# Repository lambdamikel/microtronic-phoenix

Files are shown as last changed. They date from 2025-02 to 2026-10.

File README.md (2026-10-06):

# microtronic-phoenix

## The Microtronic Phoenix Computer System - A  Microtronic Emulator Running the Original Firmware from 1981

### [Jason T. Jacques](https://jsonj.co.uk/): TMS1xxx emulator, prototype hardware design and breadboarding, refined Microtronic firmware dumping, authentic Microtronic firmware emulator running the original Microtronic firmware ROM with a TMS1600 emulator

### [Decle](https://forums.atariage.com/profile/46336-decle/): TMS1xxx firmware ROM dumping technology, TMS1xxx disassembler, expert technical advisor 

### [Michael A. Wessel](https://www.michael-wessel.info/): Arduino-based re-implementation of the Microtronic, first round of Microtronic firmware dumping, PCB design, software integration 

## About

*The *Microtronic Phoenix* represents a quantum leap in Microtronic
emulation.*

The Microtronic was an educational 4bit single-board computer system,
which was released in 1981 by the company [Busch
Modellbau](https://www.busch-modell.de) in West Germany: 

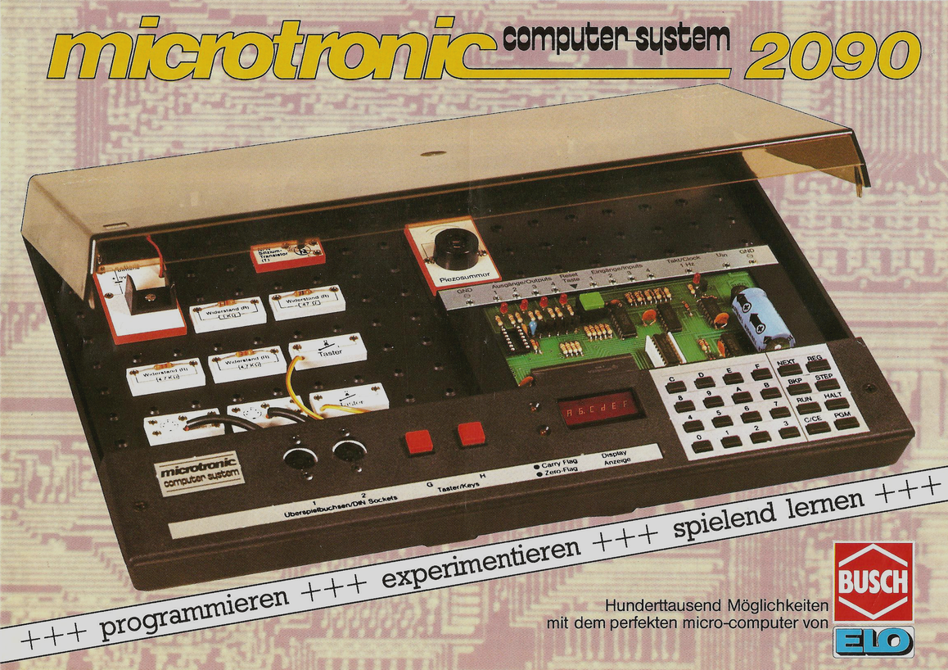
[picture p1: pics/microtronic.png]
Microtronic


Unlike [previous hardware
emulators](https://github.com/lambdamikel/Busch-2090) of the [1981
Busch 2090 Microtronic Computer
System](https://www.busch-modell.de/information/Microtronic-Computer.aspx
), the Phoenix emulator is the first emulator that is not only a
re-implementation of the Microtronic, but actually runs the original
TMS1600 firmware from 1981.

This breakthrough was made possible by a collaboration of
[Decle](https://forums.atariage.com/profile/46336-decle/), [Jason
T. Jacques](https://jsonj.co.uk/) and [Michael
Wessel](https://www.michael-wessel.info/), referred to as "the team"
in the following.

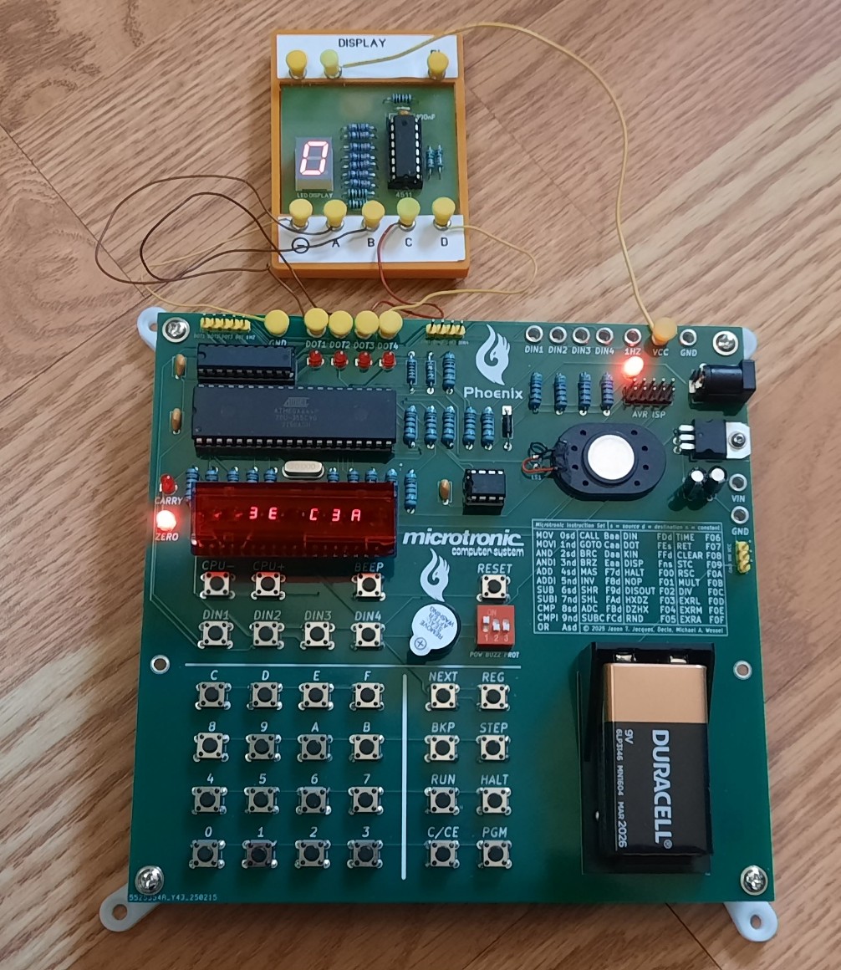
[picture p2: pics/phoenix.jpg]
Phoenix


This project is shared with the community to enable others to relive
and experience the original 1981 Busch Microtronic Computer System
in an as-authentic-as-possible way.  

## Latest News

- 10-05-2026: A Microtronic emulator that runs in your web browser is now online. It runs the original
  1981 firmware ROM on an emulated TMS1600, with the program RAM, display, keypad, inputs,
  outputs and 1 Hz clock modelled at pin level behind a console drawn from photos of the real
  machine, and it comes with a library of programs from the manuals. Everybody can now
  experience the Microtronic - there is nothing to build, and nothing to load or install on
  your computer: just open the page. Made with Claude Code (Opus 5.5).
  It uses the same firmware ROM as the Phoenix, with Jason's TMS1xxx emulator as the reference for the CPU.

    **[https://lambdamikel.github.io/microtronic-emulator/](https://lambdamikel.github.io/microtronic-emulator/)**

    Source code: [https://github.com/lambdamikel/microtronic-emulator](https://github.com/lambdamikel/microtronic-emulator)

  Microtronic Emulator

- 09-06-2026: The Busch 2094 "Computerspiele" booklet is now available in English as well -
  25 games and experiments to program yourself on the Microtronic 2090, from Black Jack and
  Roulette to a chess clock, a code lock and a prime-number benchmark:

    [https://github.com/lambdamikel/microtronic-2090-manuals-english](https://github.com/lambdamikel/microtronic-2090-manuals-english)

- 07-29-2026: A translated and updated all-in-one version of the article series about
  the German Educational Computer Systems from the 1980s (including the Microtronic and Phoenix) 
  I had written for the LOAD retro-computer magazine is available now: 
  [https://github.com/lambdamikel/german-educational-computers-of-the-80s](https://github.com/lambdamikel/german-educational-computers-of-the-80s)

- 07-09-2026: Part 2 of the Microtronic manuals in English is available now: 

    [https://github.com/lambdamikel/microtronic-2090-manuals-english](https://github.com/lambdamikel/microtronic-2090-manuals-english)

- 06-08-2026: Using Claude Code (Opus 4.8), we have translated the
first part of the Microtronic manuals to English! You can find
the PDF and HTML versions here:

    [https://github.com/lambdamikel/microtronic-2090-manuals-english](https://github.com/lambdamikel/microtronic-2090-manuals-english)

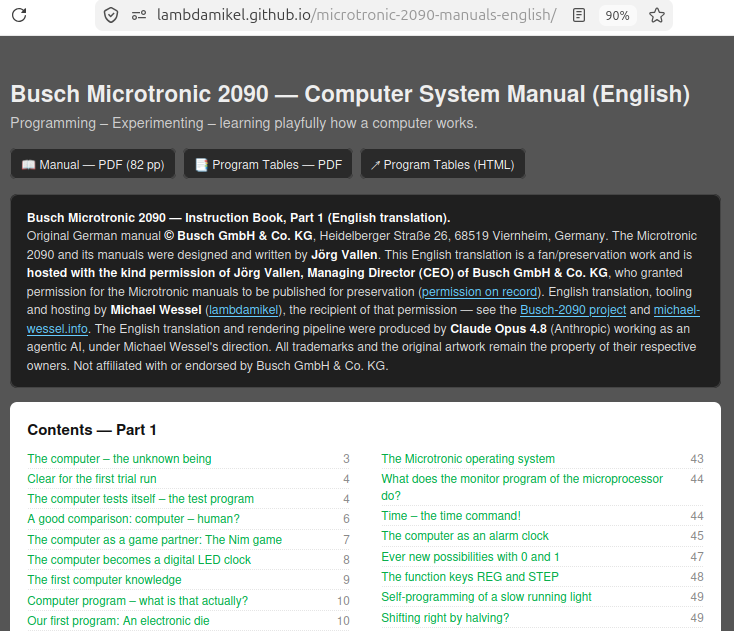
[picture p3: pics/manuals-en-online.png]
Translated Manual English
  

  Part 2 will follow soon, as well as the "Computerspiele" booklet. 

- 10-03-2025: I have written an article about the Busch Microtronic and its
emulators for the the "LOAD" magazine of the German organization for
the preservation of classic computers ("Verein zum Erhalt klassischer
Computer (VzEkC)") - you can download the [PDF of the "LOAD#11" free
of
charge](https://www.classic-computing.de/wp-content/uploads/2025/10/load11web.pdf).
There are also still print editions available for purchase.

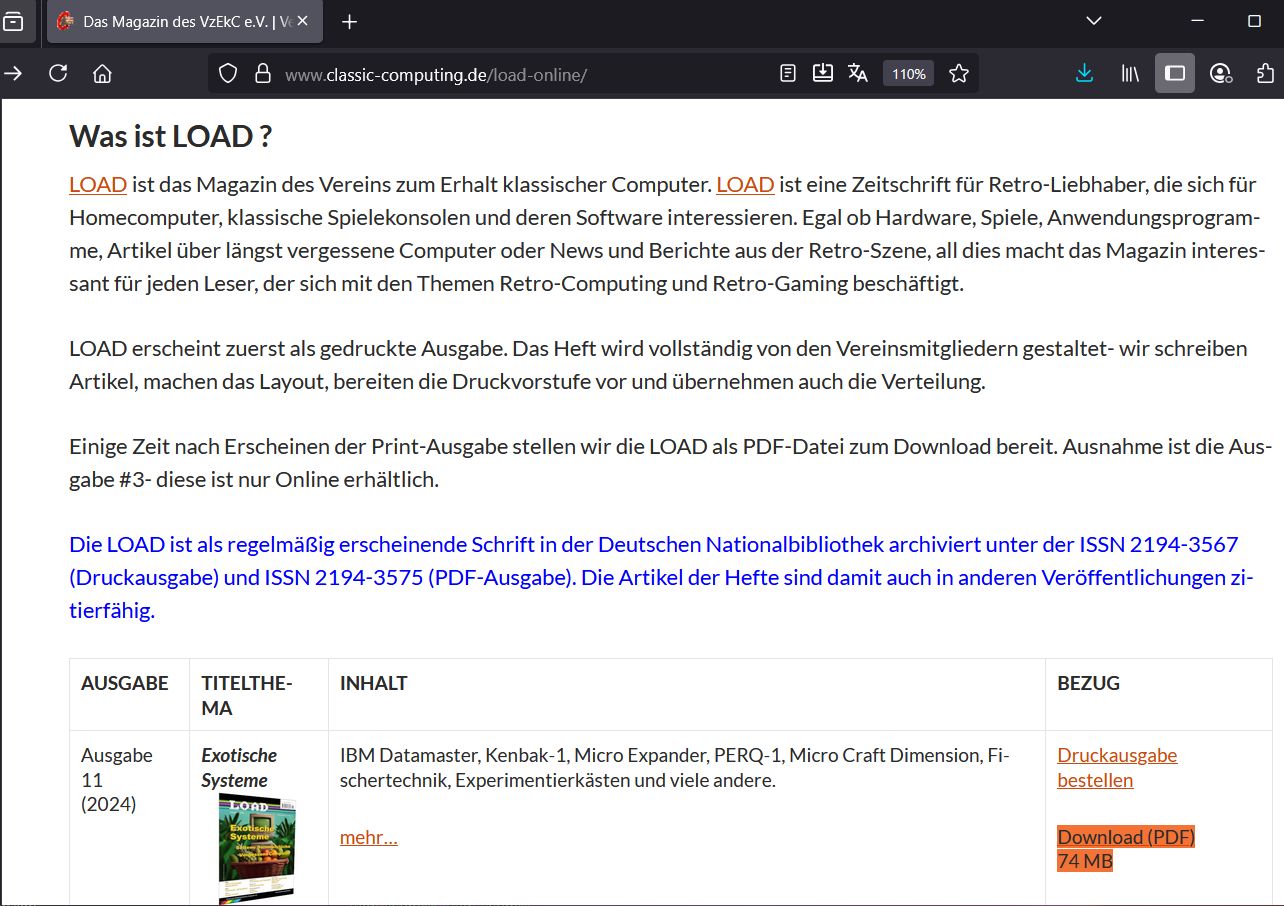
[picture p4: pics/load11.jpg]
Load 11 - A

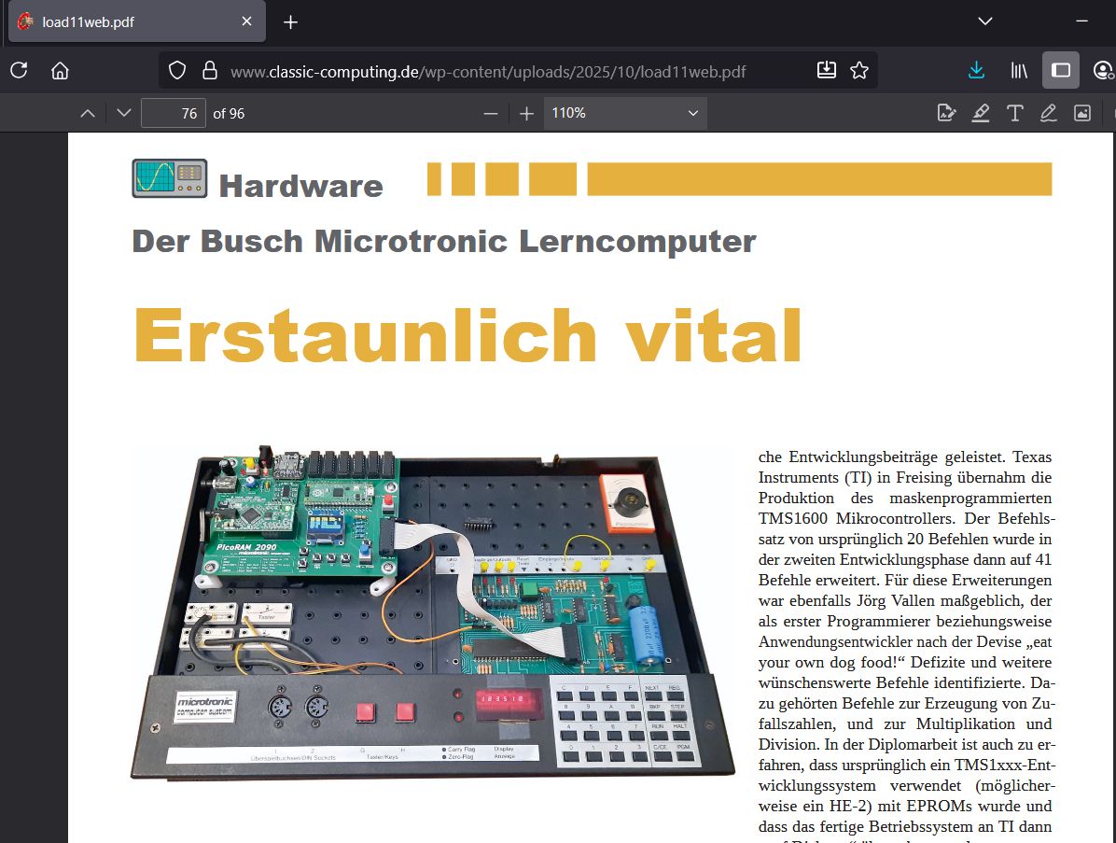
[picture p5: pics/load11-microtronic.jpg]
Load 11 - B


This article is the last in a series of three about the three major
educational computer systems available in the first half of the the
1980s in Germany: the Busch Microtronic, the Kosmos CP1, and the
Philips MasterLab MC6400. Busch played a pivotal role here, since they
released the first such system and literally created the market for
such systems in Germany. The overview and article covering the Philips
Masterlab can be found in ["LOAD#10" (free PDF
download)](https://www.classic-computing.de/wp-content/uploads/2024/10/load10web.pdf).
The Kosmos CP1 is also in "LOAD#11", together with the Microtronic
article.

- 08-23-2025: Phoenix enthusiast 
[`venice1200`](https://github.com/venice1200) determined how to
maximize the contrast of the 3661AS LED displays. He is using two
filters layered on top of each other - a black and a red one. The
contrast is stunning; see the following pictures for black+red, black
only, red only, and no filter:

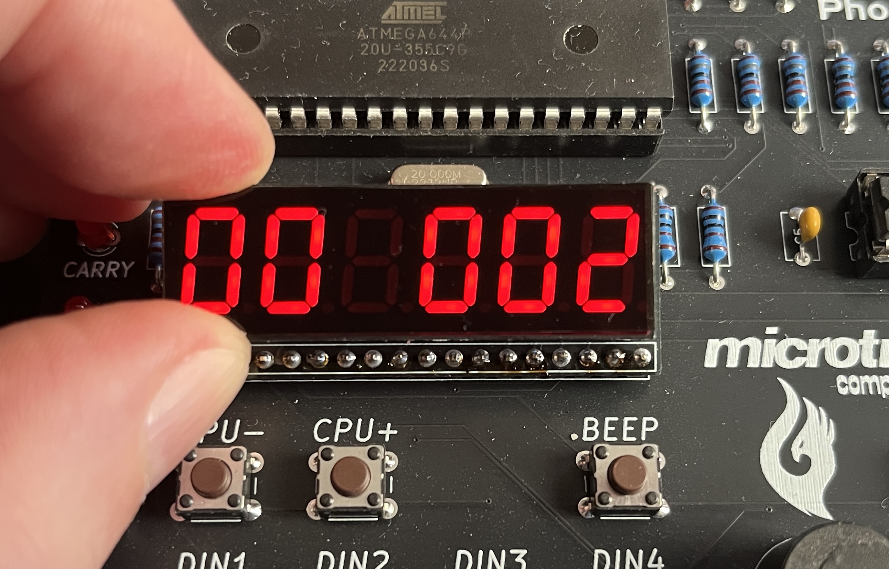
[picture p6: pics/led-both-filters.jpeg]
LED filter black and red


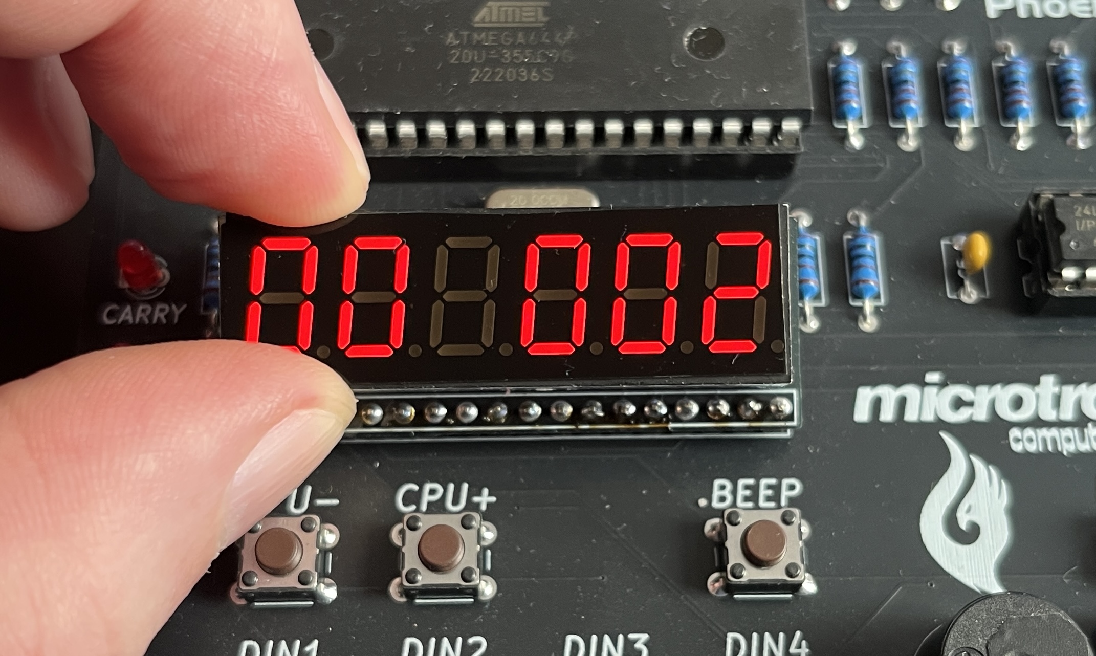
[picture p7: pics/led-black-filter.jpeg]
LED filter black


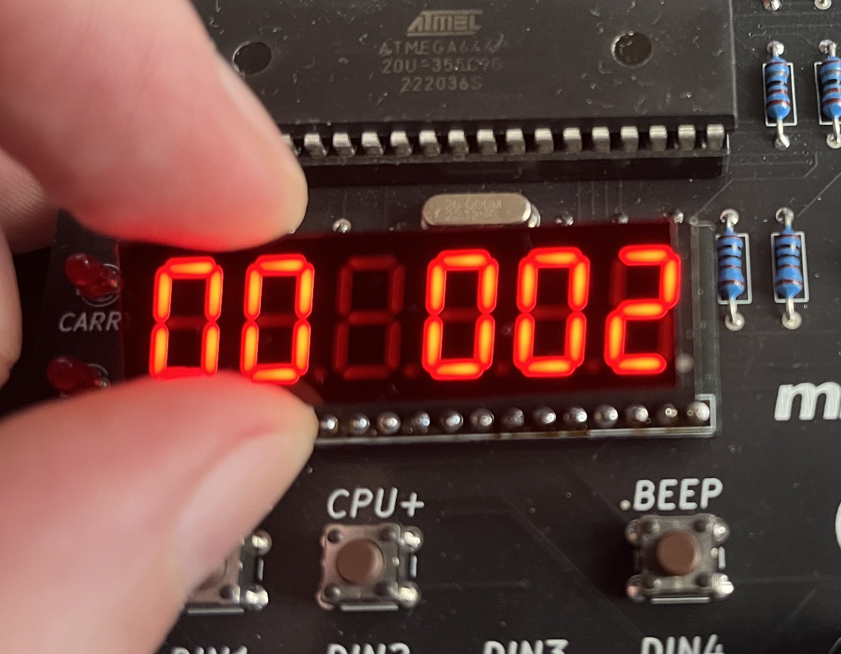
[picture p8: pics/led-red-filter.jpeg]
LED filter red


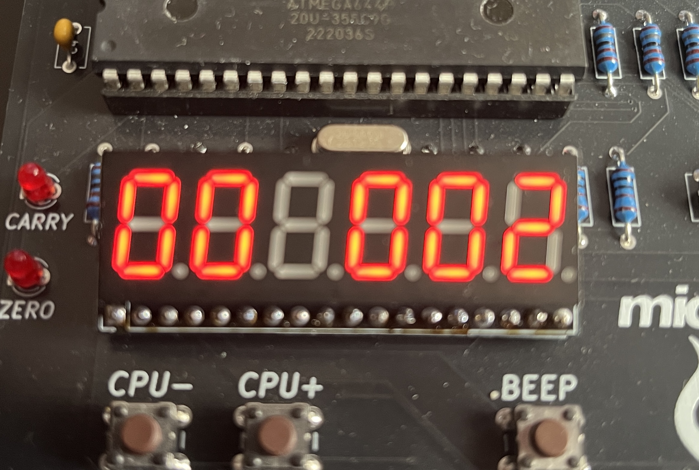
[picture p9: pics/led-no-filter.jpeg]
LED filter red


- 08-17-2025: [Github user
`venice1200`](https://github.com/venice1200) has created a [2095
cassette interface emulator
descendant](https://github.com/lambdamikel/microtronic-2095-arduino-emulator)
that allows for direct upload of programs to the Microtronic (or
Phoenix) via an Arduino-based USB connection from the PC (no SD card
required). On the PC side, a Python script is used to transfer MIC
files directly into a Microtronic / Phoenix running the `PGM 1`
program loader. An Arduino Nano is used for the USB connection. Check
out [the project
Github](https://github.com/venice1200/Retro/tree/main/Microtronic_Phoenix)
for more details about this great project. Thanks for sharing it with the
public, `Venice1200`!

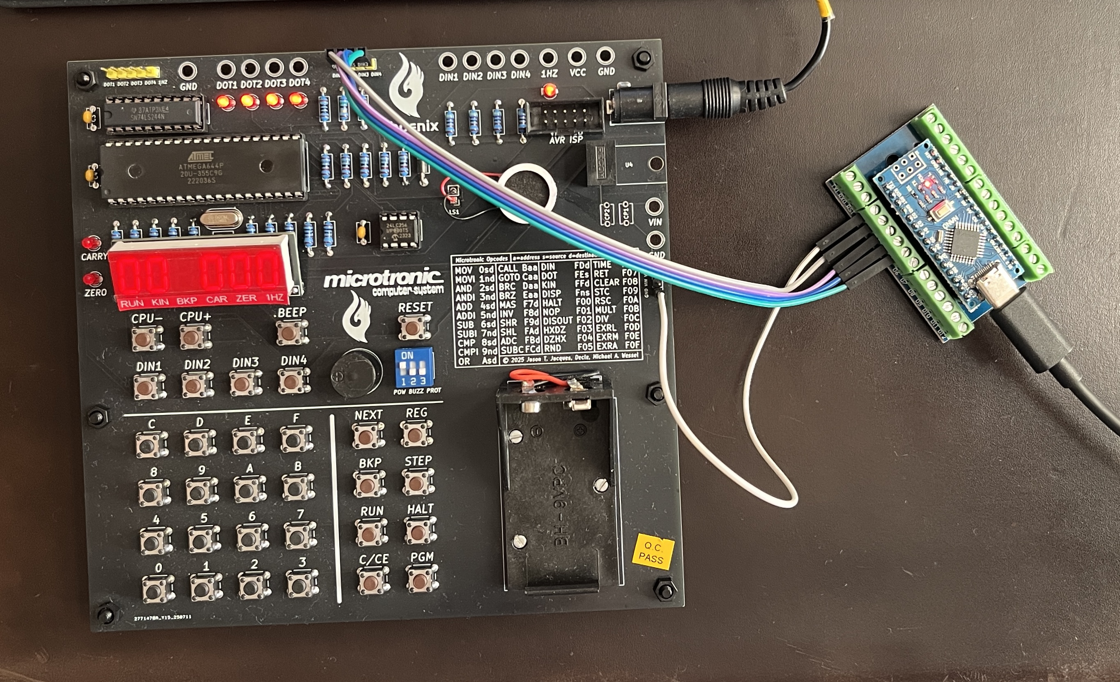
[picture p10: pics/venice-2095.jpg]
Venice1200 2095 Uploader


- 08-12-2025: In the meantime, a number of Makers have successfully
built their own Phoenix. I am sharing the builds of Venice and Morky
from the [Classic
Computing](https://forum.classic-computing.de/forum/index.php?thread/34844-microtronic-phoenix-edition/&pageNo=1)
Forum here:

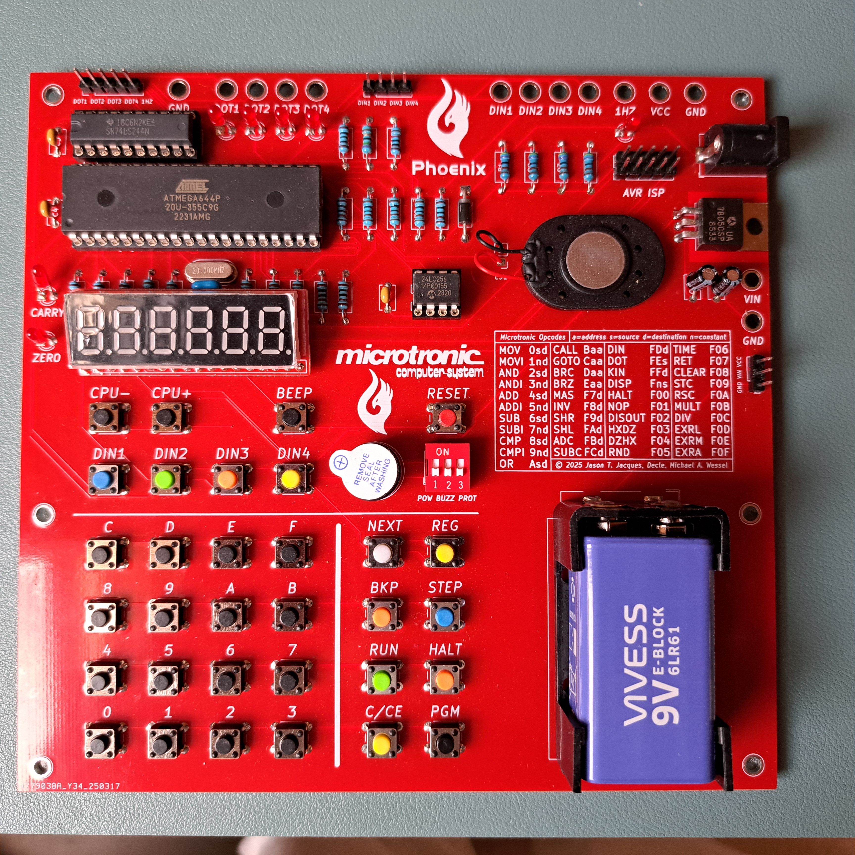
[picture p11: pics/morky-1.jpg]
Morcky


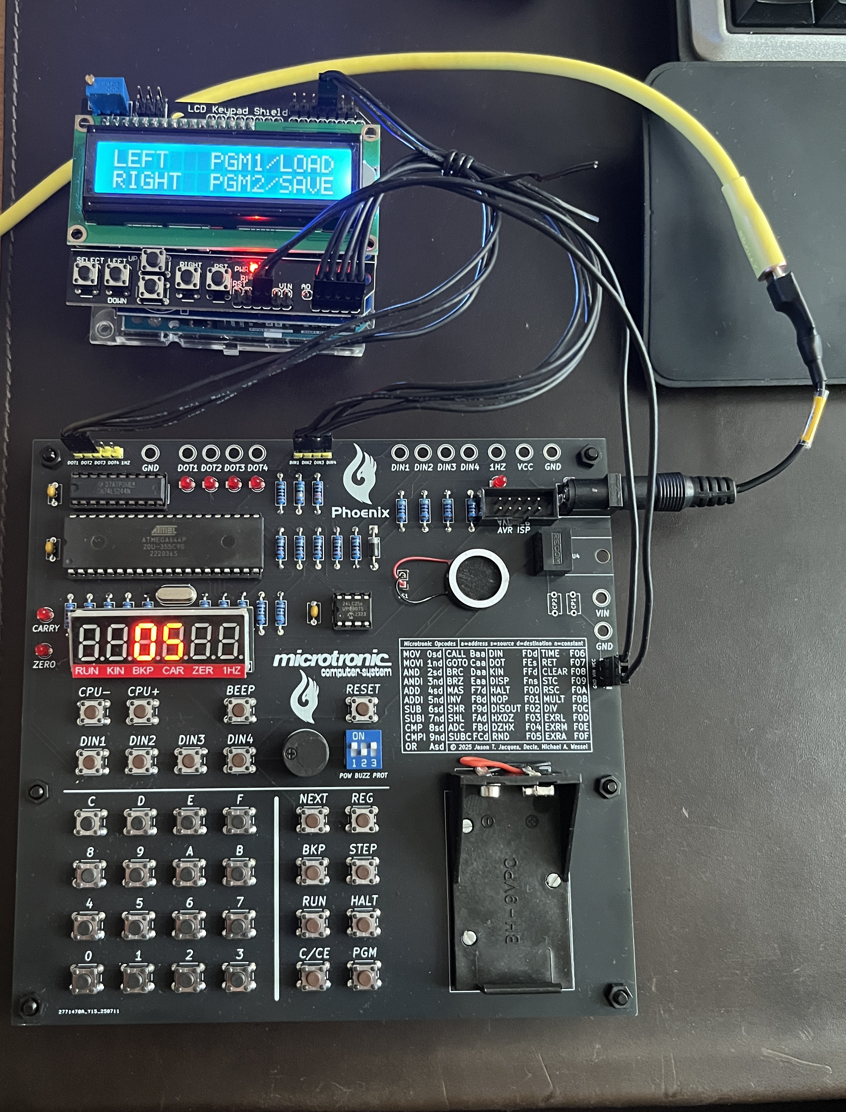
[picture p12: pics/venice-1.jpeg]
Venice 1


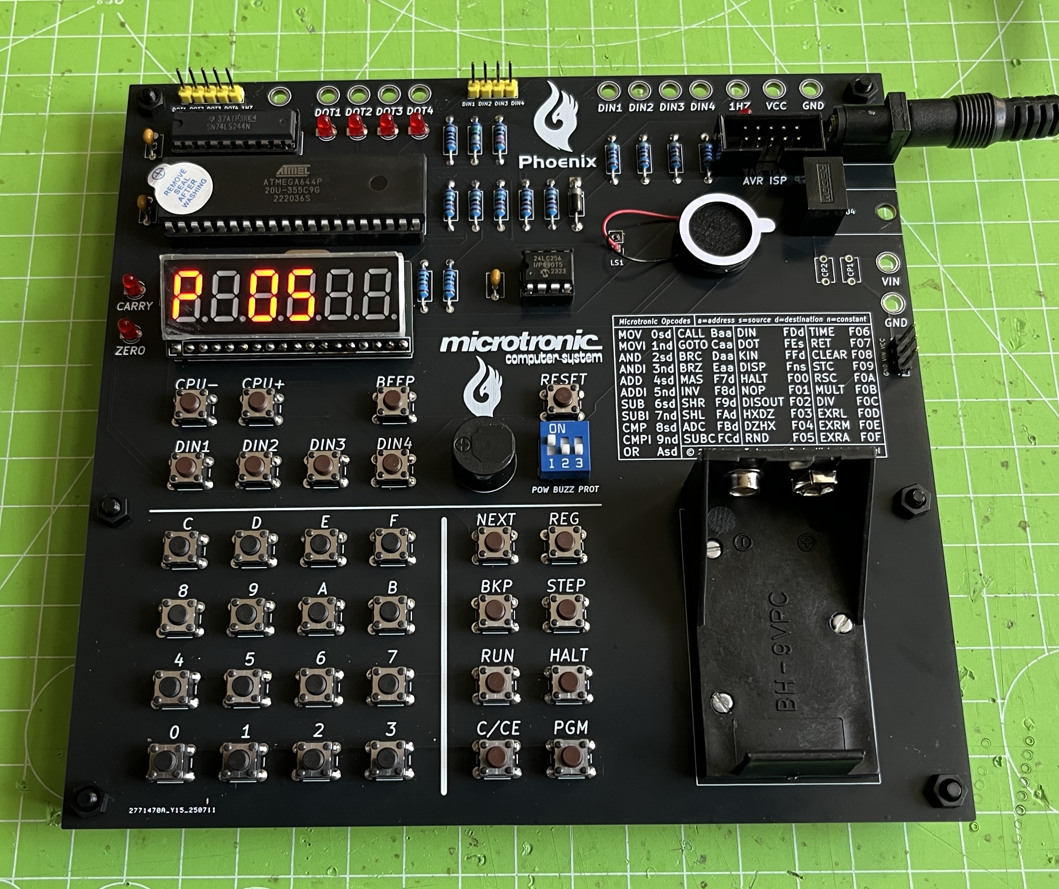
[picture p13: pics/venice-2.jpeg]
Venice 2


- 04-17-2025: [Hackster.io](https://www.hackster.io/news/the-four-bit-busch-microtronic-lives-again-as-the-microtronic-phoenix-complete-with-original-rom-2a5c7ccecba7) has also featured the Microtronic Phoenix project - thanks to Gareth Halfacree!

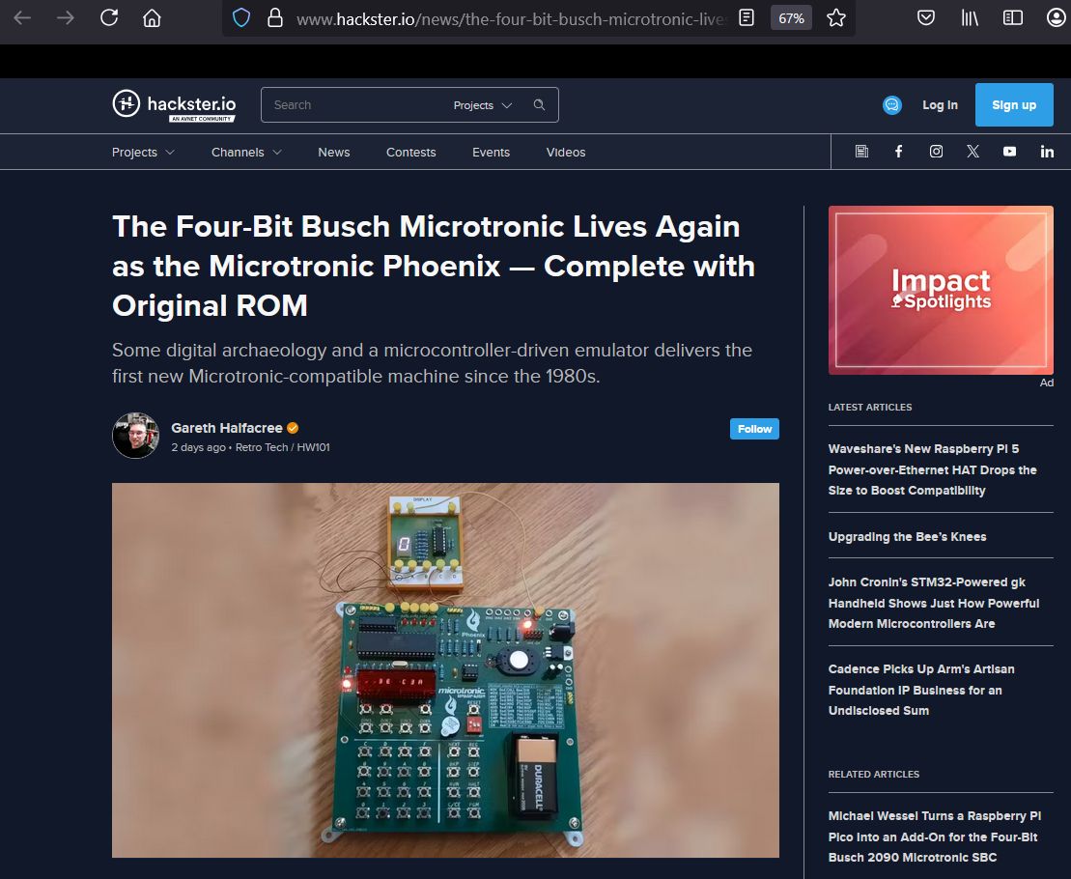
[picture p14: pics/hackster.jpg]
Hackster
  

- 04-14-2025: Phoenix in the News: [Microchip
  Makes](https://x.com/MicrochipMakes/status/1911773123323515386)
  posted about our project, and the Phoenix is also on the [Hackaday
  front page](https://www.hackaday.com) as a "Featured Project"

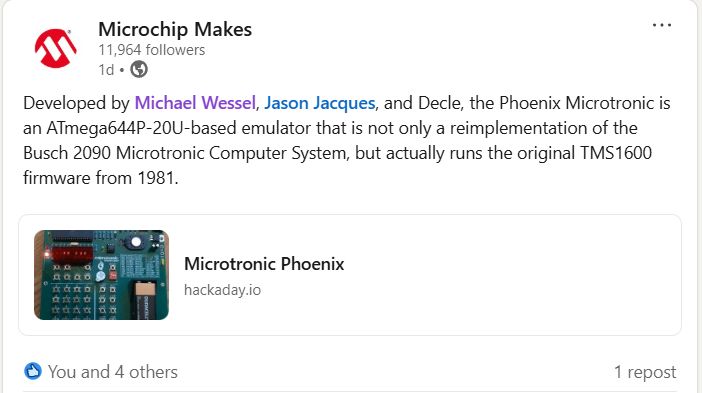
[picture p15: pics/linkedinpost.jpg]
Linkedin
  

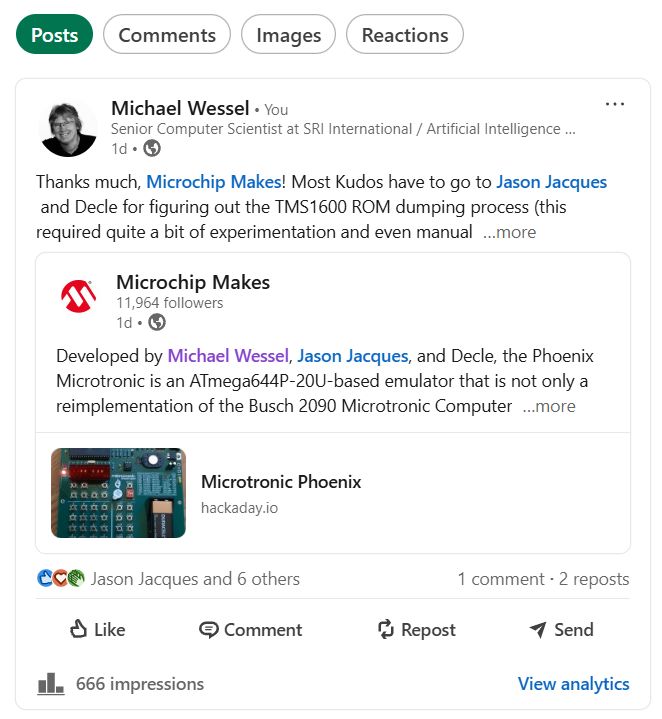
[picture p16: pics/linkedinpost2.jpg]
Linkedin 2
  

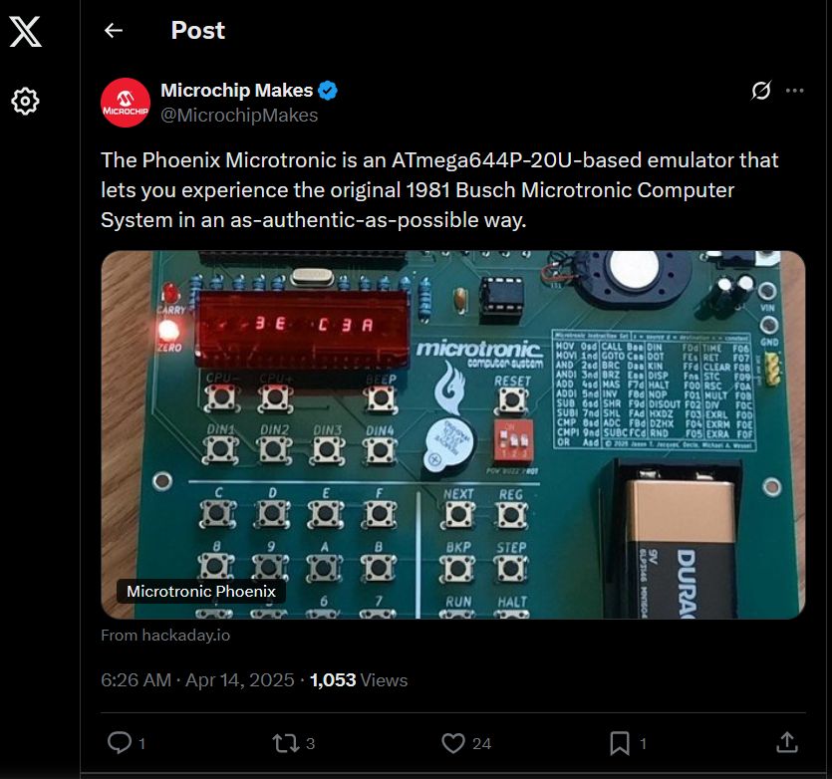
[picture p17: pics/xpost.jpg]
XPost
  

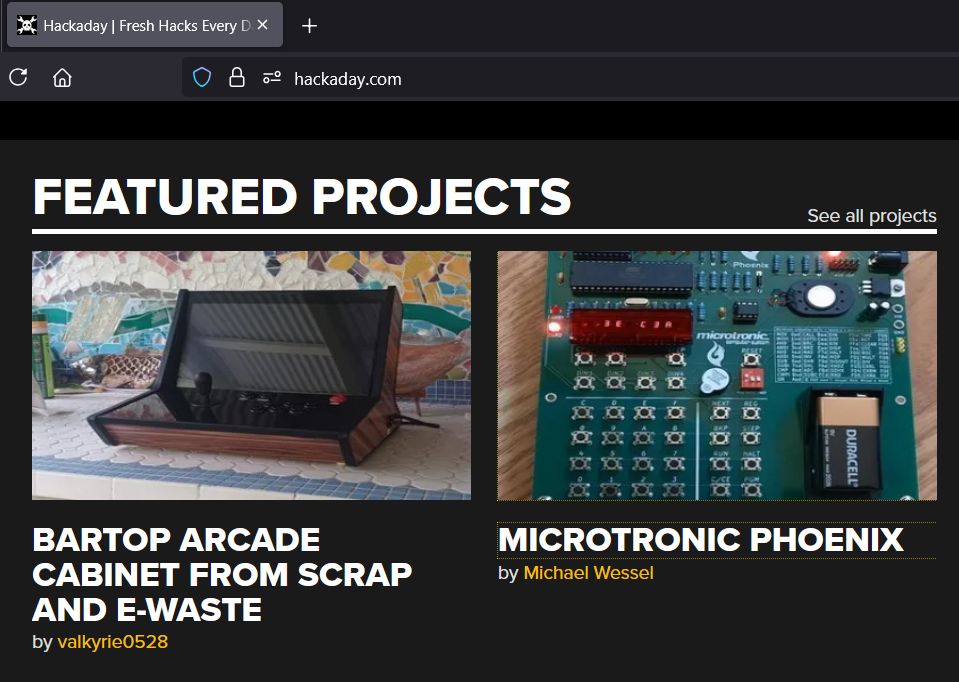
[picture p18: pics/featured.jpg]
Hackaday Featured
  

- 04-12-2025: All Firmware variants uploaded ("Phoenix", "Neo Only", "Phoenix Only"). 

- 02-22-2025: "Neo Only" firmware uploaded. 

## Background & Genesis

The Microtronic is powered by a mask-programmed Texas Instruments 4bit microcontroller,
the TMS1600.

Until now, an authentic Microtronic emulator was impossible as the
official firmware had been lost to history, and there was no
documented procedure for reading out ("dumping") a TMS1600 firmware
ROM. Firmware ROMs of related TMS1xxx devices (e.g., the SIMON game,
TI calculators, and the Science Fair Microcomputer Trainer) had been
retrieved in the past, but the process usually involved [destructive
die-decapping](https://seanriddle.com/decap.html).

More recently, an alternative to destructive chip decapping was
discovered for dumping the ROM of the [1985 Radio Shack Science Fair
Microcomputer
Trainer](https://hackaday.io/project/194876-exploring-the-science-fair-microcomputer-trainer).
This process utilizes an Arduino for [putting the TMS1xxx into the
so-called *test
mode*](https://hackaday.io/project/194876-exploring-the-science-fair-microcomputer-trainer/log/227981-dumping-the-tms1100),
which then allows download of the firmware ROM over a serial interface. 

After a lot of trial-and-error, the team finally succeeded in April
2024 in retrieving the Microtronic firmware ROM, hence opening up the
avenue of re-creating the original Microtronic on modern hardware. The
process is described
[here](https://hackaday.io/project/197415-microtronic-firmware-rom-archaeology)
and, much more detailed and technically accurate,
[here.](https://jsonj.co.uk/project/microtronic/)

After Decle and Michael had succeeded in enabling the TMS1600 test
mode (this process was nowhere documented on the Internet back then),
and succeeded in downloading a first version of the Microtronic ROM,
Jason then took the lead and analyzed and double checked it, corrected
some errors by hand (despite all our efforts, the retrieved firmware
still contained some ambiguity!), and, for the first time in history,
created an [ATmega-based breadboard Microtronic running the original
firmware](https://jsonj.co.uk/project/microtronic/#the-breadboard-microtronic)
on his TMS1xxx emulator!

Jason's work of curating the firmware and his TMS1xxx Microtronic
breadboard hardware emulator opened the avenue of recreating a
retro-authentic new version of the Microtronic on modern hardware,
running the original 1981 firmware ROM on a TMS1600 emulator on an
Arduino / ATmega.  **We are hence calling this new Microtronic
hardware emulator the Phoenix.**

## Phoenix Overview 

The Phoenix board uses an ATmega 644P-20U clocked at 20 MHz, a 24LC256
EEPROM, and an 74LS244 in an abundance of pre-caution for connecting
the ATmega's GPIOs to the external world of Microtronic INPUT / OUTPUT
ports.

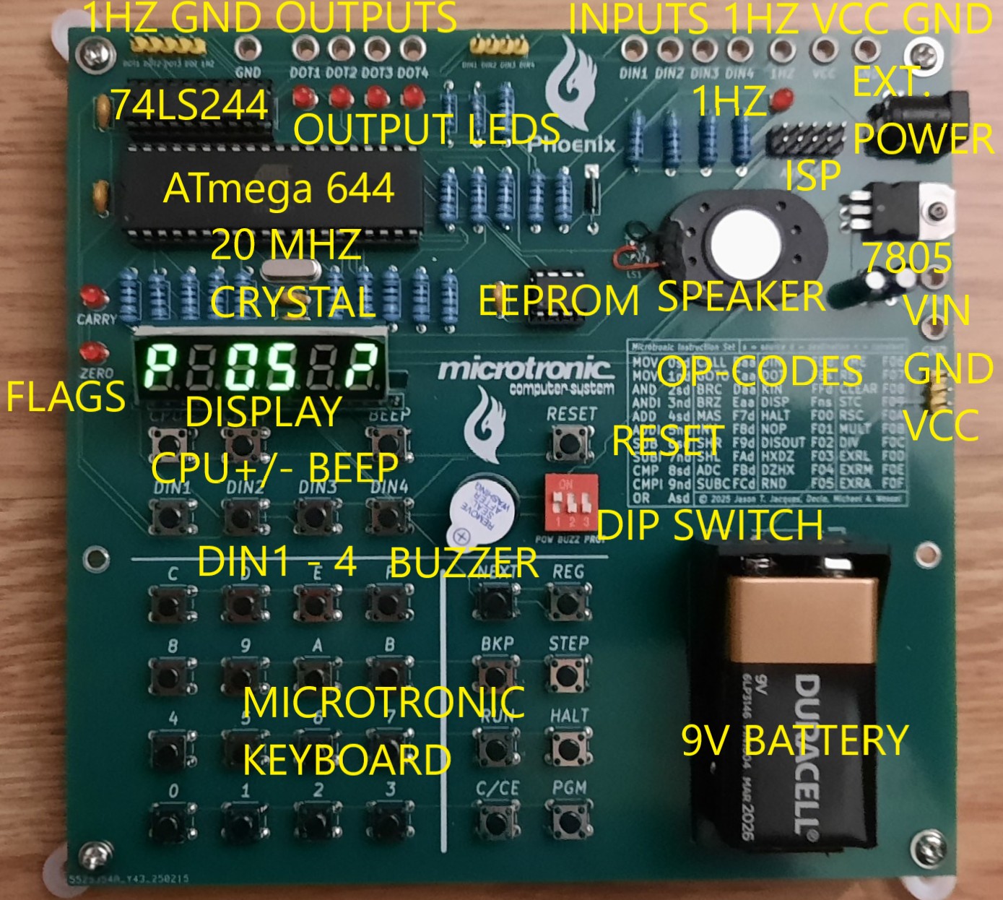
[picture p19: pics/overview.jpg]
Phoenix Overview


The three different Phoenix firmwares are provided as Arduino folders
/ "sketches". See below for descriptions of these three different
variants. The [Arduino Legacy IDE IDE
1.8.19](https://www.arduino.cc/en/software) in combination with
[MightyCore](https://github.com/MCUdude/MightyCore) are used for
firmware compilation and uploading onto the Phoenix board over the ISP
header (see below).

One can either use an original 6digit 7segment (or really 8segment if
we include the individual decimal dots for each digit) TIL 393-6
retro-authentic bubble LED display from Texas Instruments, or the NSA
1166 from National Semiconductors as shown in the above picture. As
these are hard to come by, it is also possible to use a CL3061AG or
SH3661AS modern LED display and an adapter (provided here as well): 

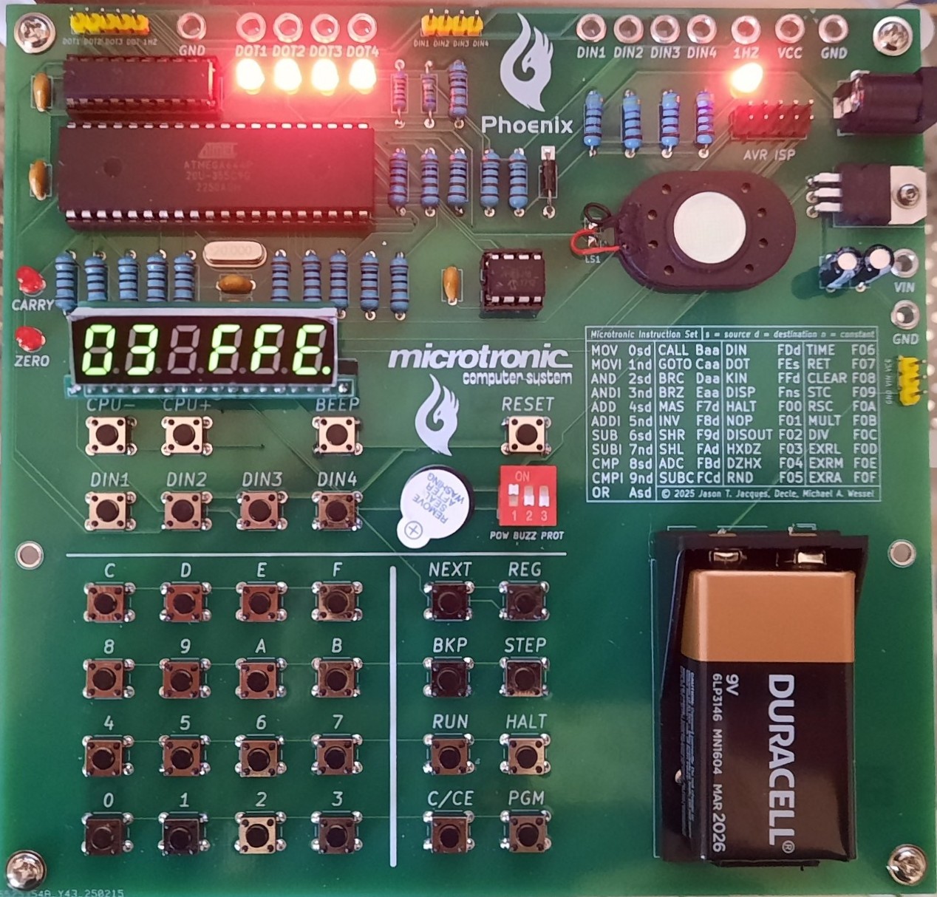
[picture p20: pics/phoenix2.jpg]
Prototype with Display Adapter


## Original Microtronic Firmware

The original Microtronic firmware can be found [here](microtronic-firmware/).

The files are provided for reference and interest only, and are not
required for programming the Phoenix firmware. The Phoenix firmware
sketches are self-contained, and the [Microtronic firmware ROM
image](microtronic-firmware/microtronic.bin) is embedded on the
code-level (instead of on the file level) in them.

## Emulation Modes - NEO vs. PHOENIX 

The Phoenix offers two Microtronic emulation modes:

- the **Neo Mode** is based on [Michael's Arduino-based re-implementations of the Microtronic
in C](https://github.com/lambdamikel/Busch-2090), 
and similar in spirit to the [Retro-Authentic Bubble LED Display Microtronic.](https://hackaday.io/project/180252-a-retro-authentic-microtronic-rc-202110-winner) 
- the **Phoenix Mode** is based on [Jason's breadboard Microtronic running the original Microtronic ROM on his TMS1xxx emulator.](https://jsonj.co.uk/project/microtronic/#the-breadboard-microtronic)

The Phoenix is offered with *three different firmwares:*

- [Neo Only:](microtronic-phoenix-neo-only/) only offer the Neo Mode
  (describe below).

- [Phoenix Only:](microtronic-phoenix-only/) only offer the Phoenix
  Mode (described below).

- [Combined:](microtronic-phoenix/) **should be the default**; this
offers both modes; upon boot or reset (via the `RESET` button), the
user can select the firmware of choice for the "**P**hoenix **OS**" -
"**P OS ?**"; here, push **1** for NEO, and **2** for PHOENIX:

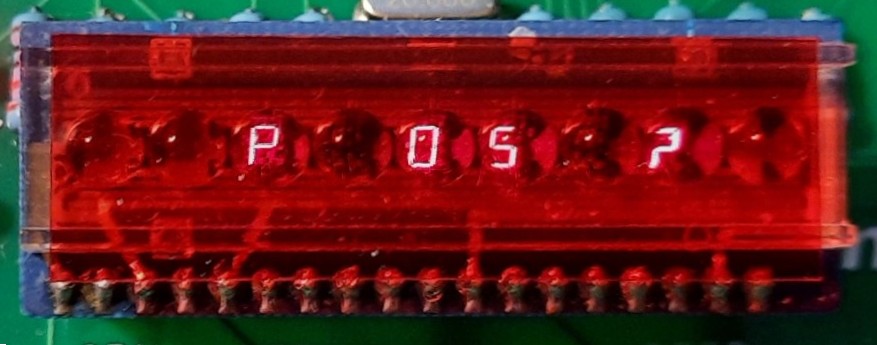
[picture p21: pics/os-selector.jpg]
Prototype
  

### Common Hardware Features

The Phoenix board offers a number of additional hardware features, in
particular, an on-board buzzer, and 4 additional push buttons `DIN1`
to `DIN4`. 

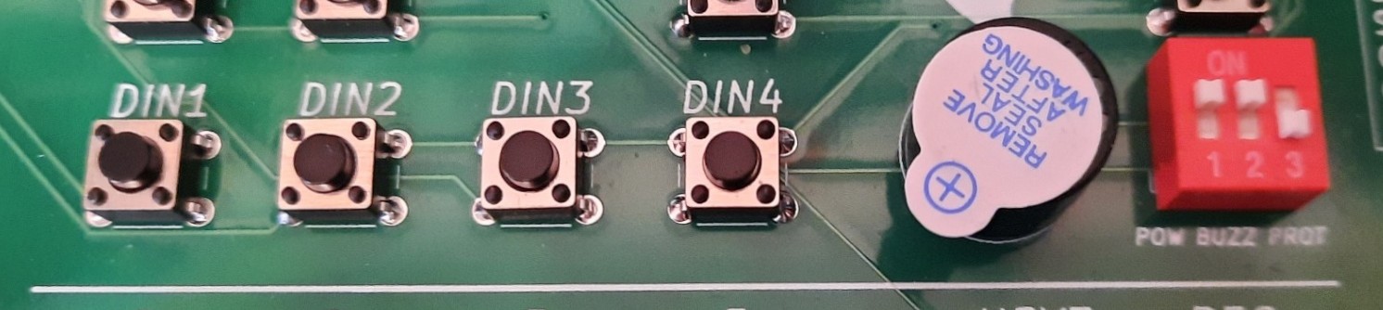
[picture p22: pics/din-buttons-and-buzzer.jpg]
DIN Buttons


The original Microtronic came with a buzzer as well as two push button
("G" and "H") which, in many experiments, where connected to the
digital inputs (DIN), and the buzzer was usually connected to either
DOT Output 1 or 4, as shown in this picture: 

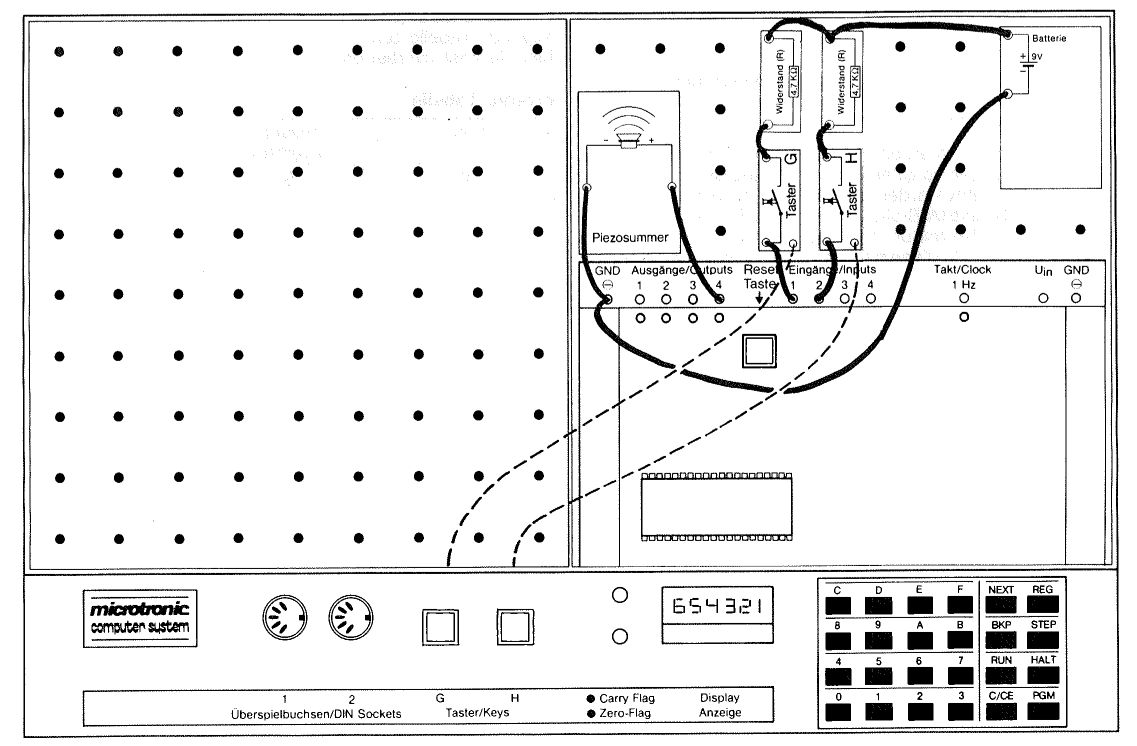
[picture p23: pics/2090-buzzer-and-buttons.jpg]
Microtronic Console
 

The Phoenix board hence offers these on-board, for convenience (plus
two extra-buttons, `DIN3` and `DIN4`). The on-board buzzer can also be
disconnected via the `BUZZ` DIP switch.

Moreover, both the Neo and Phoenix mode support the CPU speed buttons:
emulation speed can be decreased (`CPU-`) and increased ( `CPU+`). The
`RESET` button works in both firmwares as well: 

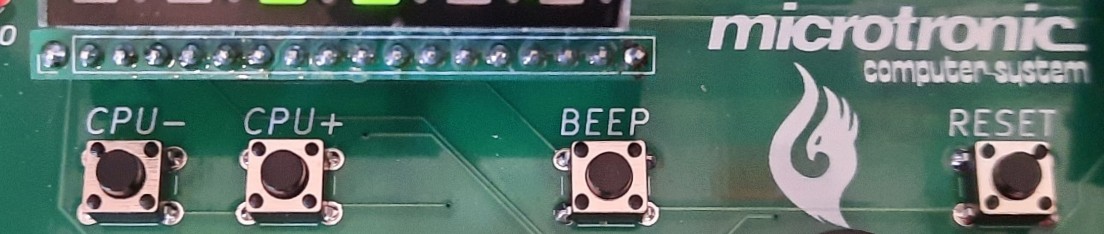
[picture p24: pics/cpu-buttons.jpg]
CPU and Reset Buttons
 

### Neo Mode

In Neo Mode, the hardware emulator has access to the additional
hardware features on the board: 

- a **speaker** for sound output: like in previous Microtronic
emulator versions, [vacuous op-codes are used as sound
op-codes.](https://github.com/lambdamikel/Busch-2090?tab=readme-ov-file#emulator-sound-output-and-sound-instructions)

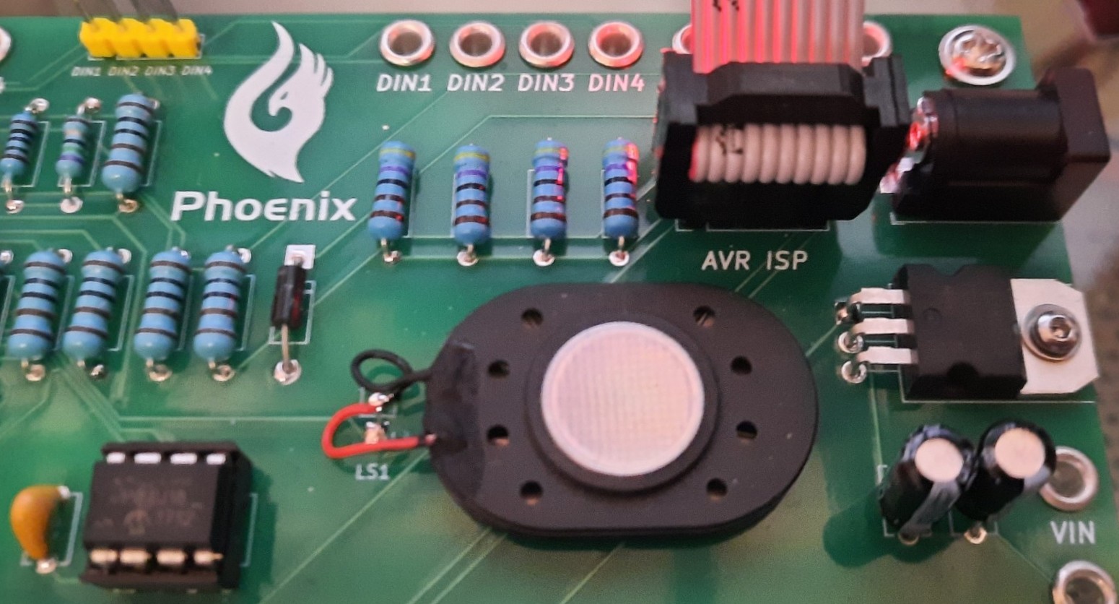
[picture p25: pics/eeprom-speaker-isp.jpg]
Speaker and EEPROM
  

- an 256 kBit 24LC256 **EEPROM** for mass-storage of Microtronic RAM
  dumps, instead of the 2095 cassette interface. The EEPROM has enough
  space for 42 complete memory dumps. It is accessed via `PGM 1` and
  `PGM 2`. **NOTE: to save to or load from the EEPROM, the `PROT`ect
  switch must be in OFF position!**. Turn the `PROT`ect switch back on
  after EEPROM operation. See this picture:

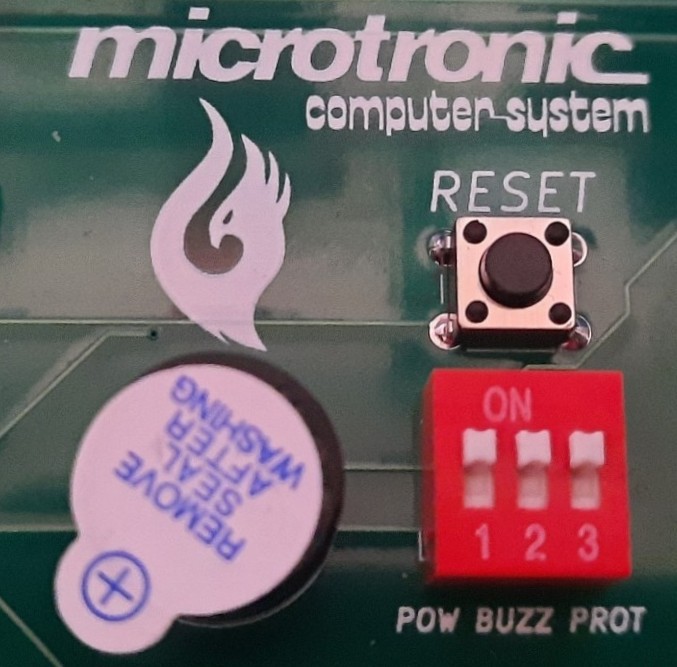
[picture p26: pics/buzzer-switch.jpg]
DIP SWITCH
  

  **Please note that the `CARRY` LED will not work properly with the
  `PROT` switch in OFF position.**

- the speaker is also used for key beeps; the `BEEP` button is used to
  turn on or off key beeps.

- 7segment status display: with a suitable 7segment LED display that
offers control over the individual digit decimal dots (the NSA 1166
from National Semiconductors does not, but the TIL 393-6 from TI
does), the 6digit 7segment display also indicates the CPU emulator
state, as well as the `CARRY`, `ZERO`, and `1 Hz` CLOCK flags (in
addition to the LEDs on the board). The `BEEP` button is used to turn
on or off this status display - this is a feature which is independent
of the display's main function as the primary visual user interface. 

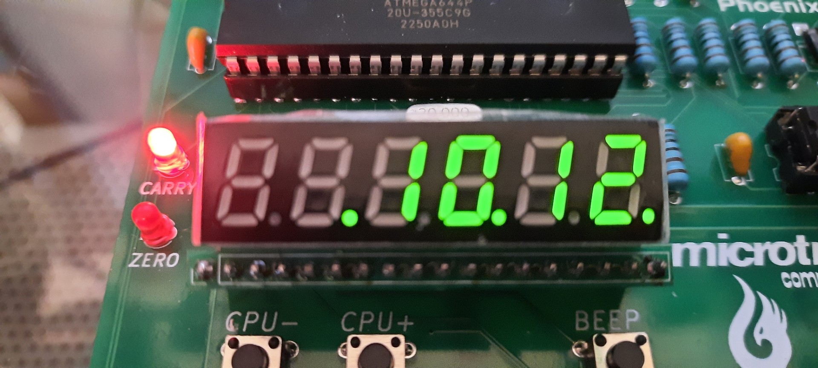
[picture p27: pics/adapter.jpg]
Status DOTs
   

  The status decimal dot LEDs are, from left to right: 
  - Dot on digit 6: program running
  - Dot on digit 5: requesting user input (`KIN` active) 
  - Dot on digit 4: breakpoint active (`BKP`) 
  - Dot on digit 3: `CARRY` flag
  - Dot on digit 2: `ZERO` flag  
  - Dot on digit 1: `1 Hz` clock

  The NSA 1166 only supports control of the decimal dot for digit 3;
  hence, only the `CARRY` flag can be visualized with it.

  It should again be noted that, if in OFF position, the `PROT`ect
  switch disables the main `CARRY` flag LED (left to the 7segment
  display). However, utilizing the second `CARRY` flag indicator (the
  decimal dot of digit 3) we can hence leave the `PROT`ect switch in a
  permanent OFF position without loosing `CARRY` flag visibility. And,
  this also works with the NSA 1166.
  
  Also note that two NSA 1166 / TIL 393-6 adapters are provided in this
repo (see picture above): one for the [CL3061AG display](gerbers/gerbers-til-display-adapter.zip), and one for the [SH3661AS display](gerbers/gerbers-til-display-adapter2.zip). The bubble LED display are getting very hard to source these days.    

The Neo firmware contains the following `PGM` programs; these are: 

- ``PGM 1`` : Load program from EEPROM
- ``PGM 2`` : Save program to EEPROM 
- ``PGM 3`` : Set clock 
- ``PGM 4`` : Show clock 
- ``PGM 5`` : Clear memory
- ``PGM 6`` : Load ``F01`` (NOPs) into memory 
- ``PGM 7`` : Nim Game 
- ``PGM 8`` : Towers of Hanoi (up to 4 disks - see https://github.com/lambdamikel/towers-of-hanoi) 
- ``PGM 9`` : Electronic Die (Microtronic Manual Vol. 1, page 10) 
- ``PGM A`` : Three Digit Counter (Microtronic Manual Vol. 1, page 19) 
- ``PGM B`` : Moving LED Light (Microtronic Manual Vol. 1, page 48) 
- ``PGM C`` : Digital input DIN Test Program
- ``PGM D`` : Lunar Lander (Moon Landing) Game (Microtronic Manual Vol. 1, page 23) 
- ``PGM E`` : Prime Numbers ("Computerspiele 2094", page 58) 
- ``PGM F`` : 17+4 BlackJack Game ("Computerspiele 2094", page 32) 

Note that, on the original Microtronic and hence in Phoenix mode, `PGM
0` performs a self-test, and `PGM 1` and `PGM 2` are used to access
the 2095 Cassette Interface, which is currently not supported by the
Phoenix board. Instead, `PGM 1` and `PGM 2` are used to access
the EEPROM. 

Moreover, there are no `PGM` demo programs `8` to `F` in Phoenix mode.

### Phoenix Mode

In this mode the system behaves identical to the original Busch
Microtronic, executing the original Microtronic firmware using Jason's
TMS1600 emulator! Hence, [the original Busch
manuals](https://github.com/lambdamikel/Busch-2090/tree/master/manuals)
are the best documentation. It is currently only available in German,
but contemporary GenAI technology will likely have little problems
translating it to English.

Note that the **Phoenix runs ~ 30 to 40 % faster than the original
Microtronic,** but still **significantly slower than in Neo mode at
max speed.**

The digital inputs and outputs are fully functional, and even the
original `PGM 1` and `PGM 2` firmware ROM programs are working.
They can be used for accessing the [2095 cassette interface
emulator.](https://github.com/lambdamikel/microtronic-2095-arduino-emulator)
Here is [a video demonstrating operation of the original 2095 cassette
interface](https://youtu.be/7KmG64e4DPE), and [a 2095 emulator
tutorial by "Mein Elektronic Hobby" (in
German)](https://youtu.be/0MPBtOWTzlk) for first steps with
`PGM 1` and `PGM 2`.

Moreover, unlike the Neo version, the self-check `PGM 0` firmware ROM
program is functional, and can be used for checking proper operation
of the system, see [User Manual Vol. 1, pp. 5 -
6](https://github.com/lambdamikel/Busch-2090/blob/master/manuals/anl2090-1.pdf])
(note that a test harness is required for `PGM 0` operation).

Please note that the `RESET` button is supported, but **the `CPU-`,
`CPU+`, and `BEEP` buttons are non-functional in this mode. They only
work in Neo mode.**

### Combined Mode

**This should be considered the default firmware - it combines the features
of the Neo and the original firmware.** 

In addition to the individual features of the Phoenix and Neo modes as
just described, the combined mode realizes one more *essential
synergistic feature* making this mode more than the sum of its
individual modes: **shared Microtronic program memory!** In this
way, the Phoenix mode can take advantage of the additional features
of the Neo mode, like EEPROM access or additional PGM demo programs. 

For example, to load a program from EEPROM into Phoenix, we would

1. start in Neo mode, load a Microtronic program from EEPROM via `PGM 1`.
2. switch to Phoenix mode: push `RESET`, enter `2`.
3. the same program is now available in Phoenix mode.

In general, all changes made to the current Microtronic program in memory
will always be available to the other mode as well. 

You can also load one of the additional demo `PGM`s easily into Phoenix mode.

1. start in Neo mode, load a `PGM` ROM program, for example, "17Add4 Blackjack":
`HALT-PGM-F`. 
2. switch to Phoenix mode: push `RESET`, enter `2`.
3. play Blackjack in Phoenix mode: `HALT-NEXT-0-0-RUN`. 

## The Phoenix Board

In principle, the Phoenix is a one-chip design - everything is driven
by the ATmega 644P-20U, even the display. The 24LC256 EEPROM is
optional; the machine will also work without it. The 74LS244 is used
to electrically decouple the Microtronic inputs and outputs from the
ATmega and make it more robust for experimentation in case an
experiment goes awry. It is cheaper and easier to replace the 74LS244
than the ATmega.

### Phoenix Power Supply Options 

There are four options of powering the Phoenix board: 

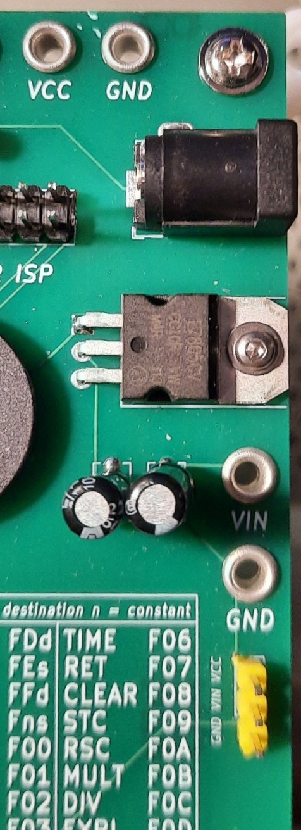
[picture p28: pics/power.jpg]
Power Supply Options
 

1. With a 9V block battery. The power switch must be in ON position.

2. With an external 9V to 15V DC power supply over the standard
center-positive 2.5 mm power jack. A 0.5A supply is sufficient.
The power switch must be in ON position. 

3. Over the `VIN` and `GND` rivet sockets. The power switch must be in ON
position.

4. Over the AVR ISP header. **In this case, the power switch should be
in OFF position!**

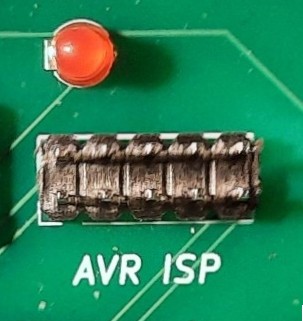
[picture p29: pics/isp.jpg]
ISP Power
 

For options 1 to 3, a 7805 voltage regulator is used to down-regulate
the input voltage to the required 5V level.

Note that it is not necessary to remove the 9V battery from the
Phoenix if another power supply option is used - a standard 1N4001
rectifier diode prevents all current flow (and hence "charging"
attempts) into the 9V battery from the external power supply.

### Phoenix `VCC`, `VIN`, and `GND` Outputs

For powering electronics experiments with Busch electronics kits
and/or breadboards, the Phoenix board can supply 5V via `VCC` as well
as 9V from the battery (or any voltage that the external power supply
provides) via `VIN`. The power switch must be in ON position to access
these voltages. Both `VCC` and `VIN` are available from rivet sockets
as well as pin headers.

Power Output Options 

### Display & Flags

The 6digit 7segment LED display is the primary visual output channel
of the Microtronic. It should be fitted with a red (or green) lens
filter to enhance the contrast.

Left of the display are the `CARRY` and `ZERO` flags.  Note that the
`CARRY` LED will only function if the `PROT`ect DIP switch is on `ON`
position. However, the NEO mode can utilize the decimal dot of the
third display digit from the right to visualize the `CARRY` flag as
well.

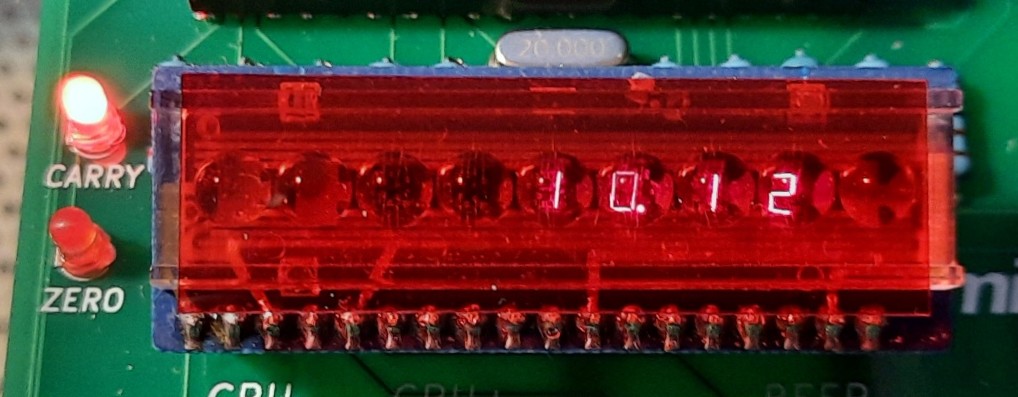
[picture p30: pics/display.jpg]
Display
 

### Inputs & Outputs

The Microtronic input and output ports are available in two form form
factors: as pin headers for DuPont cables (breadboard friendly), and
via classical Busch metal rivet sockets for the little yellow
connector pegs:

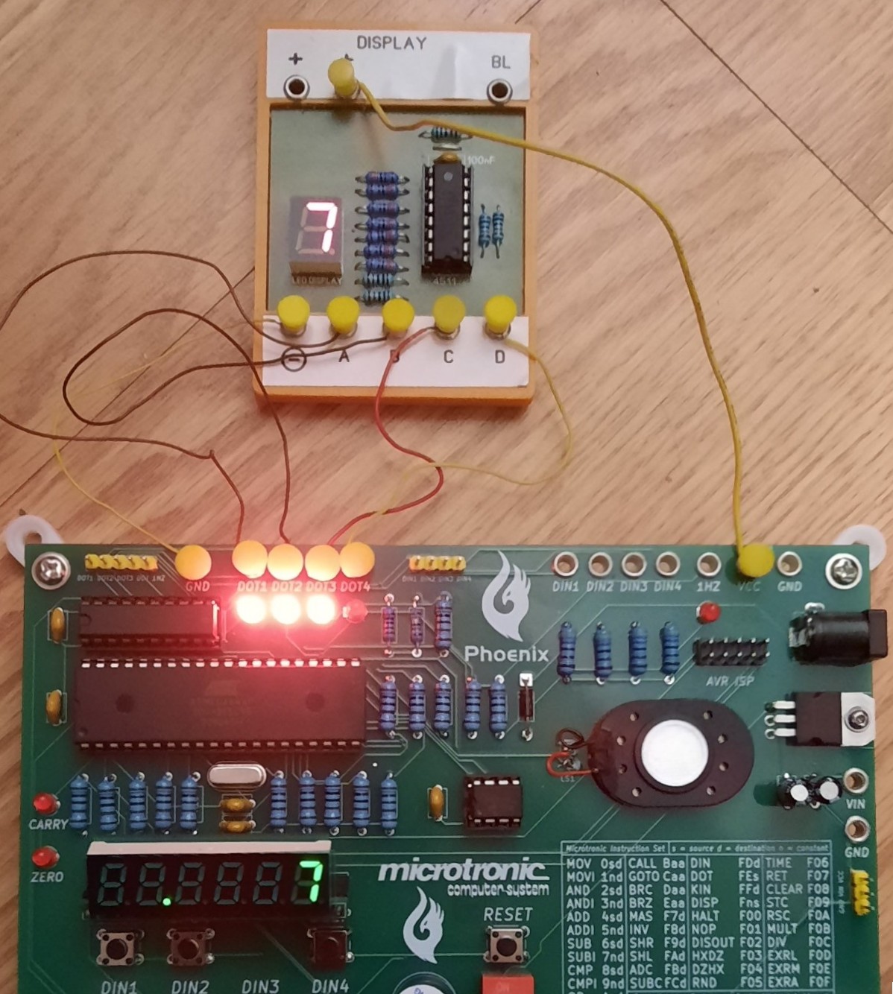
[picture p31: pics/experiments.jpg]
Busch Experiments, Yellow Pegs
 

These are the Microtronic outputs (they are controlled via the `DOT` = 
Data Out op-code); note that `GND` is available via a rivet socket,
and the `1 Hz` clock signal from the pin header:

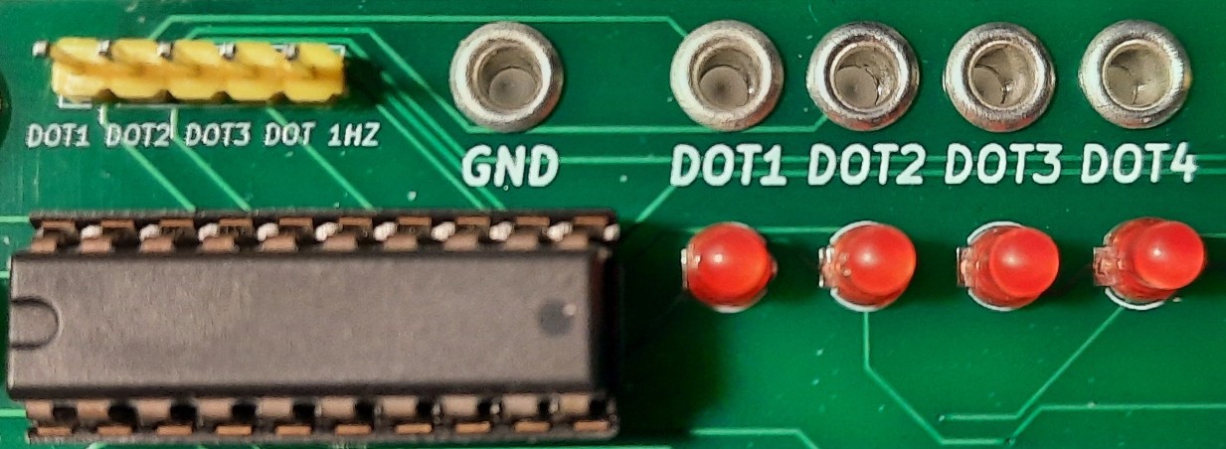
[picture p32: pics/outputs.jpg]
Microtronic Outputs


There are LEDs for the 4 Microtronic outputs, as well as an LED for
the `1 Hz` clock output. 

The Microtronic inputs (they can be read with the `DIN` = Data In
op-code) are available as pin headers and rivet sockets as well; also
note the `1 Hz` clock rivet and corresponding LED, as well as the
power supply socket rivets for external circuits / experiments:

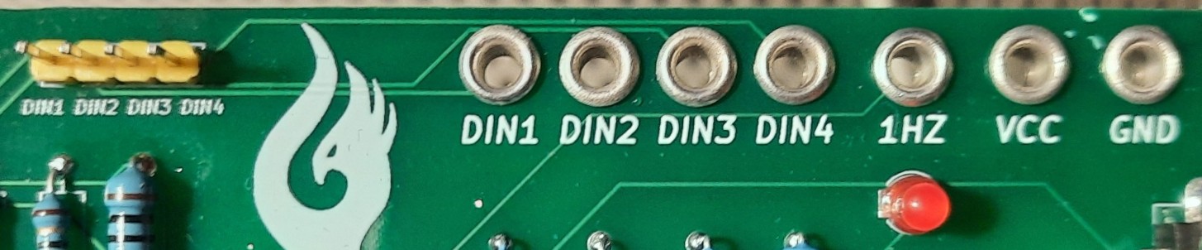
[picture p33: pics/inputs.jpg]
Microtronic Inputs


### Additional Hardware Features

The additional hardware features of the board have already been
discussed: the buzzer, the speaker, and the `DIN1` to `DIN4`
buttons. The buzzer can be switched off with the `BUZZ` DIP switch.

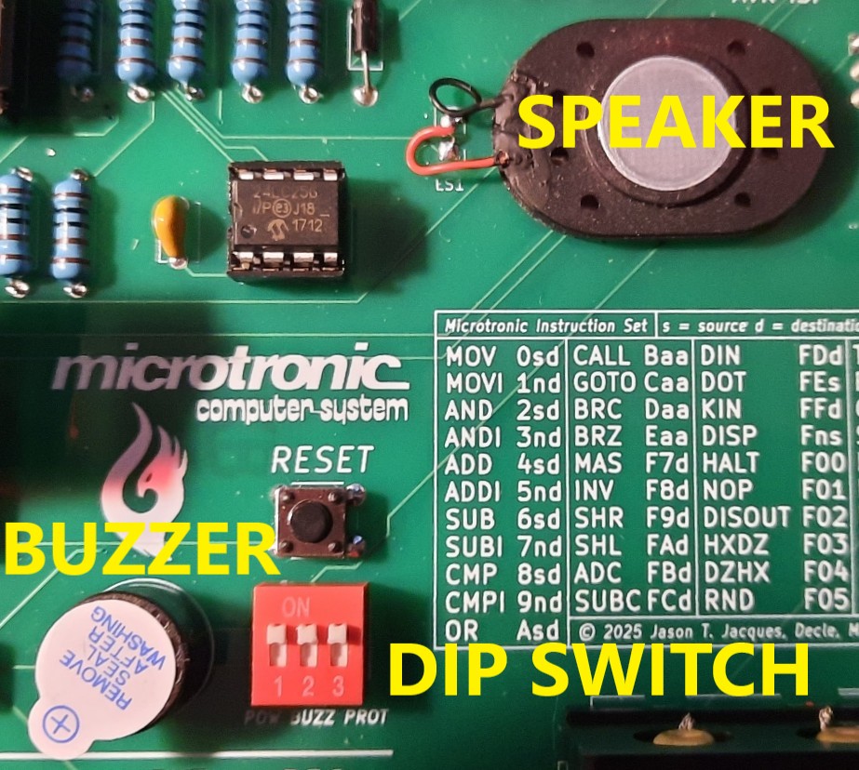
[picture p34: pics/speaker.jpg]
Speaker and Buzzer


### Phoenix and the 2095 SD Card-Based Cassette Interface Emulator 

The hardware emulation of the Phoenix is faithful enough to allow
interfacing with the [2095 cassette interface
emulator](https://github.com/lambdamikel/microtronic-2095-arduino-emulator).
Despite the availability of the much more comfortable EEPROM for
program storage, this is of some practical utility, as `.MIC` programs
can be loaded from and stored to SD card, and the FAT32 file system
facilitates convenient data exchange with the PC or Mac. Programs in
`.MIC` format can be found
[here](https://github.com/lambdamikel/Busch-2090/tree/master/software),
and loaded into the machine with the 2095 emulator, and then stored to
EEPROM as well, saving the user from having to type these in.

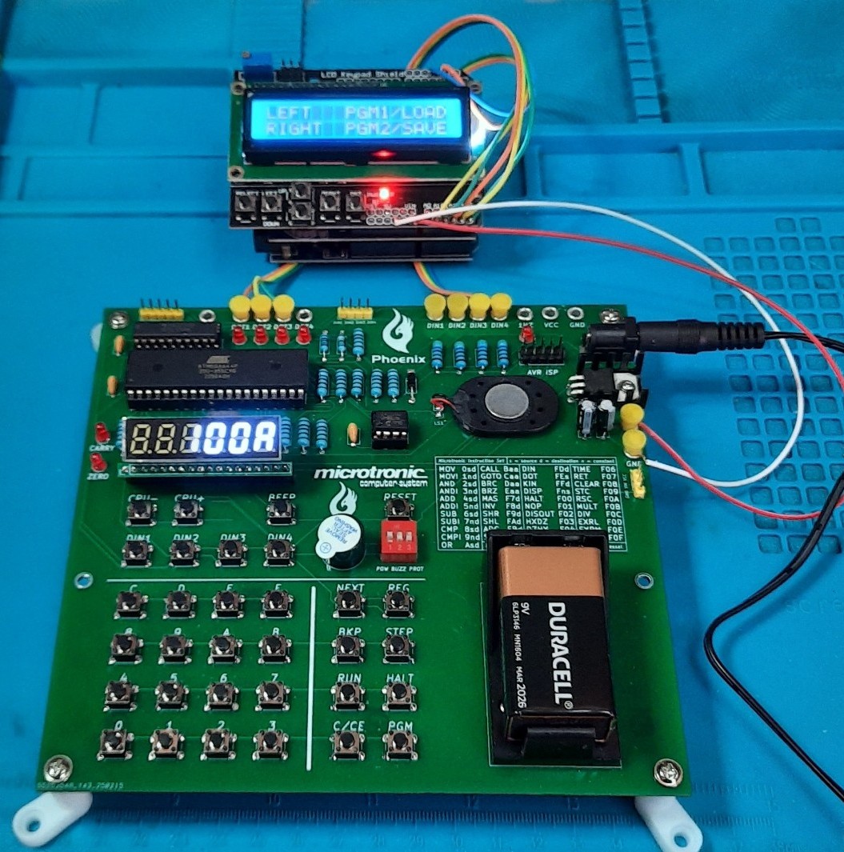
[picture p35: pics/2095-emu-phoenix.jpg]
Phoenix and 2095 emulator
 

Unfortunately, it is not possible to use [the real 2095 interface and
cassette recorder](https://youtu.be/7KmG64e4DPE), as Phoenix does not
generate the required 32.768 kHz clock signal that is the basis for
the tone generation that encode the 0 and 1 bits via [Frequency Key
Shifting](https://en.wikipedia.org/wiki/Frequency-shift_keying) on the
2095. The 2095 schematics - reconstructed by Frank de Jaeger - can be found
[here](https://www.rigert.com/ee-forum/download/file.php?id=5890);
there we can see that the 32.678 kHz signal generated by the
Microtronic provides the Phi1 clock signal to a [CD4060 14-Stage
Ripple-Carry Binary
Counter/Oscillator.](https://www.ti.com/lit/ds/symlink/cd4060b.pdf?ts=1741189915408&ref_url=https%253A%252F%252Fwww.google.com%252F)

### Bill of Material - BOM

- U1: ATmega 644P-20U + 40 Pin DIP Socket, 20 Mhz crystal and matching capacitors (2x 22 pF)
- U3: 74LS244 + 20 Pin DIP Socket 
- U4: 7805 + matching capacitors (e.g., 2x 22 uF electrolytic) 
- U6 (optional): 24LC256 + 8 Pin DIP Socket 
- DOT1-DOT4, CARRY, ZERO, 1HZ: 3mm diffused red LED of your choice, e.g., https://www.amazon.com/dp/B0DN1LXQYH
- 1N4001 Rectifier Diode 
- R1..R4: 4.7 k 
- R5..R9: 1 k - these should match the DOT1-DOT4 and 1HZ LEDs; for modern low-power LEDs such as the ones linked above, 1 k is quite bright (4.7 k might be better)
- R10..R11: 1 k - these should match the CARRY and ZERO LEDs; for modern low-power LEDs such as the ones linked above, 1 k is quite bright (4.7 k might be better)
- R12: 100 Ohm - should match the buzzer (reduces volume) 
- R13: 75 Ohm - should match the loudspeaker (reduces volume)
- R14..R20, R22 : 1 k - should match the LED display 
- R21: 10 k
- Speaker (optional): https://www.amazon.com/dp/B07LGKSRCK
- Buzzer (optional): https://www.amazon.com/dp/B01N7NHSY6
- 3-Position DIP Switch: https://www.amazon.com/dp/B0CSN9XDG5
- 5.5x2.1 Barrel Power Jack: https://www.amazon.com/dp/B081DYQSC9
- 6x6x5 Push Buttons: https://www.amazon.com/dp/B01CGMP9GY
- 6digit 7segment LED display with Common Cathode: https://www.aliexpress.us/item/3256803561087338.html, or TI TIL 393, NSA 1166
- 3x 103 (100 nF) capacitors (or 3x 104 / 1 uF - doesn't matter that much: https://hackaday.com/2025/01/25/capacitor-decoupling-chaos-and-why-you-should-abandon-100-nf/)
- breakable PIN headers, 2.54 mm pitch: https://www.amazon.com/HiLetgo-20pcs-2-54mm-Single-Header/dp/B07R5QDL8D
- 9V battery holder box: https://www.amazon.com/dp/B07Q1N2MHT
- Metal rivets: https://www.digikey.com/en/products/detail/keystone-electronics/46/316215
- M2 screws + nuts + washers: https://www.amazon.com/dp/B0BX96SMW4
- Mounting feet: https://www.amazon.com/dp/B07DHHS1Q8
- USPasp: https://www.amazon.com/dp/B0885RKVMC
- Heatsinks for the 7805 (optional): https://www.amazon.com/dp/B0CG91KN14

### Gerbers

The Gerbers for the Phoenix board

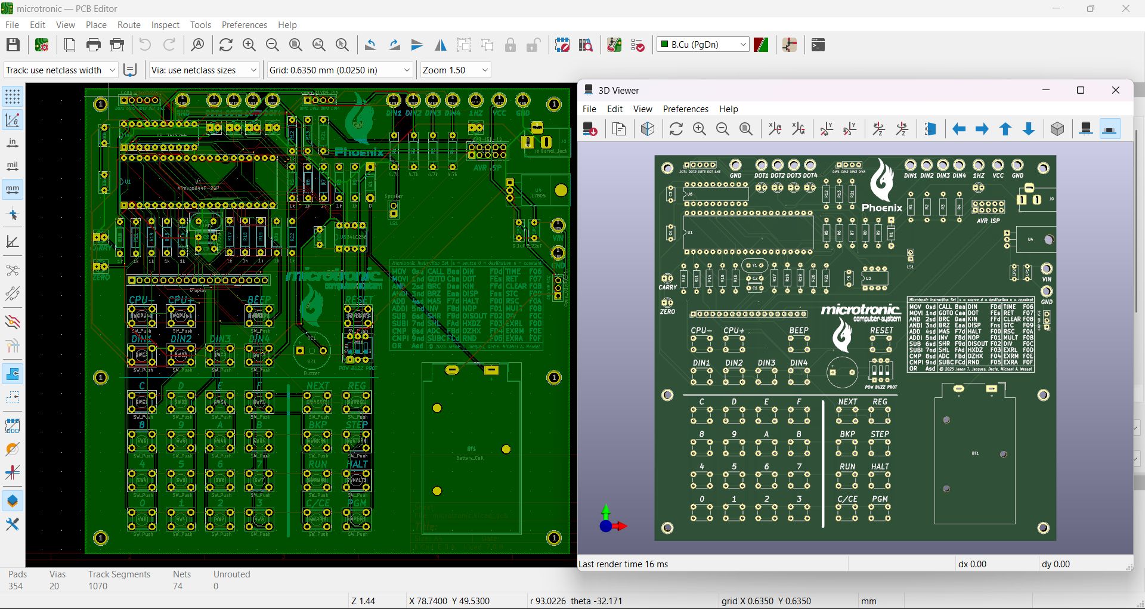
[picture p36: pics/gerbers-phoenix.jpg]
Phoenix Board


and for the display adapter 

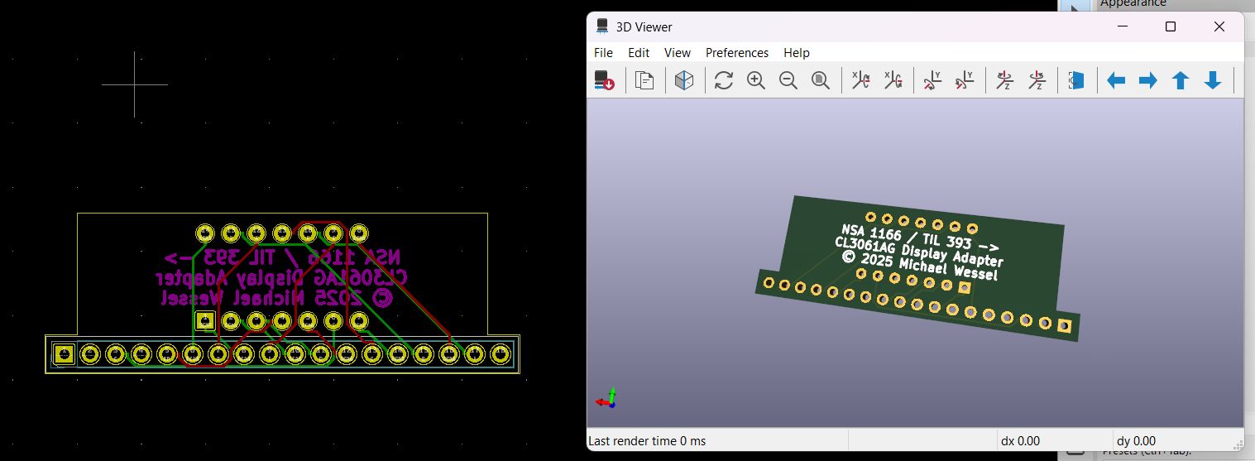
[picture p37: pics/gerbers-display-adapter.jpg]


are available:

- [Phoenix board](gerbers/gerbers-phoenix4.zip)
- [Adapter for CL3061Ax displays](gerbers/gerbers-til-display-adapter.zip)
- [Adapter for SG3661Ax displays](gerbers/gerbers-til-display-adapter2.zip)

## Phoenix Firmwares 

The firmware requires the Arduino IDE and a proper installation of 
[MightyCore](https://github.com/MCUdude/MightyCore).

Firmware uploading / programming is done "in system" via the ATmega
ISP header and, for example,
[USBasp](https://www.amazon.com/dp/B0885RKVMC):
 
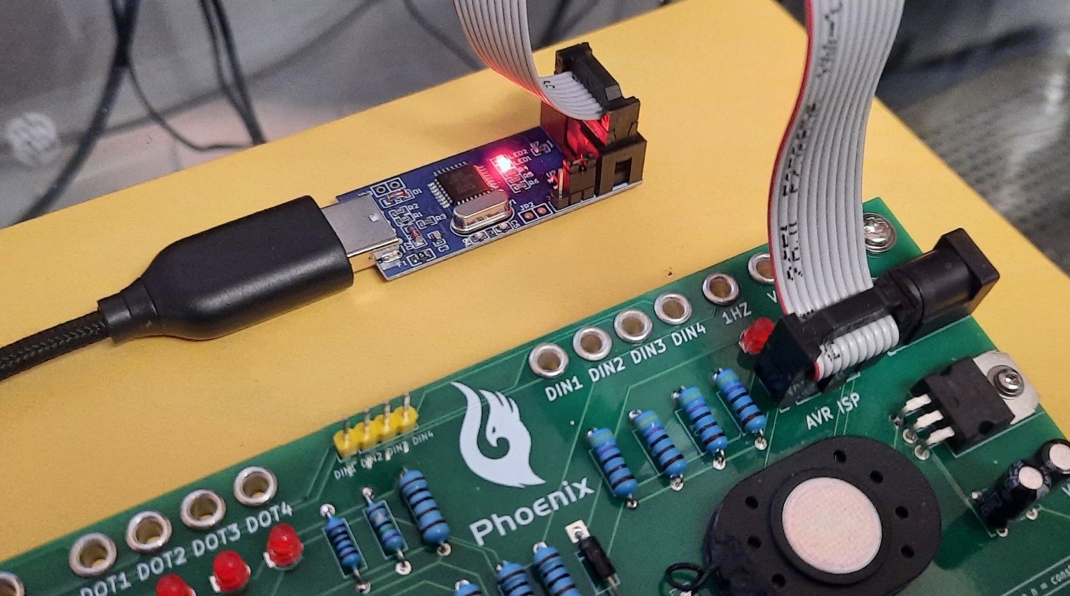
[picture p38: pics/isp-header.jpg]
ISP Header


Note that you will need to burn the bootloader with the correct
MightyCore settings first before you can compile and upload the `.ino`
Arduino sketch for the firmware variant of your choice (Combined,
Neo Only, or Phoenix Only, as described above): 

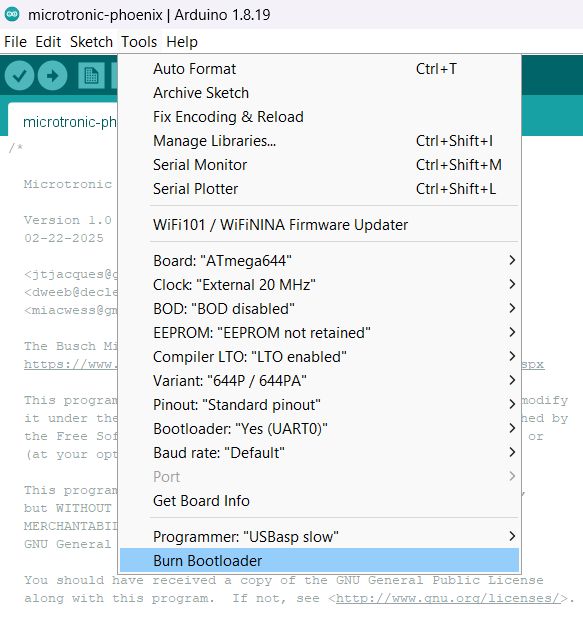
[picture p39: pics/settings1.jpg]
Arduino Settings 1
 

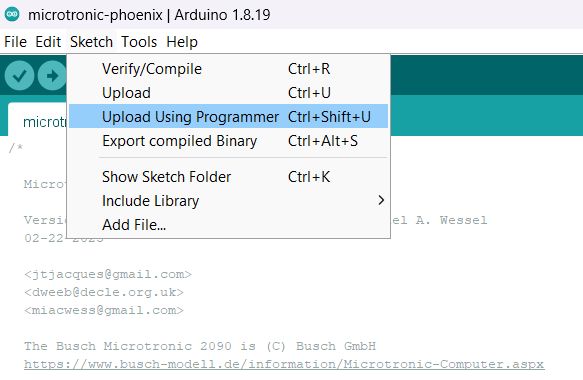
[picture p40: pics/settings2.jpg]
Arduino Settings 2


Please note that you will need to [install the `NewTone` library from
Tim
Eckel.](https://bitbucket.org/teckel12/arduino-new-tone/wiki/Home); a
copy is included [here](microtronic-phoenix-neo-only/NewTone/) for
convenience.

The 7segment LED glyphs / fonts are [Ricardo Batista's
TM16xxFonts.h](https://github.com/maxint-rd/TM16xx/blob/master/src/TM16xxFonts.h); 
a copy is included [here](microtronic-phoenix-neo-only/TM16XXFonts.h) for convenience. 

## Microtronic Software 

A great new fun Microtronic software project is the "Monarch" rotary
slot machine by [rab-berlin](https://github.com/rab-berlin): 

[https://github.com/rab-berlin/Monarch2090](https://github.com/rab-berlin/Monarch2090)

Moreover, most of the historical Microtronic programs from the
Microtronic manuals can be found
[here](https://github.com/lambdamikel/Busch-2090/tree/master/software),
in `.MIC` format.

Michael has [some Microtronic programming videos
online](https://www.youtube.com/watch?v=7hjPqXKYwDc&list=PLvdXKcHrGqhe_Snxh4nh8RMDz2SiUDCHH);
the highlight is an implementation of a [recursive version of the
infamous "Towers of Hanoi" (yes, recursion on the Microtronic is
possible!)](https://github.com/lambdamikel/towers-of-hanoi).

## Acknowledgements

This project benefitted tremendously from the following individuals; we are very grateful for your
contributions to this project! In particular, 

- Jörg Vallen: 

  The [co-designer of the Busch
  Microtronic](https://github.com/lambdamikel/Busch-2090/blob/master/manuals/joerg-vallen-diplom.pdf),
  author of [the Microtronic
  manuals](https://github.com/lambdamikel/Busch-2090/tree/master/manuals),
  and CEO of [Busch Modellbau](https://www.busch-modell.de),
  **Mr. Jörg Vallen**, was very supportive and encouraging of this as
  well as past Microtronic-related projects - not only allowed he to
  include the [original Microtronics
  manuals](https://github.com/lambdamikel/Busch-2090/tree/master/manuals)
  and
  [schematics](https://github.com/lambdamikel/Busch-2090/blob/master/manuals/microtronic.jpg),
  but he also gave us permission to publish the [firmware
  ROM](https://cdn.hackaday.io/files/1974158446203360/microtronic-81-47.bin.bin)
  and [firmware
  disassembly](https://cdn.hackaday.io/files/1974158446203360/really-final-microetronic-firmware-disassembled.txt)
  as well (disassembled by Decle's TMS1xxx disassembler and
  hand-corrected by Jason) - **THANK YOU:**

  ```
    Von: Jörg Vallen <....@busch-model.com>
    Gesendet: Freitag, 21. Juni 2024 10:37 An: 'Michael Wessel' <.....@gmail.com>
    Betreff: AW: Neues Microtronic-Video aus dem Saarland

    Sehr geehrter Herr Wessel,  

    ...
    
    Finde ich genial, dass Sie auch das Betriebssystem
    ausgelesen haben. Natürlich dürfen Sie gerne das Betriebssystem
    auf der Microtronic-Github-Seite veröffentlichen

    ...

    Ihnen alles Gute und weiter erfolgreiches microtronicen…

    Viele Grüße Jörg Vallen
    ``` 
    
- Third-party Arduino libraries: 
    - [The `TM16XXFonts.h` by Ricardo Batista.](https://github.com/maxint-rd/TM16xx/blob/master/src/TM16xxFonts.h)
    - [The `NewTone` library by Tim Eckel.](https://bitbucket.org/teckel12/arduino-new-tone/wiki/Home)

- [**Contributors to the Microtronic Neo predecessors**](https://github.com/lambdamikel/Busch-2090) include:
    - Frank de Jaeger: 2nd Generation Microtronic PCB
    - Manfred Henf: 2nd Generation Microtronic 3D Design & Printing
    - Martin Sauter: Busch 2095 Cassette Interface Protocol Reengineering & Research
    - Lilly (https://github.com/ducatimaus/Busch-2090): Breakpoint & Single Stepping Integration for Uno R3 Version
    - [Björn Rathje](https://github.com/rab-berlin): `HXDZ` op-code bug fix (overflow set to 0 behavior), `DISP` op-code bugfix

- The YouTube channel ["Mein Elektronik Hobby"](https://www.youtube.com/channel/UCEZvUvlcCfJW8mjxwGM8-jw),
  who demonstrated [PicoRAM-2090](https://www.youtube.com/watch?v=267T5BnslIs)
  (also see [https://github.com/lambdamikel/picoram2090](https://github.com/lambdamikel/picoram2090))
  as well as the [2095 Tape Interface / Tape Emulator](https://youtu.be/0MPBtOWTzlk) (joint work
  with Martin Sauter).

**Thank you all!**

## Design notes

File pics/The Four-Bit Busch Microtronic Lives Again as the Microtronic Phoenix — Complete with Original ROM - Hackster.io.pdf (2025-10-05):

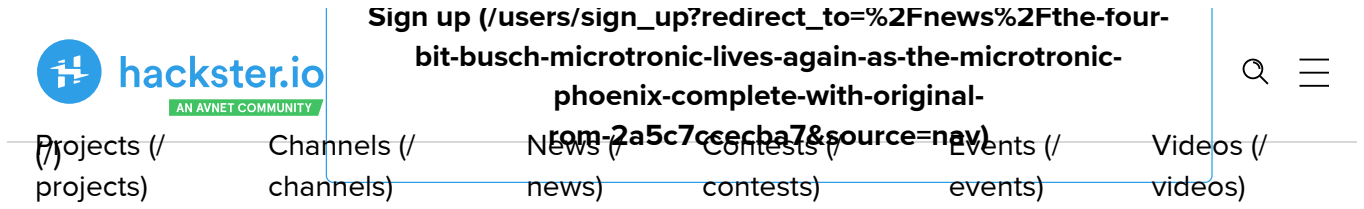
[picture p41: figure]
Sign up (/users/sign_up?redirect_to=%2Fnews%2Fthe-four- bit-busch-microtronic-lives-again-as-the-microtronic- phoenix-complete-with-original- rom-2a5c7ccecba7&source=nav) Projects (/; projects); Channels (/ channels); News (/ news); Contests (/ contests); Events (/ events); Videos (/ videos)

# The Four-Bit Busch Microtronic Lives Again as the Microtronic Phoenix — Complete with Original ROM

## Some digital archaeology and a microcontroller-driven emulator delivers the first new Microtronic-compatible machine since the

1980s.

(/ghalfacree)

Gareth Halfacree (/ghalfacree) (https://www.hackster.io/ghalfacree) | Follow
20 hours ago • Retro Tech (https://www.hackster.io/retrotech) / HW101 (https://www.hackster.io/hw101) (https://www.hackster.io/hw101)
The Four-Bit Busch Microtronic Lives Again as the Microtronic Phoen... | https://www.hackster.io/news/the-four-bit-busch-microtronic-lives-again...

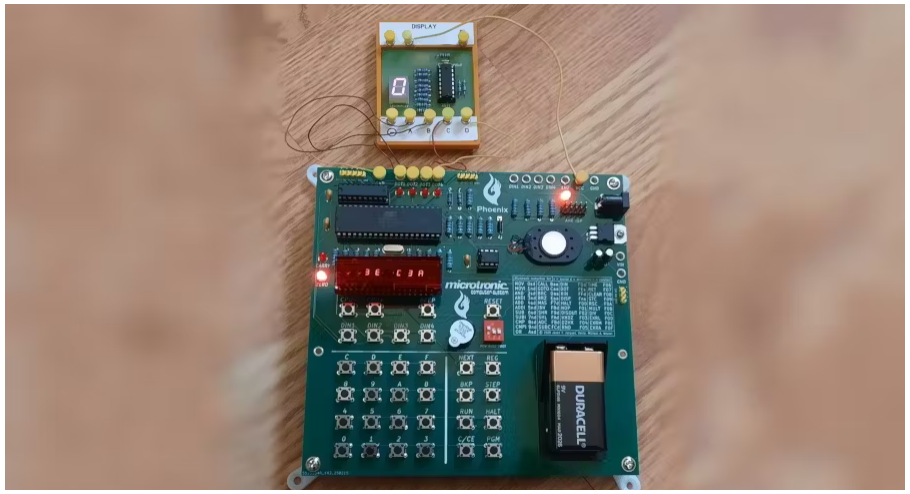
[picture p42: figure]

1 of 8 | 4/17/2025, 8:30 AM

(https://events.hackster.io/impactspotlights) (https://events.hackster.io/impactspotlights)
Ad (http://help.hackster.io/knowledgebase/what-are-these-ads) (http://help.hackster.io/knowledgebase/what-are-these-ads)

Makers and vintage computing enthusiasts Michael Wessel, Jason T. Jacques, and Decle have built the first Busch Microtronic since the 1980s, running a copy of the recently-recovered original ROM in emulation: the Microtronic Phoenix.

"In a previous effort we have successfully recovered the original firmware ROM of the [Busch] Microtronic," Wessel explains of the team's work. "With the original firmware available, it is now time to let it fly again on modern hardware, resulting in the first fully authentic re-implementation of the Busch Microtronic from 1981! Rise from your ashes, Microtronic!"

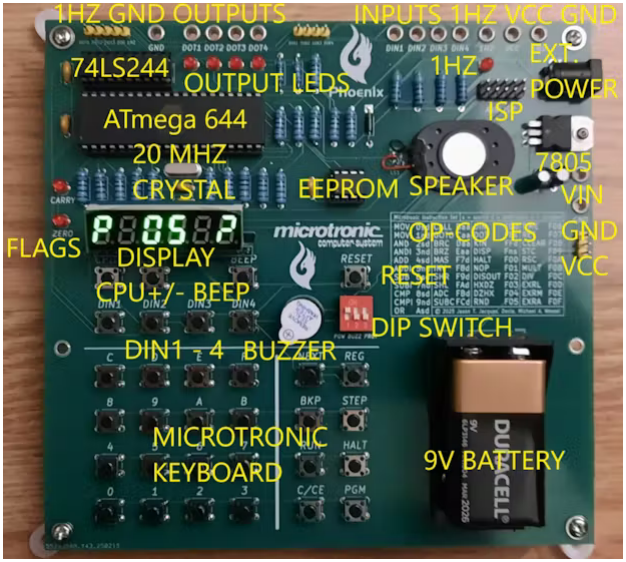
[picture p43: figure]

Got a hankering for a little four-bit retro computing? Build yourself a Microtronic Phoenix. ( : Michael Wessel)

Released in 1981, the Busch 2090 Microtronic Computer System — to give the device its proper title — was an unusual microcomputer trainer built by Busch Modellbau, a company founded as a fireworks manufacturer before pivoting to plastic models. The original used a Texas Instruments TMS1600 four-bit processor running at just 500kHz and with a mere 576 bytes of RAM and 4kB of ROM — and it's the contents of that ROM, long thought lost, that Wessel and friends were able to recover.

While there are hard- and software emulators of the machine available, none of them were running the original ROM — until the launch of the Microtronic Phoenix, a hardware recreation running an emulator on a Microchip ATmega644P-20U microcontroller — and eight-bit part running at a considerably faster 20MHz. Elsewhere on the board is a 24LC256 EEPROM as a non-volatile storage device and a 74LS244 to protect the microcontroller's pins from the machine's input/output ports and vice-versa. "In principle," Wessel explains, "the Phoenix is a one-chip design — everything is driven by the ATmega644P-20U, even the display. The 24LC256 EEPROM is optional; the machine will also work without it."

The emulator, which includes the choice of using six-digit seven-segment LED or bubble LED display or modern equivalent, includes a physical keyboard, buzzer, and silkscreen instruction set reference, and no fewer than three firmware options: Neo Mode, a reimplementation of the firmware; Phoenix Mode, which runs the original Busch ROM; and Combined, which allows either to be selected on startup.

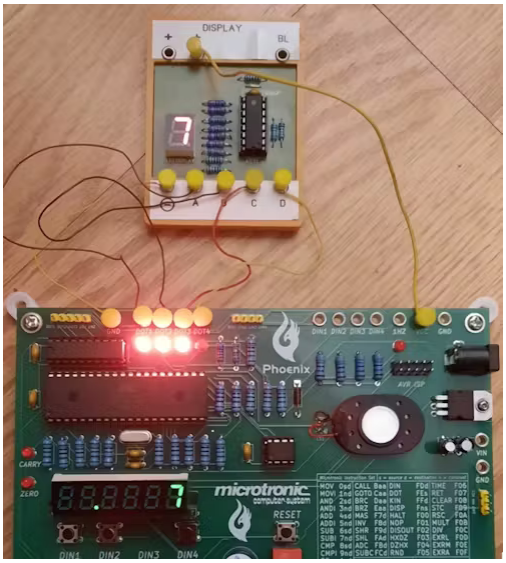
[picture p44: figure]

The recreation even includes functional general-purpose input/output pins, compatible with original Microtronic accessories. ( : Michael Wessel)

"In Neo Mode," Wessel explains, "the hardware emulator has access to the additional hardware features on the board: a speaker for sound output, a 256kBit 24LC256 EEPROM for mass-storage of Microtronic RAM dumps, instead of the 2095 cassette interface; [and a] seven-segment status display."

The project is documented in full on Hackaday.io (https://hackaday.io/project/202835-microtronic-phoenix/); (https://hackaday.io/project/202835-microtronic-phoenix/) board Gerber files and firmware source code are available on GitHub (https://github.com/lambdamikel/microtronic-phoenix?tab=readme-ov-file) (https://github.com/lambdamikel/microtronic-phoenix?tab=readme-ov-file) under the reciprocal GNU General Public License 3.

single board computer (https://www.hackster.io/projects/tags/single+board+computer)

emulator (https://www.hackster.io/projects/tags/emulator)

retro (https://www.hackster.io/projects/tags/retro)

microcontroller (https://www.hackster.io/projects/tags/microcontroller)

open source hardware (https://www.hackster.io/projects/tags/open+source+hardware)

(/ghalfacree)

Gareth Halfacree (/ghalfacree) (https://www.hackster.io/ghalfacree) | Follow

Freelance journalist, technical author, hacker, tinkerer, erstwhile sysadmin. For hire: freelance@halfacree.co.uk.

Get our weekly newsletter when you join Hackster.

Sign up

LATEST ARTICLES | Read more (/news?ref=ha_rm_btn) (https://www.hackster.io/news?ref=ha_rm_btn)

RELATED ARTICLES

Radxa Unveils a Compact Single-Board Qualcomm QCS6490 SBC for Edge AI Work: The Dragon Q6A (https://www.hackster.io/news/radxa-unveils-a-compact-single-boardqualcomm-qcs6490-sbc-for-edge-ai-workthe-dragon-q6a-b3853e514016) (https://www.hackster.io/news/radxa-unveils-a-compact-single-board-qualcomm-qcs6490-sbc-for-edge-ai-work-the-dragon-q6a-b3853e514016)
Gareth Halfacree (/ghalfacree) (https://www.hackster.io/ghalfacree) • 24 hours ago

AI Is Seeing Double (https://www.hackster.io/news/ai-is-seeing-double-e2ef6642221e) (https://www.hackster.io/news/ai-is-seeing-double-e2ef6642221e)
Nick Bild (/nickbild) (https://www.hackster.io/nickbild) • 24 hours ago

Tom MacWright Prepares Tidbyt Owners for a Future Without Tidbyt's Servers (https://www.hackster.io/news/tom-macwrightprepares-tidbyt-owners-for-a-future-withouttidbyt-s-servers-6213f09d2610) (https://www.hackster.io/news/tom-macwright-prepares-tidbyt-owners-for-a-future-without-tidbyt-s-servers-6213f09d2610)
Gareth Halfacree (/ghalfacree) (https://www.hackster.io/ghalfacree) • 24 hours ago

AI That Generates Sound From Anything (https://www.hackster.io/news/ai-thatgenerates-sound-fromanything-574ffdd118ab) (https://www.hackster.io/news/ai-that-generates-sound-from-anything-574ffdd118ab)
Nick Bild (/nickbild) (https://www.hackster.io/nickbild) • 1 day ago

(https://www.hackster.io/news/radxaunveils-a-compact-single-boardqualcomm-qcs6490-sbc-for-edge-aiwork-the-dragon-q6a-b3853e514016) (https://www.hackster.io/news/radxa-unveils-a-compact-single-board-qualcomm-qcs6490-sbc-for-edge-ai-work-the-dragon-q6a-b3853e514016)

(https://www.hackster.io/news/ai-isseeing-double-e2ef6642221e) (https://www.hackster.io/news/ai-is-seeing-double-e2ef6642221e)

(https://www.hackster.io/news/tom-macwright-prepares-tidbyt-owners-for-afuture-without-tidbyt-sservers-6213f09d2610) (https://www.hackster.io/news/tom-macwright-prepares-tidbyt-owners-for-a-future-without-tidbyt-s-servers-6213f09d2610)

(https://www.hackster.io/news/ai-thatgenerates-sound-fromanything-574ffdd118ab) (https://www.hackster.io/news/ai-that-generates-sound-from-anything-574ffdd118ab)

Jordt Bartolome's DrivePACK Is a Smart, Highly-Flexible Replacement for Casio Keyboards' ROM PACKs (https://www.hackster.io/news/jordt-bartolome-sdrivepack-is-a-smart-highly-flexiblereplacement-for-casio-keyboards-rom-packs-09fcf194a2b5) (https://www.hackster.io/news/jordt-bartolome-s-drivepack-is-a-smart-highly-flexible-replacement-for-casio-keyboards-rom-packs-09fcf194a2b5)
Gareth Halfacree (/ghalfacree) (https://www.hackster.io/ghalfacree) • 1 year ago

Matt Callow Turns a Raspberry Pi Pico Into a Low-Cost ROM Emulator for the Amstrad CPC Family (https://www.hackster.io/news/matt-callow-turns-a-raspberry-pi-pico-into-alow-cost-rom-emulator-for-the-amstrad-cpcfamily-cd82e984b9f8) (https://www.hackster.io/news/matt-callow-turns-a-raspberry-pi-pico-into-a-low-cost-rom-emulator-for-the-amstrad-cpc-family-cd82e984b9f8)
Gareth Halfacree (/ghalfacree) (https://www.hackster.io/ghalfacree) • 2 years ago

The MikroLeo Is a Four-Bit "Didactic Microcomputer" That Aims to Teach Core Computing Concepts (https://www.hackster.io/news/the-mikroleo-is-a-four-bit-didactic-microcomputer-that-aims-toteach-core-computing-concepts-51d001f50d07) (https://www.hackster.io/news/the-mikroleo-is-a-four-bit-didactic-microcomputer-that-aims-to-teach-core-computing-concepts-51d001f50d07)
Gareth Halfacree (/ghalfacree) (https://www.hackster.io/ghalfacree) • 2 years ago

Spencer Owen Simplifies RC2014 RomWBW Updates with a Low-Cost, Standalone ROM Blower (https://www.hackster.io/news/spencer-owen-simplifies-rc2014-romwbw-updates-with-a-low-cost-standalone-romblower-ba7495c17374) (https://www.hackster.io/news/spencer-owen-simplifies-rc2014-romwbw-updates-with-a-low-cost-standalone-rom-blower-ba7495c17374)
Gareth Halfacree (/ghalfacree) (https://www.hackster.io/ghalfacree) • 4 months ago

(https://www.hackster.io/news/jordtbartolome-s-drivepack-is-a-smart-highly-flexible-replacement-for-casio-keyboardsrom-packs-09fcf194a2b5) (https://www.hackster.io/news/jordt-bartolome-s-drivepack-is-a-smart-highly-flexible-replacement-for-casio-keyboards-rom-packs-09fcf194a2b5)

(https://www.hackster.io/news/mattcallow-turns-a-raspberry-pi-pico-into-alow-cost-rom-emulator-for-the-amstradcpc-family-cd82e984b9f8) (https://www.hackster.io/news/matt-callow-turns-a-raspberry-pi-pico-into-a-low-cost-rom-emulator-for-the-amstrad-cpc-family-cd82e984b9f8)

(https://www.hackster.io/news/themikroleo-is-a-four-bit-didacticmicrocomputer-that-aims-to-teach-corecomputing-concepts-51d001f50d07) (https://www.hackster.io/news/the-mikroleo-is-a-four-bit-didactic-microcomputer-that-aims-to-teach-core-computing-concepts-51d001f50d07)

(https://www.hackster.io/news/spencerowen-simplifies-rc2014-romwbw-updateswith-a-low-cost-standalone-rom-blower-ba7495c17374) (https://www.hackster.io/news/spencer-owen-simplifies-rc2014-romwbw-updates-with-a-low-cost-standalone-rom-blower-ba7495c17374)

About Us | Legal Thingies | Find Us On Social

Hackster Overview (/about) (https://www.hackster.io/about)
Hackster for Business (/
business) (https://www.hackster.io/business)
Hackster PRO (/pro) (https://www.hackster.io/pro)
Help Articles (https://
help.hackster.io)
Brand Resources (/branding) (https://www.hackster.io/branding) Sitemap (/sitemap.xml.html) (https://www.hackster.io/sitemap.xml.html)

Terms of Service (/terms) (https://www.hackster.io/terms)
Contest Rules (/contest-rules) (https://www.hackster.io/contest-rules) Code of Conduct (/conduct) (https://www.hackster.io/conduct) Privacy Policy (/privacy) (https://www.hackster.io/privacy)
Privacy Policy for California Residents (/privacy/ccpa) (https://www.hackster.io/privacy/ccpa)
Cookie Policy (/cookies) (https://www.hackster.io/cookies)
- Facebook (https://
www.facebook.com/hacksterio)
- Instagram (https://
www.instagram.com/hacksterio)
- LinkedIn (https://
www.linkedin.com/company/
hacksterio) (https://www.linkedin.com/company/hacksterio)
X (https://www.twitter.com/hacksterio) (https://www.twitter.com/hacksterio)
- YouTube (https://
www.youtube.com/hacksterio)

Visit Our Avnet Family

Avnet (https://www.avnet.com) Premier Farnell (https://
www.farnell.com)
element14 (https://
www.element14.com)
Newark (https://
www.newark.com)

Hackster.io, an Avnet Community © 2025

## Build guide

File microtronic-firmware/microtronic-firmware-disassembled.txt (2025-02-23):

# -----------------------------------------------------------------------------
# Page 00

    TCY    f        # 00:00 (00:00) 4f  -  
    RSTR            # 00:01 (00:01) 0c  -  
    DYN             # 00:02 (00:03) 04  -  
    BR     01       # 00:03 (00:07) 81  -  
    RETN            # 00:04 (00:0f) 0f  -  
    LDX    0        # 00:05 (00:1f) 28  -  
    TCY    f        # 00:06 (00:3f) 4f  -  
    CLA             # 00:07 (00:3e) 7f  -  
    TAM             # 00:08 (00:3d) 27  -  
    DYN             # 00:09 (00:3b) 04  -  
    BR     08       # 00:0a (00:37) bd  -  
    RETN            # 00:0b (00:2f) 0f  -  
    LDX    1        # 00:0c (00:1e) 2c  -  
    CALL   06       # 00:0d (00:3c) ff  -  
    LDX    2        # 00:0e (00:39) 2a  -  
    CALL   06       # 00:0f (00:33) ff  -  
    LDX    3        # 00:10 (00:27) 2e  -  
    CALL   06       # 00:11 (00:0e) ff  -  
    LDX    4        # 00:12 (00:1d) 29  -  
    CALL   06       # 00:13 (00:3a) ff  -  
    LDX    5        # 00:14 (00:35) 2d  -  
    CALL   06       # 00:15 (00:2b) ff  -  
    LDX    6        # 00:16 (00:16) 2b  -  
    CALL   06       # 00:17 (00:2c) ff  -  
    LDX    7        # 00:18 (00:18) 2f  -  
    CALL   06       # 00:19 (00:30) ff  -  
    LDP    9        # 00:1a (00:21) 19  -  
    CALL   23       # 00:1b (00:02) e3  -  
    LDP    e        # 00:1c (00:05) 17  -  
    CALL   02       # 00:1d (00:0b) c3  -  
    LDP    7        # 00:1e (00:17) 1e  -  
    BR     1d       # 00:1f (00:2e) 8b  -  
    LDX    2        # 00:20 (00:1c) 2a  -  
    TCY    1        # 00:21 (00:38) 48  -  
    MNEZ            # 00:22 (00:31) 3f  -  
    BR     29       # 00:23 (00:23) 9a  -  
    TCY    0        # 00:24 (00:06) 40  -  
    MNEZ            # 00:25 (00:0d) 3f  -  
    BR     29       # 00:26 (00:1b) 9a  -  
    TCY    2        # 00:27 (00:36) 44  -  
    RBIT   0        # 00:28 (00:2d) 34  -  
    LDP    9        # 00:29 (00:1a) 19  -  
    BR     3b       # 00:2a (00:34) aa  -  
    TCY    6        # 00:2b (00:29) 46  -  
    SETR            # 00:2c (00:12) 0d  -  
    TKA             # 00:2d (00:24) 08  -  
    RSTR            # 00:2e (00:08) 0c  -  
    LDX    4        # 00:2f (00:11) 29  -  
    TCY    f        # 00:30 (00:22) 4f  -  
    TAM             # 00:31 (00:04) 27  -  
    TBIT   3        # 00:32 (00:09) 3b  -  
    BR     37       # 00:33 (00:13) b2  -  
    TCY    6        # 00:34 (00:26) 46  -  
    RBIT   3        # 00:35 (00:0c) 37  -  
    RETN            # 00:36 (00:19) 0f  -  
    TCY    6        # 00:37 (00:32) 46  -  
    TBIT   3        # 00:38 (00:25) 3b  -  
    BR     36       # 00:39 (00:0a) 99  -  
    LDP    2        # 00:3a (00:15) 14  -  
    TPC            # 00:3b (00:2a) 0b  -  
    LDP    8        # 00:3c (00:14) 11  -  
    BR     00       # 00:3d (00:28) 80  -  
    BR     36       # 00:3e (00:10) 99  -  
    RETN            # 00:3f (00:20) 0f  -  

# -----------------------------------------------------------------------------
# Page 01

    LDP    0        # 01:00 (01:00) 10  -  
    BR     00       # 01:01 (01:01) 80  -  
    LDP    8        # 01:02 (01:03) 11  -  
    CALL   39       # 01:03 (01:07) ca  -  
    LDX    0        # 01:04 (01:0f) 28  -  
    TCY    6        # 01:05 (01:1f) 46  -  
    RSTR            # 01:06 (01:3f) 0c  -  
    TCY    b        # 01:07 (01:3e) 4d  -  
    RSTR            # 01:08 (01:3d) 0c  -  
    TCY    5        # 01:09 (01:3b) 4a  -  
    RSTR            # 01:0a (01:37) 0c  -  
    DYN             # 01:0b (01:2f) 04  -  
    BR     0a       # 01:0c (01:1e) b7  -  
    RETN            # 01:0d (01:3c) 0f  -  
    TCY    5        # 01:0e (01:39) 4a  -  
    SETR            # 01:0f (01:33) 0d  -  
    KNEZ            # 01:10 (01:27) 0e  -  
    BR     1a       # 01:11 (01:0e) a1  -  
    RSTR            # 01:12 (01:1d) 0c  -  
    DYN             # 01:13 (01:3a) 04  -  
    BR     0f       # 01:14 (01:35) b3  -  
    TCY    d        # 01:15 (01:2b) 4b  -  
    TBIT   0        # 01:16 (01:16) 38  -  
    BR     02       # 01:17 (01:2c) 83  -  
    LDP    5        # 01:18 (01:18) 1a  -  
    BR     02       # 01:19 (01:30) 83  -  
    TYA             # 01:1a (01:21) 23  -  
    TCY    e        # 01:1b (01:02) 47  -  
    TAM             # 01:1c (01:05) 27  -  
    LDP    8        # 01:1d (01:0b) 11  -  
    CALL   39       # 01:1e (01:17) ca  -  
    LDX    0        # 01:1f (01:2e) 28  -  
    TCY    e        # 01:20 (01:1c) 47  -  
    TMY             # 01:21 (01:38) 22  -  
    SETR            # 01:22 (01:31) 0d  -  
    RETN            # 01:23 (01:23) 0f  -  
    KNEZ            # 01:24 (01:06) 0e  -  
    BR     27       # 01:25 (01:0d) b6  -  
    BR     02       # 01:26 (01:1b) 83  -  
    TKA             # 01:27 (01:36) 08  -  
    TCY    f        # 01:28 (01:2d) 4f  -  
    TAM             # 01:29 (01:1a) 27  -  
    LDP    8        # 01:2a (01:34) 11  -  
    CALL   39       # 01:2b (01:29) ca  -  
    LDX    0        # 01:2c (01:12) 28  -  
    CALL   20       # 01:2d (01:24) dc  -  
    KNEZ            # 01:2e (01:08) 0e  -  
    BR     2a       # 01:2f (01:11) b4  -  
    LDP    8        # 01:30 (01:22) 11  -  
    CALL   39       # 01:31 (01:04) ca  -  
    LDX    0        # 01:32 (01:09) 28  -  
    LDP    2        # 01:33 (01:13) 14  -  
    BR     02       # 01:34 (01:26) 83  -  
    LDX    4        # 01:35 (01:0c) 29  -  
    TCY    6        # 01:36 (01:19) 46  -  
    TBIT   0        # 01:37 (01:32) 38  -  
    BR     3c       # 01:38 (01:25) 94  -  
    LDX    0        # 01:39 (01:0a) 28  -  
    LDP    4        # 01:3a (01:15) 12  -  
    BR     02       # 01:3b (01:2a) 83  -  
    LDP    2        # 01:3c (01:14) 14  -  
    TPC            # 01:3d (01:28) 0b  -  
    LDP    7        # 01:3e (01:10) 1e  -  
    BR     0a       # 01:3f (01:20) b7  -  

# -----------------------------------------------------------------------------
# Page 02

    LDP    0        # 02:00 (02:00) 10  -  
    BR     00       # 02:01 (02:01) 80  -  
    TCY    e        # 02:02 (02:03) 47  -  
    LDX    0        # 02:03 (02:07) 28  -  
    CLA             # 02:04 (02:0f) 7f  -  
    MNEA            # 02:05 (02:1f) 00  -  
    BR     08       # 02:06 (02:3f) bd  -  
    BR     21       # 02:07 (02:3e) b8  -  
    ACxAC  0        # 02:08 (02:3d) 70  -  
    MNEA            # 02:09 (02:3b) 00  -  
    BR     0d       # 02:0a (02:37) bc  -  
    LDP    3        # 02:0b (02:2f) 1c  -  
    BR     02       # 02:0c (02:1e) 83  -  
    ACxAC  0        # 02:0d (02:3c) 70  -  
    MNEA            # 02:0e (02:39) 00  -  
    BR     12       # 02:0f (02:33) 9d  -  
    LDP    3        # 02:10 (02:27) 1c  -  
    BR     16       # 02:11 (02:0e) 96  -  
    ACxAC  0        # 02:12 (02:1d) 70  -  
    MNEA            # 02:13 (02:3a) 00  -  
    BR     17       # 02:14 (02:35) ac  -  
    LDP    3        # 02:15 (02:2b) 1c  -  
    BR     28       # 02:16 (02:16) ad  -  
    ACxAC  0        # 02:17 (02:2c) 70  -  
    MNEA            # 02:18 (02:18) 00  -  
    BR     1c       # 02:19 (02:30) 85  -  
    LDP    b        # 02:1a (02:21) 1d  -  
    BR     02       # 02:1b (02:02) 83  -  
    ACxAC  0        # 02:1c (02:05) 70  -  
    MNEA            # 02:1d (02:0b) 00  -  
    BR     2a       # 02:1e (02:17) b4  -  
    LDP    7        # 02:1f (02:2e) 1e  -  
    BR     08       # 02:20 (02:1c) bd  -  
    TCY    f        # 02:21 (02:38) 4f  -  
    TBIT   0        # 02:22 (02:31) 38  -  
    BR     2c       # 02:23 (02:23) 92  -  
    TBIT   1        # 02:24 (02:06) 3a  -  
    BR     2e       # 02:25 (02:0d) 88  -  
    TBIT   2        # 02:26 (02:1b) 39  -  
    BR     30       # 02:27 (02:36) a2  -  
    TBIT   3        # 02:28 (02:2d) 3b  -  
    BR     32       # 02:29 (02:1a) 89  -  
    LDP    1        # 02:2a (02:34) 18  -  
    BR     02       # 02:2b (02:29) 83  -  
    TCMIY  0        # 02:2c (02:12) 60  -  
    BR     33       # 02:2d (02:24) 93  -  
    TCMIY  4        # 02:2e (02:08) 62  -  
    BR     33       # 02:2f (02:11) 93  -  
    TCMIY  8        # 02:30 (02:22) 61  -  
    BR     33       # 02:31 (02:04) 93  -  
    TCMIY  c        # 02:32 (02:09) 63  -  
    LDP    e        # 02:33 (02:13) 17  -  
    BR     24       # 02:34 (02:26) 86  -  
    CLA             # 02:35 (02:0c) 7f  -  
    ACxAC  0        # 02:36 (02:19) 70  -  
    BR     39       # 02:37 (02:32) 8a  -  
    BR     36       # 02:38 (02:25) 99  -  
    RETN            # 02:39 (02:0a) 0f  -  
    IYC             # 02:3a (02:15) 05  -  
    SETR            # 02:3b (02:2a) 0d  -  
    RSTR            # 02:3c (02:14) 0c  -  
    BR     3a       # 02:3d (02:28) 95  -  
    MNEA            # 02:3e (02:10) 00  -  
    MNEA            # 02:3f (02:20) 00  -  

# -----------------------------------------------------------------------------
# Page 03

    LDP    0        # 03:00 (03:00) 10  -  
    BR     00       # 03:01 (03:01) 80  -  
    TCY    f        # 03:02 (03:03) 4f  -  
    TBIT   0        # 03:03 (03:07) 38  -  
    BR     0d       # 03:04 (03:0f) bc  -  
    TBIT   1        # 03:05 (03:1f) 3a  -  
    BR     10       # 03:06 (03:3f) a7  -  
    TBIT   2        # 03:07 (03:3e) 39  -  
    BR     12       # 03:08 (03:3d) 9d  -  
    TBIT   3        # 03:09 (03:3b) 3b  -  
    BR     14       # 03:0a (03:37) b5  -  
    LDP    1        # 03:0b (03:2f) 18  -  
    BR     02       # 03:0c (03:1e) 83  -  
    TCMIY  1        # 03:0d (03:3c) 68  -  
    LDP    2        # 03:0e (03:39) 14  -  
    BR     33       # 03:0f (03:33) 93  -  
    TCMIY  5        # 03:10 (03:27) 6a  -  
    BR     0e       # 03:11 (03:0e) b9  -  
    TCMIY  9        # 03:12 (03:1d) 69  -  
    BR     0e       # 03:13 (03:3a) b9  -  
    TCMIY  d        # 03:14 (03:35) 6b  -  
    BR     0e       # 03:15 (03:2b) b9  -  
    TCY    f        # 03:16 (03:16) 4f  -  
    TBIT   0        # 03:17 (03:2c) 38  -  
    BR     20       # 03:18 (03:18) 9c  -  
    TBIT   1        # 03:19 (03:30) 3a  -  
    BR     22       # 03:1a (03:21) b1  -  
    TBIT   2        # 03:1b (03:02) 39  -  
    BR     24       # 03:1c (03:05) 86  -  
    TBIT   3        # 03:1d (03:0b) 3b  -  
    BR     26       # 03:1e (03:17) 9b  -  
    BR     0b       # 03:1f (03:2e) af  -  
    TCMIY  2        # 03:20 (03:1c) 64  -  
    BR     0e       # 03:21 (03:38) b9  -  
    TCMIY  6        # 03:22 (03:31) 66  -  
    BR     0e       # 03:23 (03:23) b9  -  
    TCMIY  a        # 03:24 (03:06) 65  -  
    BR     0e       # 03:25 (03:0d) b9  -  
    TCMIY  e        # 03:26 (03:1b) 67  -  
    BR     0e       # 03:27 (03:36) b9  -  
    TCY    f        # 03:28 (03:2d) 4f  -  
    TBIT   0        # 03:29 (03:1a) 38  -  
    BR     32       # 03:2a (03:34) 89  -  
    TBIT   1        # 03:2b (03:29) 3a  -  
    BR     34       # 03:2c (03:12) a6  -  
    TBIT   2        # 03:2d (03:24) 39  -  
    BR     36       # 03:2e (03:08) 99  -  
    TBIT   3        # 03:2f (03:11) 3b  -  
    BR     38       # 03:30 (03:22) a5  -  
    BR     0b       # 03:31 (03:04) af  -  
    TCMIY  3        # 03:32 (03:09) 6c  -  
    BR     0e       # 03:33 (03:13) b9  -  
    TCMIY  7        # 03:34 (03:26) 6e  -  
    BR     0e       # 03:35 (03:0c) b9  -  
    TCMIY  b        # 03:36 (03:19) 6d  -  
    BR     0e       # 03:37 (03:32) b9  -  
    TCMIY  f        # 03:38 (03:25) 6f  -  
    BR     0e       # 03:39 (03:0a) b9  -  
    LDP    2        # 03:3a (03:15) 14  -  
    TPC            # 03:3b (03:2a) 0b  -  
    LDP    0        # 03:3c (03:14) 10  -  
    BR     1b       # 03:3d (03:28) 82  -  
    MNEA            # 03:3e (03:10) 00  -  
    MNEA            # 03:3f (03:20) 00  -  

# -----------------------------------------------------------------------------
# Page 04

    LDP    0        # 04:00 (04:00) 10  -  
    BR     00       # 04:01 (04:01) 80  -  
    TCY    d        # 04:02 (04:03) 4b  -  
    TBIT   3        # 04:03 (04:07) 3b  -  
    BR     2f       # 04:04 (04:0f) 91  -  
    TCY    6        # 04:05 (04:1f) 46  -  
    TMA             # 04:06 (04:3f) 21  -  
    ACxAC  c        # 04:07 (04:3e) 73  -  
    BR     3c       # 04:08 (04:3d) 94  -  
    LDX    2        # 04:09 (04:3b) 2a  -  
    TCY    3        # 04:0a (04:37) 4c  -  
    SBIT   2        # 04:0b (04:2f) 31  -  
    LDX    0        # 04:0c (04:1e) 28  -  
    CLA             # 04:0d (04:3c) 7f  -  
    TCY    7        # 04:0e (04:39) 4e  -  
    TAM             # 04:0f (04:33) 27  -  
    TCY    0        # 04:10 (04:27) 40  -  
    XMA             # 04:11 (04:0e) 03  -  
    TCY    1        # 04:12 (04:1d) 48  -  
    XMA             # 04:13 (04:3a) 03  -  
    TCY    2        # 04:14 (04:35) 44  -  
    XMA             # 04:15 (04:2b) 03  -  
    TCY    f        # 04:16 (04:16) 4f  -  
    TMA             # 04:17 (04:2c) 21  -  
    TCY    0        # 04:18 (04:18) 40  -  
    TAM             # 04:19 (04:30) 27  -  
    LDX    2        # 04:1a (04:21) 2a  -  
    TCY    3        # 04:1b (04:02) 4c  -  
    TBIT   1        # 04:1c (04:05) 3a  -  
    BR     31       # 04:1d (04:0b) 84  -  
    LDX    0        # 04:1e (04:17) 28  -  
    TCY    8        # 04:1f (04:2e) 41  -  
    TBIT   2        # 04:20 (04:1c) 39  -  
    BR     31       # 04:21 (04:38) 84  -  
    LDP    f        # 04:22 (04:31) 1f  -  
    CALL   02       # 04:23 (04:23) c3  -  
    LDP    1        # 04:24 (04:06) 18  -  
    TPC            # 04:25 (04:0d) 0b  -  
    LDP    e        # 04:26 (04:1b) 17  -  
    CALL   29       # 04:27 (04:36) da  -  
    RETN            # 04:28 (04:2d) 0f  -  
    LDX    0        # 04:29 (04:1a) 28  -  
    TCY    d        # 04:2a (04:34) 4b  -  
    SBIT   0        # 04:2b (04:29) 30  -  
    TCY    6        # 04:2c (04:12) 46  -  
    IMAC            # 04:2d (04:24) 3e  -  
    TAM             # 04:2e (04:08) 27  -  
    LDP    5        # 04:2f (04:11) 1a  -  
    BR     02       # 04:30 (04:22) 83  -  
    LDP    f        # 04:31 (04:04) 1f  -  
    CALL   2a       # 04:32 (04:09) f4  -  
    LDP    f        # 04:33 (04:13) 1f  -  
    CALL   34       # 04:34 (04:26) e6  -  
    LDP    8        # 04:35 (04:0c) 11  -  
    CALL   0c       # 04:36 (04:19) de  -  
    LDX    3        # 04:37 (04:32) 2e  -  
    TCY    3        # 04:38 (04:25) 4c  -  
    LDP    0        # 04:39 (04:0a) 10  -  
    CALL   07       # 04:3a (04:15) fe  -  
    BR     24       # 04:3b (04:2a) 86  -  
    TCY    6        # 04:3c (04:14) 46  -  
    TCMIY  0        # 04:3d (04:28) 60  -  
    BR     0d       # 04:3e (04:10) bc  -  
    MNEA            # 04:3f (04:20) 00  -  

# -----------------------------------------------------------------------------
# Page 05

    LDP    0        # 05:00 (05:00) 10  -  
    BR     00       # 05:01 (05:01) 80  -  
    LDP    8        # 05:02 (05:03) 11  -  
    CALL   39       # 05:03 (05:07) ca  -  
    LDX    4        # 05:04 (05:0f) 29  -  
    TCY    d        # 05:05 (05:1f) 4b  -  
    TBIT   0        # 05:06 (05:3f) 38  -  
    BR     10       # 05:07 (05:3e) a7  -  
    TCY    e        # 05:08 (05:3d) 47  -  
    RSTR            # 05:09 (05:3b) 0c  -  
    TCY    d        # 05:0a (05:37) 4b  -  
    TBIT   1        # 05:0b (05:2f) 3a  -  
    BR     13       # 05:0c (05:1e) ba  -  
    TCY    f        # 05:0d (05:3c) 4f  -  
    RSTR            # 05:0e (05:39) 0c  -  
    BR     15       # 05:0f (05:33) ab  -  
    TCY    e        # 05:10 (05:27) 47  -  
    SETR            # 05:11 (05:0e) 0d  -  
    BR     0a       # 05:12 (05:1d) b7  -  
    TCY    f        # 05:13 (05:3a) 4f  -  
    SETR            # 05:14 (05:35) 0d  -  
    RETN            # 05:15 (05:2b) 0f  -  
    LDP    b        # 05:16 (05:16) 1d  -  
    BR     36       # 05:17 (05:2c) 99  -  
    TCY    8        # 05:18 (05:18) 41  -  
    TBIT   0        # 05:19 (05:30) 38  -  
    BR     26       # 05:1a (05:21) 9b  -  
    TBIT   2        # 05:1b (05:02) 39  -  
    BR     28       # 05:1c (05:05) ad  -  
    TCY    9        # 05:1d (05:0b) 49  -  
    TBIT   0        # 05:1e (05:17) 38  -  
    BR     2e       # 05:1f (05:2e) 88  -  
    TBIT   1        # 05:20 (05:1c) 3a  -  
    BR     2a       # 05:21 (05:38) b4  -  
    TBIT   2        # 05:22 (05:31) 39  -  
    BR     2c       # 05:23 (05:23) 92  -  
    LDP    1        # 05:24 (05:06) 18  -  
    BR     02       # 05:25 (05:0d) 83  -  
    LDP    8        # 05:26 (05:1b) 11  -  
    BR     02       # 05:27 (05:36) 83  -  
    LDP    6        # 05:28 (05:2d) 16  -  
    BR     02       # 05:29 (05:1a) 83  -  
    LDP    6        # 05:2a (05:34) 16  -  
    BR     10       # 05:2b (05:29) a7  -  
    LDP    6        # 05:2c (05:12) 16  -  
    BR     17       # 05:2d (05:24) ac  -  
    LDP    7        # 05:2e (05:08) 1e  -  
    BR     35       # 05:2f (05:11) 8c  -  
    LDP    b        # 05:30 (05:22) 1d  -  
    CALL   2d       # 05:31 (05:04) e4  -  
    LDP    0        # 05:32 (05:09) 10  -  
    CALL   2b       # 05:33 (05:13) e9  -  
    LDX    3        # 05:34 (05:26) 2e  -  
    TCY    6        # 05:35 (05:0c) 46  -  
    TBIT   1        # 05:36 (05:19) 3a  -  
    BR     3d       # 05:37 (05:32) a8  -  
    TBIT   0        # 05:38 (05:25) 38  -  
    BR     3b       # 05:39 (05:0a) aa  -  
    RETN            # 05:3a (05:15) 0f  -  
    LDP    d        # 05:3b (05:2a) 1b  -  
    BR     02       # 05:3c (05:14) 83  -  
    LDP    3        # 05:3d (05:28) 1c  -  
    BR     3a       # 05:3e (05:10) 95  -  
    MNEA            # 05:3f (05:20) 00  -  

# -----------------------------------------------------------------------------
# Page 06

    LDP    0        # 06:00 (06:00) 10  -  
    BR     00       # 06:01 (06:01) 80  -  
    TCY    6        # 06:02 (06:03) 46  -  
    TMY             # 06:03 (06:07) 22  -  
    RETN            # 06:04 (06:0f) 0f  -  
    YNEC   2        # 06:05 (06:1f) 54  -  
    BR     24       # 06:06 (06:3f) 86  -  
    LDP    f        # 06:07 (06:3e) 1f  -  
    CALL   22       # 06:08 (06:3d) f1  -  
    TCY    2        # 06:09 (06:3b) 44  -  
    SBIT   0        # 06:0a (06:37) 30  -  
    LDX    0        # 06:0b (06:2f) 28  -  
    TCY    8        # 06:0c (06:1e) 41  -  
    RBIT   2        # 06:0d (06:3c) 35  -  
    LDP    0        # 06:0e (06:39) 10  -  
    BR     20       # 06:0f (06:33) 9c  -  
    CALL   02       # 06:10 (06:27) c3  -  
    YNEC   1        # 06:11 (06:0e) 58  -  
    BR     24       # 06:12 (06:1d) 86  -  
    LDP    2        # 06:13 (06:3a) 14  -  
    TPC            # 06:14 (06:35) 0b  -  
    LDP    0        # 06:15 (06:2b) 10  -  
    BR     00       # 06:16 (06:16) 80  -  
    LDP    2        # 06:17 (06:2c) 14  -  
    TPC            # 06:18 (06:18) 0b  -  
    LDP    2        # 06:19 (06:30) 14  -  
    BR     00       # 06:1a (06:21) 80  -  
    TCY    7        # 06:1b (06:02) 4e  -  
    TCMIY  0        # 06:1c (06:05) 60  -  
    TCY    f        # 06:1d (06:0b) 4f  -  
    TBIT   1        # 06:1e (06:17) 3a  -  
    BR     26       # 06:1f (06:2e) 9b  -  
    TBIT   2        # 06:20 (06:1c) 39  -  
    BR     30       # 06:21 (06:38) a2  -  
    TBIT   3        # 06:22 (06:31) 3b  -  
    BR     3d       # 06:23 (06:23) a8  -  
    LDP    9        # 06:24 (06:06) 19  -  
    BR     3b       # 06:25 (06:0d) aa  -  
    TCY    8        # 06:26 (06:1b) 41  -  
    TCMIY  1        # 06:27 (06:36) 68  -  
    LDP    1        # 06:28 (06:2d) 18  -  
    TPC            # 06:29 (06:1a) 0b  -  
    LDP    e        # 06:2a (06:34) 17  -  
    CALL   1d       # 06:2b (06:29) cb  -  
    LDP    8        # 06:2c (06:12) 11  -  
    BR     28       # 06:2d (06:24) ad  -  
    LDP    5        # 06:2e (06:08) 1a  -  
    BR     02       # 06:2f (06:11) 83  -  
    TCY    8        # 06:30 (06:22) 41  -  
    TBIT   1        # 06:31 (06:04) 3a  -  
    BR     36       # 06:32 (06:09) 99  -  
    TBIT   3        # 06:33 (06:13) 3b  -  
    BR     36       # 06:34 (06:26) 99  -  
    BR     2e       # 06:35 (06:0c) 88  -  
    SBIT   2        # 06:36 (06:19) 31  -  
    TCY    5        # 06:37 (06:32) 4a  -  
    LDP    7        # 06:38 (06:25) 1e  -  
    CALL   03       # 06:39 (06:0a) c7  -  
    LDX    0        # 06:3a (06:15) 28  -  
    SBIT   0        # 06:3b (06:2a) 30  -  
    BR     2e       # 06:3c (06:14) 88  -  
    TCY    9        # 06:3d (06:28) 49  -  
    TCMIY  1        # 06:3e (06:10) 68  -  
    BR     2e       # 06:3f (06:20) 88  -  

# -----------------------------------------------------------------------------
# Page 07

    LDP    0        # 07:00 (07:00) 10  -  
    BR     00       # 07:01 (07:01) 80  -  
    TCY    3        # 07:02 (07:03) 4c  -  
    LDP    0        # 07:03 (07:07) 10  -  
    CALL   07       # 07:04 (07:0f) fe  -  
    TCY    6        # 07:05 (07:1f) 46  -  
    TCMIY  0        # 07:06 (07:3f) 60  -  
    RETN            # 07:07 (07:3e) 0f  -  
    TCY    7        # 07:08 (07:3d) 4e  -  
    TCMIY  0        # 07:09 (07:3b) 60  -  
    TCY    f        # 07:0a (07:37) 4f  -  
    TBIT   0        # 07:0b (07:2f) 38  -  
    BR     15       # 07:0c (07:1e) ab  -  
    TBIT   1        # 07:0d (07:3c) 3a  -  
    BR     1d       # 07:0e (07:39) 8b  -  
    TBIT   2        # 07:0f (07:33) 39  -  
    BR     21       # 07:10 (07:27) b8  -  
    TBIT   3        # 07:11 (07:0e) 3b  -  
    BR     27       # 07:12 (07:1d) b6  -  
    LDP    9        # 07:13 (07:3a) 19  -  
    BR     3b       # 07:14 (07:35) aa  -  
    TCY    8        # 07:15 (07:2b) 41  -  
    TBIT   0        # 07:16 (07:16) 38  -  
    BR     2f       # 07:17 (07:2c) 91  -  
    TCY    9        # 07:18 (07:18) 49  -  
    TCMIY  4        # 07:19 (07:30) 62  -  
    LDP    7        # 07:1a (07:21) 1e  -  
    CALL   02       # 07:1b (07:02) c3  -  
    BR     2f       # 07:1c (07:05) 91  -  
    LDP    1        # 07:1d (07:0b) 18  -  
    TPC            # 07:1e (07:17) 0b  -  
    LDP    c        # 07:1f (07:2e) 13  -  
    BR     21       # 07:20 (07:1c) b8  -  
    TCY    8        # 07:21 (07:38) 41  -  
    SBIT   3        # 07:22 (07:31) 33  -  
    LDP    2        # 07:23 (07:23) 14  -  
    TPC            # 07:24 (07:06) 0b  -  
    LDP    1        # 07:25 (07:0d) 18  -  
    BR     00       # 07:26 (07:1b) 80  -  
    TCY    8        # 07:27 (07:36) 41  -  
    TBIT   1        # 07:28 (07:2d) 3a  -  
    BR     2b       # 07:29 (07:1a) a9  -  
    BR     2f       # 07:2a (07:34) 91  -  
    TCY    9        # 07:2b (07:29) 49  -  
    TCMIY  2        # 07:2c (07:12) 64  -  
    LDP    7        # 07:2d (07:24) 1e  -  
    CALL   02       # 07:2e (07:08) c3  -  
    LDP    5        # 07:2f (07:11) 1a  -  
    BR     02       # 07:30 (07:22) 83  -  
    LDP    2        # 07:31 (07:04) 14  -  
    TPC            # 07:32 (07:09) 0b  -  
    LDP    0        # 07:33 (07:13) 10  -  
    BR     36       # 07:34 (07:26) 99  -  
    TCY    8        # 07:35 (07:0c) 41  -  
    TBIT   1        # 07:36 (07:19) 3a  -  
    BR     3b       # 07:37 (07:32) aa  -  
    TCY    9        # 07:38 (07:25) 49  -  
    RBIT   0        # 07:39 (07:0a) 34  -  
    BR     2f       # 07:3a (07:15) 91  -  
    LDX    3        # 07:3b (07:2a) 2e  -  
    TCY    6        # 07:3c (07:14) 46  -  
    RBIT   1        # 07:3d (07:28) 36  -  
    LDP    a        # 07:3e (07:10) 15  -  
    BR     02       # 07:3f (07:20) 83  -  

# -----------------------------------------------------------------------------
# Page 08

    LDP    0        # 08:00 (08:00) 10  -  
    BR     00       # 08:01 (08:01) 80  -  
    LDX    2        # 08:02 (08:03) 2a  -  
    TCY    4        # 08:03 (08:07) 42  -  
    IMAC            # 08:04 (08:0f) 3e  -  
    BR     08       # 08:05 (08:1f) bd  -  
    TAM             # 08:06 (08:3f) 27  -  
    BR     0c       # 08:07 (08:3e) 9e  -  
    TAMIYC          # 08:08 (08:3d) 25  -  
    IMAC            # 08:09 (08:3b) 3e  -  
    BR     0b       # 08:0a (08:37) af  -  
    TAM             # 08:0b (08:2f) 27  -  
    TCY    5        # 08:0c (08:1e) 4a  -  
    TMA             # 08:0d (08:3c) 21  -  
    LDX    3        # 08:0e (08:39) 2e  -  
    TAM             # 08:0f (08:33) 27  -  
    LDX    1        # 08:10 (08:27) 2c  -  
    TAM             # 08:11 (08:0e) 27  -  
    LDX    2        # 08:12 (08:1d) 2a  -  
    TCY    4        # 08:13 (08:3a) 42  -  
    TMA             # 08:14 (08:35) 21  -  
    LDX    3        # 08:15 (08:2b) 2e  -  
    TAM             # 08:16 (08:16) 27  -  
    LDX    1        # 08:17 (08:2c) 2c  -  
    TAM             # 08:18 (08:18) 27  -  
    RETN            # 08:19 (08:30) 0f  -  
    LDP    9        # 08:1a (08:21) 19  -  
    CALL   02       # 08:1b (08:02) c3  -  
    LDX    2        # 08:1c (08:05) 2a  -  
    TCY    2        # 08:1d (08:0b) 44  -  
    TBIT   0        # 08:1e (08:17) 38  -  
    BR     2c       # 08:1f (08:2e) 92  -  
    LDX    0        # 08:20 (08:1c) 28  -  
    TCY    8        # 08:21 (08:38) 41  -  
    TBIT   0        # 08:22 (08:31) 38  -  
    BR     28       # 08:23 (08:23) ad  -  
    LDP    f        # 08:24 (08:06) 1f  -  
    CALL   1a       # 08:25 (08:0d) e1  -  
    LDP    c        # 08:26 (08:1b) 13  -  
    BR     3b       # 08:27 (08:36) aa  -  
    LDP    1        # 08:28 (08:2d) 18  -  
    TPC            # 08:29 (08:1a) 0b  -  
    LDP    0        # 08:2a (08:34) 10  -  
    BR     00       # 08:2b (08:29) 80  -  
    LDX    2        # 08:2c (08:12) 2a  -  
    TCY    5        # 08:2d (08:24) 4a  -  
    TMA             # 08:2e (08:08) 21  -  
    TCY    1        # 08:2f (08:11) 48  -  
    MNEA            # 08:30 (08:22) 00  -  
    BR     20       # 08:31 (08:04) 9c  -  
    TCY    4        # 08:32 (08:09) 42  -  
    TMA             # 08:33 (08:13) 21  -  
    TCY    0        # 08:34 (08:26) 40  -  
    MNEA            # 08:35 (08:0c) 00  -  
    BR     20       # 08:36 (08:19) 9c  -  
    LDP    7        # 08:37 (08:32) 1e  -  
    BR     1d       # 08:38 (08:25) 8b  -  
    LDP    1        # 08:39 (08:0a) 18  -  
    CALL   05       # 08:3a (08:15) df  -  
    LDP    5        # 08:3b (08:2a) 1a  -  
    BR     30       # 08:3c (08:14) a2  -  
    TCMIY  5        # 08:3d (08:28) 6a  -  
    TCMIY  a        # 08:3e (08:10) 65  -  
    BR     3d       # 08:3f (08:20) a8  -  

# -----------------------------------------------------------------------------
# Page 09

    LDP    0        # 09:00 (09:00) 10  -  
    BR     00       # 09:01 (09:01) 80  -  
    TCY    b        # 09:02 (09:03) 4d  -  
    SETR            # 09:03 (09:07) 0d  -  
    LDP    b        # 09:04 (09:0f) 1d  -  
    CALL   20       # 09:05 (09:1f) dc  -  
    LDP    e        # 09:06 (09:3f) 17  -  
    CALL   36       # 09:07 (09:3e) d9  -  
    TKA             # 09:08 (09:3d) 08  -  
    CALL   23       # 09:09 (09:3b) e3  -  
    TCY    2        # 09:0a (09:37) 44  -  
    TAM             # 09:0b (09:2f) 27  -  
    TCY    5        # 09:0c (09:1e) 4a  -  
    SETR            # 09:0d (09:3c) 0d  -  
    LDP    e        # 09:0e (09:39) 17  -  
    CALL   36       # 09:0f (09:33) d9  -  
    TKA             # 09:10 (09:27) 08  -  
    CALL   23       # 09:11 (09:0e) e3  -  
    TCY    1        # 09:12 (09:1d) 48  -  
    TAM             # 09:13 (09:3a) 27  -  
    TCY    5        # 09:14 (09:35) 4a  -  
    RSTR            # 09:15 (09:2b) 0c  -  
    TCY    4        # 09:16 (09:16) 42  -  
    SETR            # 09:17 (09:2c) 0d  -  
    LDP    e        # 09:18 (09:18) 17  -  
    CALL   36       # 09:19 (09:30) d9  -  
    TKA             # 09:1a (09:21) 08  -  
    CALL   23       # 09:1b (09:02) e3  -  
    TCY    0        # 09:1c (09:05) 40  -  
    TAM             # 09:1d (09:0b) 27  -  
    TCY    4        # 09:1e (09:17) 42  -  
    RSTR            # 09:1f (09:2e) 0c  -  
    TCY    b        # 09:20 (09:1c) 4d  -  
    RSTR            # 09:21 (09:38) 0c  -  
    RETN            # 09:22 (09:31) 0f  -  
    TCY    f        # 09:23 (09:23) 4f  -  
    TAM             # 09:24 (09:06) 27  -  
    TBIT   0        # 09:25 (09:0d) 38  -  
    BR     33       # 09:26 (09:1b) 93  -  
    SBIT   0        # 09:27 (09:36) 30  -  
    TBIT   1        # 09:28 (09:2d) 3a  -  
    BR     35       # 09:29 (09:1a) 8c  -  
    SBIT   1        # 09:2a (09:34) 32  -  
    TBIT   2        # 09:2b (09:29) 39  -  
    BR     37       # 09:2c (09:12) b2  -  
    SBIT   2        # 09:2d (09:24) 31  -  
    TBIT   3        # 09:2e (09:08) 3b  -  
    BR     39       # 09:2f (09:11) 8a  -  
    SBIT   3        # 09:30 (09:22) 33  -  
    TMA             # 09:31 (09:04) 21  -  
    RETN            # 09:32 (09:09) 0f  -  
    RBIT   0        # 09:33 (09:13) 34  -  
    BR     28       # 09:34 (09:26) ad  -  
    RBIT   1        # 09:35 (09:0c) 36  -  
    BR     2b       # 09:36 (09:19) a9  -  
    RBIT   2        # 09:37 (09:32) 35  -  
    BR     2e       # 09:38 (09:25) 88  -  
    RBIT   3        # 09:39 (09:0a) 37  -  
    BR     31       # 09:3a (09:15) 84  -  
    LDP    1        # 09:3b (09:2a) 18  -  
    TPC            # 09:3c (09:14) 0b  -  
    LDP    b        # 09:3d (09:28) 1d  -  
    BR     2d       # 09:3e (09:10) a4  -  
    MNEA            # 09:3f (09:20) 00  -  

# -----------------------------------------------------------------------------
# Page 0a

    LDP    0        # 0a:00 (0a:00) 10  -  
    BR     00       # 0a:01 (0a:01) 80  -  
    LDX    2        # 0a:02 (0a:03) 2a  -  
    TCY    3        # 0a:03 (0a:07) 4c  -  
    RETN            # 0a:04 (0a:0f) 0f  -  
    TBIT   0        # 0a:05 (0a:1f) 38  -  
    BR     28       # 0a:06 (0a:3f) ad  -  
    TBIT   1        # 0a:07 (0a:3e) 3a  -  
    BR     0c       # 0a:08 (0a:3d) 9e  -  
    CALL   0f       # 0a:09 (0a:3b) f3  -  
    SBIT   1        # 0a:0a (0a:37) 32  -  
    BR     26       # 0a:0b (0a:2f) 9b  -  
    CALL   28       # 0a:0c (0a:1e) ed  -  
    YNEC   2        # 0a:0d (0a:3c) 54  -  
    BR     26       # 0a:0e (0a:39) 9b  -  
    LDX    0        # 0a:0f (0a:33) 28  -  
    TCY    5        # 0a:10 (0a:27) 4a  -  
    LDP    0        # 0a:11 (0a:0e) 10  -  
    CALL   07       # 0a:12 (0a:1d) fe  -  
    CALL   02       # 0a:13 (0a:3a) c3  -  
    RETN            # 0a:14 (0a:35) 0f  -  
    SBIT   0        # 0a:15 (0a:2b) 30  -  
    RBIT   1        # 0a:16 (0a:16) 36  -  
    RBIT   2        # 0a:17 (0a:2c) 35  -  
    LDP    9        # 0a:18 (0a:18) 19  -  
    CALL   02       # 0a:19 (0a:30) c3  -  
    LDP    f        # 0a:1a (0a:21) 1f  -  
    CALL   1a       # 0a:1b (0a:02) e1  -  
    LDX    0        # 0a:1c (0a:05) 28  -  
    TCY    3        # 0a:1d (0a:0b) 4c  -  
    LDP    0        # 0a:1e (0a:17) 10  -  
    CALL   07       # 0a:1f (0a:2e) fe  -  
    TCY    6        # 0a:20 (0a:1c) 46  -  
    TCMIY  3        # 0a:21 (0a:38) 6c  -  
    TCY    9        # 0a:22 (0a:31) 49  -  
    RBIT   0        # 0a:23 (0a:23) 34  -  
    LDP    5        # 0a:24 (0a:06) 1a  -  
    BR     02       # 0a:25 (0a:0d) 83  -  
    LDP    9        # 0a:26 (0a:1b) 19  -  
    BR     3b       # 0a:27 (0a:36) aa  -  
    LDX    0        # 0a:28 (0a:2d) 28  -  
    TCY    6        # 0a:29 (0a:1a) 46  -  
    TMY             # 0a:2a (0a:34) 22  -  
    RETN            # 0a:2b (0a:29) 0f  -  
    YNEC   3        # 0a:2c (0a:12) 5c  -  
    BR     26       # 0a:2d (0a:24) 9b  -  
    CALL   02       # 0a:2e (0a:08) c3  -  
    TBIT   2        # 0a:2f (0a:11) 39  -  
    BR     32       # 0a:30 (0a:22) 89  -  
    BR     38       # 0a:31 (0a:04) a5  -  
    LDP    f        # 0a:32 (0a:09) 1f  -  
    CALL   12       # 0a:33 (0a:13) dd  -  
    LDP    c        # 0a:34 (0a:26) 13  -  
    CALL   02       # 0a:35 (0a:0c) c3  -  
    CALL   02       # 0a:36 (0a:19) c3  -  
    RBIT   2        # 0a:37 (0a:32) 35  -  
    LDP    8        # 0a:38 (0a:25) 11  -  
    CALL   02       # 0a:39 (0a:0a) c3  -  
    BR     18       # 0a:3a (0a:15) 98  -  
    LDP    2        # 0a:3b (0a:2a) 14  -  
    TPC            # 0a:3c (0a:14) 0b  -  
    LDP    a        # 0a:3d (0a:28) 15  -  
    BR     32       # 0a:3e (0a:10) 89  -  
    MNEA            # 0a:3f (0a:20) 00  -  

# -----------------------------------------------------------------------------
# Page 0b

    LDP    0        # 0b:00 (0b:00) 10  -  
    BR     00       # 0b:01 (0b:01) 80  -  
    LDX    0        # 0b:02 (0b:03) 28  -  
    TCY    f        # 0b:03 (0b:07) 4f  -  
    TBIT   0        # 0b:04 (0b:0f) 38  -  
    BR     08       # 0b:05 (0b:1f) bd  -  
    LDP    6        # 0b:06 (0b:3f) 16  -  
    BR     1b       # 0b:07 (0b:3e) 82  -  
    TCY    7        # 0b:08 (0b:3d) 4e  -  
    MNEZ            # 0b:09 (0b:3b) 3f  -  
    BR     1c       # 0b:0a (0b:37) 85  -  
    IMAC            # 0b:0b (0b:2f) 3e  -  
    TAM             # 0b:0c (0b:1e) 27  -  
    TCY    2        # 0b:0d (0b:3c) 44  -  
    CLA             # 0b:0e (0b:39) 7f  -  
    XMA             # 0b:0f (0b:33) 03  -  
    DYN             # 0b:10 (0b:27) 04  -  
    BR     0f       # 0b:11 (0b:0e) b3  -  
    RETN            # 0b:12 (0b:1d) 0f  -  
    TCY    6        # 0b:13 (0b:3a) 46  -  
    DMAN            # 0b:14 (0b:35) 07  -  
    TAM             # 0b:15 (0b:2b) 27  -  
    LDP    f        # 0b:16 (0b:16) 1f  -  
    CALL   02       # 0b:17 (0b:2c) c3  -  
    LDP    8        # 0b:18 (0b:18) 11  -  
    CALL   39       # 0b:19 (0b:30) ca  -  
    LDP    9        # 0b:1a (0b:21) 19  -  
    BR     3b       # 0b:1b (0b:02) aa  -  
    TCY    7        # 0b:1c (0b:05) 4e  -  
    LDP    0        # 0b:1d (0b:0b) 10  -  
    CALL   07       # 0b:1e (0b:17) fe  -  
    BR     16       # 0b:1f (0b:2e) 96  -  
    LDX    1        # 0b:20 (0b:1c) 2c  -  
    TCY    5        # 0b:21 (0b:38) 4a  -  
    LDP    c        # 0b:22 (0b:31) 13  -  
    CALL   1a       # 0b:23 (0b:23) e1  -  
    TCY    0        # 0b:24 (0b:06) 40  -  
    CLA             # 0b:25 (0b:0d) 7f  -  
    YNEA            # 0b:26 (0b:1b) 02  -  
    TCY    4        # 0b:27 (0b:36) 42  -  
    TMA             # 0b:28 (0b:2d) 21  -  
    TDO             # 0b:29 (0b:1a) 0a  -  
    RETN            # 0b:2a (0b:34) 0f  -  
    LDP    5        # 0b:2b (0b:29) 1a  -  
    BR     02       # 0b:2c (0b:12) 83  -  
    LDX    5        # 0b:2d (0b:24) 2d  -  
    TCY    d        # 0b:2e (0b:08) 4b  -  
    IMAC            # 0b:2f (0b:11) 3e  -  
    BR     33       # 0b:30 (0b:22) 93  -  
    TAM             # 0b:31 (0b:04) 27  -  
    RETN            # 0b:32 (0b:09) 0f  -  
    TAMIYC          # 0b:33 (0b:13) 25  -  
    BR     32       # 0b:34 (0b:26) 89  -  
    BR     2f       # 0b:35 (0b:0c) 91  -  
    LDX    0        # 0b:36 (0b:19) 28  -  
    TCY    d        # 0b:37 (0b:32) 4b  -  
    TBIT   3        # 0b:38 (0b:25) 3b  -  
    BR     3c       # 0b:39 (0b:0a) 94  -  
    LDP    5        # 0b:3a (0b:15) 1a  -  
    BR     18       # 0b:3b (0b:2a) 98  -  
    LDP    3        # 0b:3c (0b:14) 1c  -  
    TPC            # 0b:3d (0b:28) 0b  -  
    LDP    8        # 0b:3e (0b:10) 11  -  
    BR     00       # 0b:3f (0b:20) 80  -  

# -----------------------------------------------------------------------------
# Page 0c

    LDP    0        # 0c:00 (0c:00) 10  -  
    BR     00       # 0c:01 (0c:01) 80  -  
    LDP    f        # 0c:02 (0c:03) 1f  -  
    CALL   0a       # 0c:03 (0c:07) f7  -  
    LDP    b        # 0c:04 (0c:0f) 1d  -  
    CALL   20       # 0c:05 (0c:1f) dc  -  
    TCY    2        # 0c:06 (0c:3f) 44  -  
    CALL   11       # 0c:07 (0c:3e) ce  -  
    TCY    5        # 0c:08 (0c:3d) 4a  -  
    SETR            # 0c:09 (0c:3b) 0d  -  
    TCY    1        # 0c:0a (0c:37) 48  -  
    CALL   11       # 0c:0b (0c:2f) ce  -  
    TCY    5        # 0c:0c (0c:1e) 4a  -  
    RSTR            # 0c:0d (0c:3c) 0c  -  
    TCY    4        # 0c:0e (0c:39) 42  -  
    SETR            # 0c:0f (0c:33) 0d  -  
    TCY    0        # 0c:10 (0c:27) 40  -  
    TMA             # 0c:11 (0c:0e) 21  -  
    LDP    e        # 0c:12 (0c:1d) 17  -  
    CALL   02       # 0c:13 (0c:3a) c3  -  
    TCY    d        # 0c:14 (0c:35) 4b  -  
    SETR            # 0c:15 (0c:2b) 0d  -  
    TCY    d        # 0c:16 (0c:16) 4b  -  
    TCY    d        # 0c:17 (0c:2c) 4b  -  
    RSTR            # 0c:18 (0c:18) 0c  -  
    RETN            # 0c:19 (0c:30) 0f  -  
    TMA             # 0c:1a (0c:21) 21  -  
    TCY    f        # 0c:1b (0c:02) 4f  -  
    TAM             # 0c:1c (0c:05) 27  -  
    TCY    6        # 0c:1d (0c:0b) 46  -  
    RSTR            # 0c:1e (0c:17) 0c  -  
    DYN             # 0c:1f (0c:2e) 04  -  
    BR     1e       # 0c:20 (0c:1c) 97  -  
    TCY    f        # 0c:21 (0c:38) 4f  -  
    TBIT   0        # 0c:22 (0c:31) 38  -  
    BR     2b       # 0c:23 (0c:23) a9  -  
    TBIT   1        # 0c:24 (0c:06) 3a  -  
    BR     2f       # 0c:25 (0c:0d) 91  -  
    TBIT   2        # 0c:26 (0c:1b) 39  -  
    BR     33       # 0c:27 (0c:36) 93  -  
    TBIT   3        # 0c:28 (0c:2d) 3b  -  
    BR     37       # 0c:29 (0c:1a) b2  -  
    RETN            # 0c:2a (0c:34) 0f  -  
    TCY    0        # 0c:2b (0c:29) 40  -  
    SETR            # 0c:2c (0c:12) 0d  -  
    TCY    f        # 0c:2d (0c:24) 4f  -  
    BR     24       # 0c:2e (0c:08) 86  -  
    TCY    1        # 0c:2f (0c:11) 48  -  
    SETR            # 0c:30 (0c:22) 0d  -  
    TCY    f        # 0c:31 (0c:04) 4f  -  
    BR     26       # 0c:32 (0c:09) 9b  -  
    TCY    2        # 0c:33 (0c:13) 44  -  
    SETR            # 0c:34 (0c:26) 0d  -  
    TCY    f        # 0c:35 (0c:0c) 4f  -  
    BR     28       # 0c:36 (0c:19) ad  -  
    TCY    3        # 0c:37 (0c:32) 4c  -  
    SETR            # 0c:38 (0c:25) 0d  -  
    BR     2a       # 0c:39 (0c:0a) b4  -  
    RETN            # 0c:3a (0c:15) 0f  -  
    LDP    1        # 0c:3b (0c:2a) 18  -  
    TPC            # 0c:3c (0c:14) 0b  -  
    LDP    7        # 0c:3d (0c:28) 1e  -  
    BR     29       # 0c:3e (0c:10) 9a  -  
    MNEA            # 0c:3f (0c:20) 00  -  

# -----------------------------------------------------------------------------
# Page 0d

    LDP    0        # 0d:00 (0d:00) 10  -  
    BR     00       # 0d:01 (0d:01) 80  -  
    TCY    5        # 0d:02 (0d:03) 4a  -  
    RSTR            # 0d:03 (0d:07) 0c  -  
    DYN             # 0d:04 (0d:0f) 04  -  
    BR     03       # 0d:05 (0d:1f) 87  -  
    TCY    7        # 0d:06 (0d:3f) 4e  -  
    TBIT   2        # 0d:07 (0d:3e) 39  -  
    BR     38       # 0d:08 (0d:3d) a5  -  
    TBIT   3        # 0d:09 (0d:3b) 3b  -  
    BR     3d       # 0d:0a (0d:37) a8  -  
    TCY    5        # 0d:0b (0d:2f) 4a  -  
    CLA             # 0d:0c (0d:1e) 7f  -  
    YNEA            # 0d:0d (0d:3c) 02  -  
    TCY    c        # 0d:0e (0d:39) 43  -  
    SETR            # 0d:0f (0d:33) 0d  -  
    TCY    e        # 0d:10 (0d:27) 47  -  
    TMY             # 0d:11 (0d:0e) 22  -  
    TMA             # 0d:12 (0d:1d) 21  -  
    TDO             # 0d:13 (0d:3a) 0a  -  
    SETR            # 0d:14 (0d:35) 0d  -  
    TYA             # 0d:15 (0d:2b) 23  -  
    TCY    8        # 0d:16 (0d:16) 41  -  
    TAMZA           # 0d:17 (0d:2c) 26  -  
    ACxAC  0        # 0d:18 (0d:18) 70  -  
    BR     1b       # 0d:19 (0d:30) 82  -  
    BR     18       # 0d:1a (0d:21) 98  -  
    TCY    8        # 0d:1b (0d:02) 41  -  
    TMY             # 0d:1c (0d:05) 22  -  
    RSTR            # 0d:1d (0d:0b) 0c  -  
    BR     28       # 0d:1e (0d:17) ad  -  
    TCY    c        # 0d:1f (0d:2e) 43  -  
    RSTR            # 0d:20 (0d:1c) 0c  -  
    TCY    0        # 0d:21 (0d:38) 40  -  
    CLA             # 0d:22 (0d:31) 7f  -  
    YNEA            # 0d:23 (0d:23) 02  -  
    TDO             # 0d:24 (0d:06) 0a  -  
    RETN            # 0d:25 (0d:0d) 0f  -  
    LDP    9        # 0d:26 (0d:1b) 19  -  
    BR     3b       # 0d:27 (0d:36) aa  -  
    TCY    8        # 0d:28 (0d:2d) 41  -  
    DMAN            # 0d:29 (0d:1a) 07  -  
    BR     2c       # 0d:2a (0d:34) 92  -  
    BR     1f       # 0d:2b (0d:29) ae  -  
    TAM             # 0d:2c (0d:12) 27  -  
    TCY    7        # 0d:2d (0d:24) 4e  -  
    TBIT   1        # 0d:2e (0d:08) 3a  -  
    BR     35       # 0d:2f (0d:11) 8c  -  
    TCY    8        # 0d:30 (0d:22) 41  -  
    TMY             # 0d:31 (0d:04) 22  -  
    YNEC   3        # 0d:32 (0d:09) 5c  -  
    BR     35       # 0d:33 (0d:13) 8c  -  
    BR     28       # 0d:34 (0d:26) ad  -  
    TCY    8        # 0d:35 (0d:0c) 41  -  
    TMY             # 0d:36 (0d:19) 22  -  
    BR     12       # 0d:37 (0d:32) 9d  -  
    LDP    1        # 0d:38 (0d:25) 18  -  
    TPC            # 0d:39 (0d:0a) 0b  -  
    LDP    3        # 0d:3a (0d:15) 1c  -  
    CALL   1f       # 0d:3b (0d:2a) ee  -  
    BR     0b       # 0d:3c (0d:14) af  -  
    LDP    a        # 0d:3d (0d:28) 15  -  
    BR     3b       # 0d:3e (0d:10) aa  -  
    MNEA            # 0d:3f (0d:20) 00  -  

# -----------------------------------------------------------------------------
# Page 0e

    LDP    0        # 0e:00 (0e:00) 10  -  
    BR     00       # 0e:01 (0e:01) 80  -  
    TCY    f        # 0e:02 (0e:03) 4f  -  
    TAM             # 0e:03 (0e:07) 27  -  
    TBIT   0        # 0e:04 (0e:0f) 38  -  
    BR     18       # 0e:05 (0e:1f) 98  -  
    TCY    7        # 0e:06 (0e:3f) 4e  -  
    RSTR            # 0e:07 (0e:3e) 0c  -  
    TCY    f        # 0e:08 (0e:3d) 4f  -  
    TBIT   1        # 0e:09 (0e:3b) 3a  -  
    BR     1b       # 0e:0a (0e:37) 82  -  
    TCY    8        # 0e:0b (0e:2f) 41  -  
    RSTR            # 0e:0c (0e:1e) 0c  -  
    TCY    f        # 0e:0d (0e:3c) 4f  -  
    TBIT   2        # 0e:0e (0e:39) 39  -  
    BR     1e       # 0e:0f (0e:33) 97  -  
    TCY    9        # 0e:10 (0e:27) 49  -  
    RSTR            # 0e:11 (0e:0e) 0c  -  
    TCY    f        # 0e:12 (0e:1d) 4f  -  
    TBIT   3        # 0e:13 (0e:3a) 3b  -  
    BR     21       # 0e:14 (0e:35) b8  -  
    TCY    a        # 0e:15 (0e:2b) 45  -  
    RSTR            # 0e:16 (0e:16) 0c  -  
    RETN            # 0e:17 (0e:2c) 0f  -  
    TCY    7        # 0e:18 (0e:18) 4e  -  
    SETR            # 0e:19 (0e:30) 0d  -  
    BR     08       # 0e:1a (0e:21) bd  -  
    TCY    8        # 0e:1b (0e:02) 41  -  
    SETR            # 0e:1c (0e:05) 0d  -  
    BR     0d       # 0e:1d (0e:0b) bc  -  
    TCY    9        # 0e:1e (0e:17) 49  -  
    SETR            # 0e:1f (0e:2e) 0d  -  
    BR     12       # 0e:20 (0e:1c) 9d  -  
    TCY    a        # 0e:21 (0e:38) 45  -  
    SETR            # 0e:22 (0e:31) 0d  -  
    RETN            # 0e:23 (0e:23) 0f  -  
    TCY    d        # 0e:24 (0e:06) 4b  -  
    TBIT   1        # 0e:25 (0e:0d) 3a  -  
    BR     30       # 0e:26 (0e:1b) a2  -  
    TBIT   2        # 0e:27 (0e:36) 39  -  
    BR     34       # 0e:28 (0e:2d) a6  -  
    TCY    8        # 0e:29 (0e:1a) 41  -  
    TBIT   0        # 0e:2a (0e:34) 38  -  
    BR     2e       # 0e:2b (0e:29) 88  -  
    LDP    1        # 0e:2c (0e:12) 18  -  
    BR     35       # 0e:2d (0e:24) 8c  -  
    LDP    8        # 0e:2e (0e:08) 11  -  
    BR     02       # 0e:2f (0e:11) 83  -  
    LDP    1        # 0e:30 (0e:22) 18  -  
    TPC            # 0e:31 (0e:04) 0b  -  
    LDP    8        # 0e:32 (0e:09) 11  -  
    BR     04       # 0e:33 (0e:13) 8f  -  
    LDP    7        # 0e:34 (0e:26) 1e  -  
    BR     31       # 0e:35 (0e:0c) 84  -  
    CLA             # 0e:36 (0e:19) 7f  -  
    ACxAC  0        # 0e:37 (0e:32) 70  -  
    BR     3a       # 0e:38 (0e:25) 95  -  
    BR     37       # 0e:39 (0e:0a) b2  -  
    CLA             # 0e:3a (0e:15) 7f  -  
    ACxAC  0        # 0e:3b (0e:2a) 70  -  
    BR     3e       # 0e:3c (0e:14) 90  -  
    BR     3b       # 0e:3d (0e:28) aa  -  
    LDP    2        # 0e:3e (0e:10) 14  -  
    BR     35       # 0e:3f (0e:20) 8c  -  

# -----------------------------------------------------------------------------
# Page 0f

    LDP    0        # 0f:00 (0f:00) 10  -  
    BR     00       # 0f:01 (0f:01) 80  -  
    TCY    2        # 0f:02 (0f:03) 44  -  
    LDX    0        # 0f:03 (0f:07) 28  -  
    TMA             # 0f:04 (0f:0f) 21  -  
    LDX    3        # 0f:05 (0f:1f) 2e  -  
    TAM             # 0f:06 (0f:3f) 27  -  
    DYN             # 0f:07 (0f:3e) 04  -  
    BR     03       # 0f:08 (0f:3d) 87  -  
    RETN            # 0f:09 (0f:3b) 0f  -  
    TCY    2        # 0f:0a (0f:37) 44  -  
    LDX    3        # 0f:0b (0f:2f) 2e  -  
    TMA             # 0f:0c (0f:1e) 21  -  
    LDX    1        # 0f:0d (0f:3c) 2c  -  
    TAM             # 0f:0e (0f:39) 27  -  
    DYN             # 0f:0f (0f:33) 04  -  
    BR     0b       # 0f:10 (0f:27) af  -  
    RETN            # 0f:11 (0f:0e) 0f  -  
    TCY    2        # 0f:12 (0f:1d) 44  -  
    LDX    0        # 0f:13 (0f:3a) 28  -  
    TMA             # 0f:14 (0f:35) 21  -  
    LDX    1        # 0f:15 (0f:2b) 2c  -  
    TAM             # 0f:16 (0f:16) 27  -  
    DYN             # 0f:17 (0f:2c) 04  -  
    BR     13       # 0f:18 (0f:18) ba  -  
    RETN            # 0f:19 (0f:30) 0f  -  
    TCY    2        # 0f:1a (0f:21) 44  -  
    LDX    1        # 0f:1b (0f:02) 2c  -  
    TMA             # 0f:1c (0f:05) 21  -  
    LDX    3        # 0f:1d (0f:0b) 2e  -  
    TAM             # 0f:1e (0f:17) 27  -  
    DYN             # 0f:1f (0f:2e) 04  -  
    BR     1b       # 0f:20 (0f:1c) 82  -  
    RETN            # 0f:21 (0f:38) 0f  -  
    TCY    1        # 0f:22 (0f:31) 48  -  
    LDX    0        # 0f:23 (0f:23) 28  -  
    TMA             # 0f:24 (0f:06) 21  -  
    LDX    2        # 0f:25 (0f:0d) 2a  -  
    TAM             # 0f:26 (0f:1b) 27  -  
    DYN             # 0f:27 (0f:36) 04  -  
    BR     23       # 0f:28 (0f:2d) a3  -  
    RETN            # 0f:29 (0f:1a) 0f  -  
    LDX    0        # 0f:2a (0f:34) 28  -  
    TCY    0        # 0f:2b (0f:29) 40  -  
    TMA             # 0f:2c (0f:12) 21  -  
    TCY    4        # 0f:2d (0f:24) 42  -  
    TAM             # 0f:2e (0f:08) 27  -  
    TCY    1        # 0f:2f (0f:11) 48  -  
    TMA             # 0f:30 (0f:22) 21  -  
    TCY    5        # 0f:31 (0f:04) 4a  -  
    TAM             # 0f:32 (0f:09) 27  -  
    RETN            # 0f:33 (0f:13) 0f  -  
    TCY    4        # 0f:34 (0f:26) 42  -  
    CALL   37       # 0f:35 (0f:0c) f2  -  
    TCY    5        # 0f:36 (0f:19) 4a  -  
    LDX    0        # 0f:37 (0f:32) 28  -  
    TMA             # 0f:38 (0f:25) 21  -  
    LDX    2        # 0f:39 (0f:0a) 2a  -  
    TAM             # 0f:3a (0f:15) 27  -  
    LDX    3        # 0f:3b (0f:2a) 2e  -  
    TAM             # 0f:3c (0f:14) 27  -  
    RETN            # 0f:3d (0f:28) 0f  -  
    MNEA            # 0f:3e (0f:10) 00  -  
    MNEA            # 0f:3f (0f:20) 00  -  

# -----------------------------------------------------------------------------
# Page 10

    LDP    3        # 10:00 (10:00) 1c  -  
    CALL   14       # 10:01 (10:01) f5  -  
    LDX    1        # 10:02 (10:03) 2c  -  
    TCY    2        # 10:03 (10:07) 44  -  
    TMA             # 10:04 (10:0f) 21  -  
    ACxAC  0        # 10:05 (10:1f) 70  -  
    BR     3b       # 10:06 (10:3f) aa  -  
    TMA             # 10:07 (10:3e) 21  -  
    ACxAC  1        # 10:08 (10:3d) 78  -  
    BR     39       # 10:09 (10:3b) 8a  -  
    TMA             # 10:0a (10:37) 21  -  
    ACxAC  2        # 10:0b (10:2f) 74  -  
    BR     37       # 10:0c (10:1e) b2  -  
    TMA             # 10:0d (10:3c) 21  -  
    ACxAC  3        # 10:0e (10:39) 7c  -  
    BR     35       # 10:0f (10:33) 8c  -  
    TMA             # 10:10 (10:27) 21  -  
    ACxAC  4        # 10:11 (10:0e) 72  -  
    BR     33       # 10:12 (10:1d) 93  -  
    TMA             # 10:13 (10:3a) 21  -  
    ACxAC  5        # 10:14 (10:35) 7a  -  
    BR     31       # 10:15 (10:2b) 84  -  
    TMA             # 10:16 (10:16) 21  -  
    ACxAC  6        # 10:17 (10:2c) 76  -  
    BR     2f       # 10:18 (10:18) 91  -  
    TMA             # 10:19 (10:30) 21  -  
    ACxAC  7        # 10:1a (10:21) 7e  -  
    BR     2d       # 10:1b (10:02) a4  -  
    TMA             # 10:1c (10:05) 21  -  
    ACxAC  8        # 10:1d (10:0b) 71  -  
    BR     2b       # 10:1e (10:17) a9  -  
    TMA             # 10:1f (10:2e) 21  -  
    ACxAC  9        # 10:20 (10:1c) 79  -  
    BR     29       # 10:21 (10:38) 9a  -  
    TMA             # 10:22 (10:31) 21  -  
    ACxAC  a        # 10:23 (10:23) 75  -  
    BR     27       # 10:24 (10:06) b6  -  
    LDP    1        # 10:25 (10:0d) 18  -  
    BR     00       # 10:26 (10:1b) 80  -  
    LDP    7        # 10:27 (10:36) 1e  -  
    BR     1d       # 10:28 (10:2d) 8b  -  
    LDP    6        # 10:29 (10:1a) 16  -  
    BR     1b       # 10:2a (10:34) 82  -  
    LDP    6        # 10:2b (10:29) 16  -  
    BR     16       # 10:2c (10:12) 96  -  
    LDP    6        # 10:2d (10:24) 16  -  
    BR     03       # 10:2e (10:08) 87  -  
    LDP    6        # 10:2f (10:11) 16  -  
    BR     00       # 10:30 (10:22) 80  -  
    LDP    c        # 10:31 (10:04) 13  -  
    BR     00       # 10:32 (10:09) 80  -  
    LDP    4        # 10:33 (10:13) 12  -  
    BR     2c       # 10:34 (10:26) 92  -  
    LDP    4        # 10:35 (10:0c) 12  -  
    BR     00       # 10:36 (10:19) 80  -  
    LDP    4        # 10:37 (10:32) 12  -  
    BR     1f       # 10:38 (10:25) ae  -  
    LDP    4        # 10:39 (10:0a) 12  -  
    BR     27       # 10:3a (10:15) b6  -  
    LDP    1        # 10:3b (10:2a) 18  -  
    BR     17       # 10:3c (10:14) ac  -  
    MNEA            # 10:3d (10:28) 00  -  
    MNEA            # 10:3e (10:10) 00  -  
    MNEA            # 10:3f (10:20) 00  -  

# -----------------------------------------------------------------------------
# Page 11

    TMA             # 11:00 (11:00) 21  -  
    ACxAC  b        # 11:01 (11:01) 7d  -  
    BR     15       # 11:02 (11:03) ab  -  
    TMA             # 11:03 (11:07) 21  -  
    ACxAC  c        # 11:04 (11:0f) 73  -  
    BR     13       # 11:05 (11:1f) ba  -  
    TMA             # 11:06 (11:3f) 21  -  
    ACxAC  d        # 11:07 (11:3e) 7b  -  
    BR     11       # 11:08 (11:3d) 8e  -  
    TMA             # 11:09 (11:3b) 21  -  
    ACxAC  0        # 11:0a (11:37) 70  -  
    ACxAC  d        # 11:0b (11:2f) 7b  -  
    BR     0f       # 11:0c (11:1e) b3  -  
    LDP    7        # 11:0d (11:3c) 1e  -  
    BR     25       # 11:0e (11:39) 8d  -  
    LDP    7        # 11:0f (11:33) 1e  -  
    BR     27       # 11:10 (11:27) b6  -  
    LDP    5        # 11:11 (11:0e) 1a  -  
    BR     14       # 11:12 (11:1d) b5  -  
    LDP    5        # 11:13 (11:3a) 1a  -  
    BR     0d       # 11:14 (11:35) bc  -  
    LDP    7        # 11:15 (11:2b) 1e  -  
    BR     00       # 11:16 (11:16) 80  -  
    TCY    1        # 11:17 (11:2c) 48  -  
    TMA             # 11:18 (11:18) 21  -  
    ACxAC  0        # 11:19 (11:30) 70  -  
    BR     3b       # 11:1a (11:21) aa  -  
    TMA             # 11:1b (11:02) 21  -  
    ACxAC  1        # 11:1c (11:05) 78  -  
    BR     39       # 11:1d (11:0b) 8a  -  
    TMA             # 11:1e (11:17) 21  -  
    ACxAC  2        # 11:1f (11:2e) 74  -  
    BR     37       # 11:20 (11:1c) b2  -  
    TMA             # 11:21 (11:38) 21  -  
    ACxAC  3        # 11:22 (11:31) 7c  -  
    BR     35       # 11:23 (11:23) 8c  -  
    TMA             # 11:24 (11:06) 21  -  
    ACxAC  4        # 11:25 (11:0d) 72  -  
    BR     33       # 11:26 (11:1b) 93  -  
    TMA             # 11:27 (11:36) 21  -  
    ACxAC  5        # 11:28 (11:2d) 7a  -  
    BR     31       # 11:29 (11:1a) 84  -  
    TMA             # 11:2a (11:34) 21  -  
    ACxAC  6        # 11:2b (11:29) 76  -  
    BR     2f       # 11:2c (11:12) 91  -  
    LDP    2        # 11:2d (11:24) 14  -  
    BR     00       # 11:2e (11:08) 80  -  
    LDP    a        # 11:2f (11:11) 15  -  
    BR     00       # 11:30 (11:22) 80  -  
    LDP    a        # 11:31 (11:04) 15  -  
    BR     29       # 11:32 (11:09) 9a  -  
    LDP    9        # 11:33 (11:13) 19  -  
    BR     0d       # 11:34 (11:26) bc  -  
    LDP    9        # 11:35 (11:0c) 19  -  
    BR     00       # 11:36 (11:19) 80  -  
    LDP    8        # 11:37 (11:32) 11  -  
    BR     20       # 11:38 (11:25) 9c  -  
    LDP    8        # 11:39 (11:0a) 11  -  
    BR     10       # 11:3a (11:15) a7  -  
    LDP    8        # 11:3b (11:2a) 11  -  
    BR     00       # 11:3c (11:14) 80  -  
    MNEA            # 11:3d (11:28) 00  -  
    MNEA            # 11:3e (11:10) 00  -  
    MNEA            # 11:3f (11:20) 00  -  

# -----------------------------------------------------------------------------
# Page 12

    TMA             # 12:00 (12:00) 21  -  
    ACxAC  7        # 12:01 (12:01) 7e  -  
    BR     14       # 12:02 (12:03) b5  -  
    TMA             # 12:03 (12:07) 21  -  
    ACxAC  8        # 12:04 (12:0f) 71  -  
    BR     0a       # 12:05 (12:1f) b7  -  
    MNEZ            # 12:06 (12:3f) 3f  -  
    BR     16       # 12:07 (12:3e) 96  -  
    LDP    d        # 12:08 (12:3d) 1b  -  
    BR     27       # 12:09 (12:3b) b6  -  
    LDX    1        # 12:0a (12:37) 2c  -  
    TCY    0        # 12:0b (12:2f) 40  -  
    TMY             # 12:0c (12:1e) 22  -  
    LDX    7        # 12:0d (12:3c) 2f  -  
    TMA             # 12:0e (12:39) 21  -  
    LDX    6        # 12:0f (12:33) 2b  -  
    TAM             # 12:10 (12:27) 27  -  
    LDX    7        # 12:11 (12:0e) 2f  -  
    LDP    8        # 12:12 (12:1d) 11  -  
    BR     38       # 12:13 (12:3a) a5  -  
    LDP    b        # 12:14 (12:35) 1d  -  
    BR     1f       # 12:15 (12:2b) ae  -  
    LDP    3        # 12:16 (12:16) 1c  -  
    BR     00       # 12:17 (12:2c) 80  -  
    TCY    0        # 12:18 (12:18) 40  -  
    LDX    4        # 12:19 (12:30) 29  -  
    TMA             # 12:1a (12:21) 21  -  
    LDX    7        # 12:1b (12:02) 2f  -  
    RETN            # 12:1c (12:05) 0f  -  
    TCY    a        # 12:1d (12:0b) 45  -  
    TAM             # 12:1e (12:17) 27  -  
    TCY    1        # 12:1f (12:2e) 48  -  
    CALL   19       # 12:20 (12:1c) f0  -  
    TCY    b        # 12:21 (12:38) 4d  -  
    TAM             # 12:22 (12:31) 27  -  
    TCY    2        # 12:23 (12:23) 44  -  
    CALL   19       # 12:24 (12:06) f0  -  
    TCY    c        # 12:25 (12:0d) 43  -  
    TAM             # 12:26 (12:1b) 27  -  
    TCY    3        # 12:27 (12:36) 4c  -  
    CALL   19       # 12:28 (12:2d) f0  -  
    TCY    d        # 12:29 (12:1a) 4b  -  
    TAM             # 12:2a (12:34) 27  -  
    TCY    4        # 12:2b (12:29) 42  -  
    CALL   19       # 12:2c (12:12) f0  -  
    TCY    e        # 12:2d (12:24) 47  -  
    TAM             # 12:2e (12:08) 27  -  
    TCY    5        # 12:2f (12:11) 4a  -  
    CALL   19       # 12:30 (12:22) f0  -  
    TCY    f        # 12:31 (12:04) 4f  -  
    TAM             # 12:32 (12:09) 27  -  
    LDP    e        # 12:33 (12:13) 17  -  
    BR     32       # 12:34 (12:26) 89  -  
    TCY    5        # 12:35 (12:0c) 4a  -  
    LDX    1        # 12:36 (12:19) 2c  -  
    TMA             # 12:37 (12:32) 21  -  
    LDX    3        # 12:38 (12:25) 2e  -  
    TAM             # 12:39 (12:0a) 27  -  
    DYN             # 12:3a (12:15) 04  -  
    BR     36       # 12:3b (12:2a) 99  -  
    RETN            # 12:3c (12:14) 0f  -  
    MNEA            # 12:3d (12:28) 00  -  
    MNEA            # 12:3e (12:10) 00  -  
    MNEA            # 12:3f (12:20) 00  -  

# -----------------------------------------------------------------------------
# Page 13

    LDX    1        # 13:00 (13:00) 2c  -  
    TCY    1        # 13:01 (13:01) 48  -  
    TMA             # 13:02 (13:03) 21  -  
    LDX    3        # 13:03 (13:07) 2e  -  
    TCY    a        # 13:04 (13:0f) 45  -  
    TAM             # 13:05 (13:1f) 27  -  
    ACxAC  e        # 13:06 (13:3f) 77  -  
    TCY    e        # 13:07 (13:3e) 47  -  
    TAM             # 13:08 (13:3d) 27  -  
    ACxAC  9        # 13:09 (13:3b) 79  -  
    BR     1b       # 13:0a (13:37) 82  -  
    TCY    6        # 13:0b (13:2f) 46  -  
    TCMIY  1        # 13:0c (13:1e) 68  -  
    TCMIY  6        # 13:0d (13:3c) 66  -  
    LDX    1        # 13:0e (13:39) 2c  -  
    TCY    0        # 13:0f (13:33) 40  -  
    TMA             # 13:10 (13:27) 21  -  
    LDX    3        # 13:11 (13:0e) 2e  -  
    TCY    d        # 13:12 (13:1d) 4b  -  
    TAM             # 13:13 (13:3a) 27  -  
    LDP    0        # 13:14 (13:35) 10  -  
    TPC            # 13:15 (13:2b) 0b  -  
    LDP    8        # 13:16 (13:16) 11  -  
    CALL   39       # 13:17 (13:2c) ca  -  
    RETN            # 13:18 (13:18) 0f  -  
    LDP    e        # 13:19 (13:30) 17  -  
    BR     32       # 13:1a (13:21) 89  -  
    CLA             # 13:1b (13:02) 7f  -  
    ACxAC  5        # 13:1c (13:05) 7a  -  
    TCY    a        # 13:1d (13:0b) 45  -  
    BR     05       # 13:1e (13:17) 9f  -  
    TCY    c        # 13:1f (13:2e) 43  -  
    TCMIY  0        # 13:20 (13:1c) 60  -  
    TCY    d        # 13:21 (13:38) 4b  -  
    TMA             # 13:22 (13:31) 21  -  
    TCY    b        # 13:23 (13:23) 4d  -  
    TAM             # 13:24 (13:06) 27  -  
    LDX    3        # 13:25 (13:0d) 2e  -  
    TCY    b        # 13:26 (13:1b) 4d  -  
    TMY             # 13:27 (13:36) 22  -  
    LDX    7        # 13:28 (13:2d) 2f  -  
    TMA             # 13:29 (13:1a) 21  -  
    LDX    3        # 13:2a (13:34) 2e  -  
    TCY    c        # 13:2b (13:29) 43  -  
    TMY             # 13:2c (13:12) 22  -  
    TAM             # 13:2d (13:24) 27  -  
    TCY    c        # 13:2e (13:08) 43  -  
    IMAC            # 13:2f (13:11) 3e  -  
    TAM             # 13:30 (13:22) 27  -  
    TCY    b        # 13:31 (13:04) 4d  -  
    IMAC            # 13:32 (13:09) 3e  -  
    TAM             # 13:33 (13:13) 27  -  
    TCY    a        # 13:34 (13:26) 45  -  
    TMA             # 13:35 (13:0c) 21  -  
    TCY    c        # 13:36 (13:19) 43  -  
    TMY             # 13:37 (13:32) 22  -  
    YNEA            # 13:38 (13:25) 02  -  
    BR     25       # 13:39 (13:0a) 8d  -  
    RETN            # 13:3a (13:15) 0f  -  
    LDP    8        # 13:3b (13:2a) 11  -  
    CALL   3c       # 13:3c (13:14) d4  -  
    TKA             # 13:3d (13:28) 08  -  
    SETR            # 13:3e (13:10) 0d  -  
    MNEA            # 13:3f (13:20) 00  -  

# -----------------------------------------------------------------------------
# Page 14

    LDX    1        # 14:00 (14:00) 2c  -  
    LDP    0        # 14:01 (14:01) 10  -  
    TPC            # 14:02 (14:03) 0b  -  
    LDP    f        # 14:03 (14:07) 1f  -  
    CALL   2b       # 14:04 (14:0f) e9  -  
    TCY    4        # 14:05 (14:1f) 42  -  
    DMAN            # 14:06 (14:3f) 07  -  
    BR     1d       # 14:07 (14:3e) 8b  -  
    TAMIYC          # 14:08 (14:3d) 25  -  
    DMAN            # 14:09 (14:3b) 07  -  
    BR     1d       # 14:0a (14:37) 8b  -  
    TAM             # 14:0b (14:2f) 27  -  
    LDX    1        # 14:0c (14:1e) 2c  -  
    TCY    4        # 14:0d (14:3c) 42  -  
    TMA             # 14:0e (14:39) 21  -  
    LDX    2        # 14:0f (14:33) 2a  -  
    TAM             # 14:10 (14:27) 27  -  
    LDX    3        # 14:11 (14:0e) 2e  -  
    TAM             # 14:12 (14:1d) 27  -  
    LDX    1        # 14:13 (14:3a) 2c  -  
    TCY    5        # 14:14 (14:35) 4a  -  
    TMA             # 14:15 (14:2b) 21  -  
    LDX    2        # 14:16 (14:16) 2a  -  
    TAM             # 14:17 (14:2c) 27  -  
    LDX    3        # 14:18 (14:18) 2e  -  
    TAM             # 14:19 (14:30) 27  -  
    RETN            # 14:1a (14:21) 0f  -  
    LDP    8        # 14:1b (14:02) 11  -  
    BR     36       # 14:1c (14:05) 99  -  
    TAM             # 14:1d (14:0b) 27  -  
    BR     0c       # 14:1e (14:17) 9e  -  
    LDX    4        # 14:1f (14:2e) 29  -  
    TCY    d        # 14:20 (14:1c) 4b  -  
    TBIT   0        # 14:21 (14:38) 38  -  
    BR     00       # 14:22 (14:31) 80  -  
    LDP    0        # 14:23 (14:23) 10  -  
    TPC            # 14:24 (14:06) 0b  -  
    LDP    8        # 14:25 (14:0d) 11  -  
    BR     02       # 14:26 (14:1b) 83  -  
    LDX    4        # 14:27 (14:36) 29  -  
    TCY    d        # 14:28 (14:2d) 4b  -  
    TBIT   1        # 14:29 (14:1a) 3a  -  
    BR     00       # 14:2a (14:34) 80  -  
    BR     23       # 14:2b (14:29) a3  -  
    LDX    1        # 14:2c (14:12) 2c  -  
    TCY    0        # 14:2d (14:24) 40  -  
    TMA             # 14:2e (14:08) 21  -  
    TCY    4        # 14:2f (14:11) 42  -  
    XMA             # 14:30 (14:22) 03  -  
    TCY    d        # 14:31 (14:04) 4b  -  
    TAM             # 14:32 (14:09) 27  -  
    TCY    1        # 14:33 (14:13) 48  -  
    TMA             # 14:34 (14:26) 21  -  
    TCY    5        # 14:35 (14:0c) 4a  -  
    XMA             # 14:36 (14:19) 03  -  
    TCY    e        # 14:37 (14:32) 47  -  
    TAM             # 14:38 (14:25) 27  -  
    BR     05       # 14:39 (14:0a) 9f  -  
    LDP    0        # 14:3a (14:15) 10  -  
    TPC            # 14:3b (14:2a) 0b  -  
    LDP    0        # 14:3c (14:14) 10  -  
    CALL   3f       # 14:3d (14:28) e0  -  
    TAY             # 14:3e (14:10) 20  -  
    RETN            # 14:3f (14:20) 0f  -  

# -----------------------------------------------------------------------------
# Page 15

    LDX    1        # 15:00 (15:00) 2c  -  
    TCY    d        # 15:01 (15:01) 4b  -  
    TMA             # 15:02 (15:03) 21  -  
    TCY    4        # 15:03 (15:07) 42  -  
    TAM             # 15:04 (15:0f) 27  -  
    TCY    e        # 15:05 (15:1f) 47  -  
    TMA             # 15:06 (15:3f) 21  -  
    TCY    5        # 15:07 (15:3e) 4a  -  
    TAM             # 15:08 (15:3d) 27  -  
    LDP    4        # 15:09 (15:3b) 12  -  
    CALL   0c       # 15:0a (15:37) de  -  
    LDP    8        # 15:0b (15:2f) 11  -  
    BR     38       # 15:0c (15:1e) a5  -  
    LDP    6        # 15:0d (15:3c) 16  -  
    CALL   16       # 15:0e (15:39) d6  -  
    LDP    6        # 15:0f (15:33) 16  -  
    CALL   17       # 15:10 (15:27) ec  -  
    TCY    e        # 15:11 (15:0e) 47  -  
    TAM             # 15:12 (15:1d) 27  -  
    BR     1a       # 15:13 (15:3a) a1  -  
    LDP    6        # 15:14 (15:35) 16  -  
    CALL   1b       # 15:15 (15:2b) c2  -  
    LDP    6        # 15:16 (15:16) 16  -  
    CALL   20       # 15:17 (15:2c) dc  -  
    TCY    e        # 15:18 (15:18) 47  -  
    TAM             # 15:19 (15:30) 27  -  
    LDX    4        # 15:1a (15:21) 29  -  
    TCY    f        # 15:1b (15:02) 4f  -  
    TBIT   0        # 15:1c (15:05) 38  -  
    BR     21       # 15:1d (15:0b) b8  -  
    TCY    e        # 15:1e (15:17) 47  -  
    RBIT   0        # 15:1f (15:2e) 34  -  
    TCY    f        # 15:20 (15:1c) 4f  -  
    TBIT   1        # 15:21 (15:38) 3a  -  
    BR     26       # 15:22 (15:31) 9b  -  
    TCY    e        # 15:23 (15:23) 47  -  
    RBIT   1        # 15:24 (15:06) 36  -  
    TCY    f        # 15:25 (15:0d) 4f  -  
    TBIT   2        # 15:26 (15:1b) 39  -  
    BR     2b       # 15:27 (15:36) a9  -  
    TCY    e        # 15:28 (15:2d) 47  -  
    RBIT   2        # 15:29 (15:1a) 35  -  
    TCY    f        # 15:2a (15:34) 4f  -  
    TBIT   3        # 15:2b (15:29) 3b  -  
    BR     2f       # 15:2c (15:12) 91  -  
    TCY    e        # 15:2d (15:24) 47  -  
    RBIT   3        # 15:2e (15:08) 37  -  
    TCY    d        # 15:2f (15:11) 4b  -  
    RBIT   0        # 15:30 (15:22) 34  -  
    TCY    e        # 15:31 (15:04) 47  -  
    TMA             # 15:32 (15:09) 21  -  
    LDP    7        # 15:33 (15:13) 1e  -  
    BR     10       # 15:34 (15:26) a7  -  
    MNEA            # 15:35 (15:0c) 00  -  
    MNEA            # 15:36 (15:19) 00  -  
    MNEA            # 15:37 (15:32) 00  -  
    MNEA            # 15:38 (15:25) 00  -  
    MNEA            # 15:39 (15:0a) 00  -  
    MNEA            # 15:3a (15:15) 00  -  
    MNEA            # 15:3b (15:2a) 00  -  
    MNEA            # 15:3c (15:14) 00  -  
    MNEA            # 15:3d (15:28) 00  -  
    MNEA            # 15:3e (15:10) 00  -  
    MNEA            # 15:3f (15:20) 00  -  

# -----------------------------------------------------------------------------
# Page 16

    CALL   1b       # 16:00 (16:00) c2  -  
    CALL   17       # 16:01 (16:01) ec  -  
    BR     05       # 16:02 (16:03) 9f  -  
    CALL   1b       # 16:03 (16:07) c2  -  
    CALL   20       # 16:04 (16:0f) dc  -  
    SAMAN           # 16:05 (16:1f) 3c  -  
    BR     0a       # 16:06 (16:3f) b7  -  
    TCY    d        # 16:07 (16:3e) 4b  -  
    RBIT   0        # 16:08 (16:3d) 34  -  
    BR     0c       # 16:09 (16:3b) 9e  -  
    TCY    d        # 16:0a (16:37) 4b  -  
    SBIT   0        # 16:0b (16:2f) 30  -  
    CPAIZ           # 16:0c (16:1e) 3d  -  
    BR     12       # 16:0d (16:3c) 9d  -  
    TCY    d        # 16:0e (16:39) 4b  -  
    RBIT   1        # 16:0f (16:33) 36  -  
    LDP    e        # 16:10 (16:27) 17  -  
    BR     32       # 16:11 (16:0e) 89  -  
    TCY    d        # 16:12 (16:1d) 4b  -  
    SBIT   1        # 16:13 (16:3a) 32  -  
    RBIT   0        # 16:14 (16:35) 34  -  
    BR     10       # 16:15 (16:2b) a7  -  
    CALL   1b       # 16:16 (16:16) c2  -  
    LDX    1        # 16:17 (16:2c) 2c  -  
    TCY    1        # 16:18 (16:18) 48  -  
    TMA             # 16:19 (16:30) 21  -  
    BR     25       # 16:1a (16:21) 8d  -  
    LDX    1        # 16:1b (16:02) 2c  -  
    TCY    0        # 16:1c (16:05) 40  -  
    LDP    7        # 16:1d (16:0b) 1e  -  
    CALL   02       # 16:1e (16:17) c3  -  
    RETN            # 16:1f (16:2e) 0f  -  
    LDX    1        # 16:20 (16:1c) 2c  -  
    TCY    1        # 16:21 (16:38) 48  -  
    TMY             # 16:22 (16:31) 22  -  
    LDX    7        # 16:23 (16:23) 2f  -  
    TMA             # 16:24 (16:06) 21  -  
    LDX    4        # 16:25 (16:0d) 29  -  
    TCY    f        # 16:26 (16:1b) 4f  -  
    RETN            # 16:27 (16:36) 0f  -  
    SAMAN           # 16:28 (16:2d) 3c  -  
    BR     30       # 16:29 (16:1a) a2  -  
    TCY    d        # 16:2a (16:34) 4b  -  
    SBIT   0        # 16:2b (16:29) 30  -  
    TCY    f        # 16:2c (16:12) 4f  -  
    TAM             # 16:2d (16:24) 27  -  
    LDP    7        # 16:2e (16:08) 1e  -  
    BR     10       # 16:2f (16:11) a7  -  
    TCY    d        # 16:30 (16:22) 4b  -  
    RBIT   0        # 16:31 (16:04) 34  -  
    BR     2c       # 16:32 (16:09) 92  -  
    MNEA            # 16:33 (16:13) 00  -  
    MNEA            # 16:34 (16:26) 00  -  
    MNEA            # 16:35 (16:0c) 00  -  
    MNEA            # 16:36 (16:19) 00  -  
    MNEA            # 16:37 (16:32) 00  -  
    MNEA            # 16:38 (16:25) 00  -  
    MNEA            # 16:39 (16:0a) 00  -  
    MNEA            # 16:3a (16:15) 00  -  
    MNEA            # 16:3b (16:2a) 00  -  
    MNEA            # 16:3c (16:14) 00  -  
    MNEA            # 16:3d (16:28) 00  -  
    MNEA            # 16:3e (16:10) 00  -  
    MNEA            # 16:3f (16:20) 00  -  

# -----------------------------------------------------------------------------
# Page 17

    LDX    1        # 17:00 (17:00) 2c  -  
    TCY    1        # 17:01 (17:01) 48  -  
    TMY             # 17:02 (17:03) 22  -  
    LDX    7        # 17:03 (17:07) 2f  -  
    TMA             # 17:04 (17:0f) 21  -  
    TCY    f        # 17:05 (17:1f) 4f  -  
    LDX    4        # 17:06 (17:3f) 29  -  
    TAM             # 17:07 (17:3e) 27  -  
    RETN            # 17:08 (17:3d) 0f  -  
    LDP    a        # 17:09 (17:3b) 15  -  
    CALL   00       # 17:0a (17:37) c0  -  
    LDX    4        # 17:0b (17:2f) 29  -  
    AMAAC           # 17:0c (17:1e) 06  -  
    BR     1a       # 17:0d (17:3c) a1  -  
    TCY    d        # 17:0e (17:39) 4b  -  
    RBIT   0        # 17:0f (17:33) 34  -  
    LDX    1        # 17:10 (17:27) 2c  -  
    TCY    0        # 17:11 (17:0e) 40  -  
    TMY             # 17:12 (17:1d) 22  -  
    LDX    7        # 17:13 (17:3a) 2f  -  
    TAM             # 17:14 (17:35) 27  -  
    LDX    1        # 17:15 (17:2b) 2c  -  
    TCY    f        # 17:16 (17:16) 4f  -  
    TAM             # 17:17 (17:2c) 27  -  
    LDP    b        # 17:18 (17:18) 1d  -  
    BR     12       # 17:19 (17:30) 9d  -  
    TCY    d        # 17:1a (17:21) 4b  -  
    SBIT   0        # 17:1b (17:02) 30  -  
    BR     10       # 17:1c (17:05) a7  -  
    LDX    1        # 17:1d (17:0b) 2c  -  
    TCY    1        # 17:1e (17:17) 48  -  
    TMA             # 17:1f (17:2e) 21  -  
    LDX    4        # 17:20 (17:1c) 29  -  
    TCY    f        # 17:21 (17:38) 4f  -  
    TAM             # 17:22 (17:31) 27  -  
    RETN            # 17:23 (17:23) 0f  -  
    BR     09       # 17:24 (17:06) bb  -  
    CALL   00       # 17:25 (17:0d) c0  -  
    BR     10       # 17:26 (17:1b) a7  -  
    CALL   1d       # 17:27 (17:36) cb  -  
    BR     10       # 17:28 (17:2d) a7  -  
    LDX    0        # 17:29 (17:1a) 28  -  
    TCY    8        # 17:2a (17:34) 41  -  
    TBIT   0        # 17:2b (17:29) 38  -  
    BR     31       # 17:2c (17:12) 84  -  
    TBIT   3        # 17:2d (17:24) 3b  -  
    BR     31       # 17:2e (17:08) 84  -  
    LDP    8        # 17:2f (17:11) 11  -  
    BR     38       # 17:30 (17:22) a5  -  
    LDP    0        # 17:31 (17:04) 10  -  
    TPC            # 17:32 (17:09) 0b  -  
    LDP    8        # 17:33 (17:13) 11  -  
    BR     28       # 17:34 (17:26) ad  -  
    MNEA            # 17:35 (17:0c) 00  -  
    MNEA            # 17:36 (17:19) 00  -  
    MNEA            # 17:37 (17:32) 00  -  
    MNEA            # 17:38 (17:25) 00  -  
    MNEA            # 17:39 (17:0a) 00  -  
    MNEA            # 17:3a (17:15) 00  -  
    MNEA            # 17:3b (17:2a) 00  -  
    MNEA            # 17:3c (17:14) 00  -  
    MNEA            # 17:3d (17:28) 00  -  
    MNEA            # 17:3e (17:10) 00  -  
    MNEA            # 17:3f (17:20) 00  -  

# -----------------------------------------------------------------------------
# Page 18

    LDX    0        # 18:00 (18:00) 28  -  
    TCY    d        # 18:01 (18:01) 4b  -  
    TCMIY  3        # 18:02 (18:03) 6c  -  
    BR     38       # 18:03 (18:07) a5  -  
    TCY    f        # 18:04 (18:0f) 4f  -  
    TMA             # 18:05 (18:1f) 21  -  
    LDX    1        # 18:06 (18:3f) 2c  -  
    TCY    0        # 18:07 (18:3e) 40  -  
    TMY             # 18:08 (18:3d) 22  -  
    LDX    7        # 18:09 (18:3b) 2f  -  
    TAM             # 18:0a (18:37) 27  -  
    CALL   29       # 18:0b (18:2f) da  -  
    LDX    0        # 18:0c (18:1e) 28  -  
    TCY    d        # 18:0d (18:3c) 4b  -  
    TCMIY  0        # 18:0e (18:39) 60  -  
    BR     34       # 18:0f (18:33) a6  -  
    LDX    1        # 18:10 (18:27) 2c  -  
    TCY    0        # 18:11 (18:0e) 40  -  
    TMY             # 18:12 (18:1d) 22  -  
    LDX    7        # 18:13 (18:3a) 2f  -  
    TMA             # 18:14 (18:35) 21  -  
    CALL   29       # 18:15 (18:2b) da  -  
    LDX    3        # 18:16 (18:16) 2e  -  
    LDP    0        # 18:17 (18:2c) 10  -  
    TPC            # 18:18 (18:18) 0b  -  
    LDP    9        # 18:19 (18:30) 19  -  
    CALL   23       # 18:1a (18:21) e3  -  
    LDP    0        # 18:1b (18:02) 10  -  
    TPC            # 18:1c (18:05) 0b  -  
    LDP    e        # 18:1d (18:0b) 17  -  
    CALL   02       # 18:1e (18:17) c3  -  
    BR     34       # 18:1f (18:2e) a6  -  
    TCY    6        # 18:20 (18:1c) 46  -  
    SETR            # 18:21 (18:38) 0d  -  
    TKA             # 18:22 (18:31) 08  -  
    RSTR            # 18:23 (18:23) 0c  -  
    LDX    1        # 18:24 (18:06) 2c  -  
    TCY    0        # 18:25 (18:0d) 40  -  
    TMY             # 18:26 (18:1b) 22  -  
    LDX    7        # 18:27 (18:36) 2f  -  
    TAM             # 18:28 (18:2d) 27  -  
    MNEZ            # 18:29 (18:1a) 3f  -  
    BR     30       # 18:2a (18:34) a2  -  
    TCY    d        # 18:2b (18:29) 4b  -  
    LDX    4        # 18:2c (18:12) 29  -  
    TCMIY  2        # 18:2d (18:24) 64  -  
    RETN            # 18:2e (18:08) 0f  -  
    BR     34       # 18:2f (18:11) a6  -  
    LDX    4        # 18:30 (18:22) 29  -  
    TCY    d        # 18:31 (18:04) 4b  -  
    TCMIY  0        # 18:32 (18:09) 60  -  
    RETN            # 18:33 (18:13) 0f  -  
    LDP    e        # 18:34 (18:26) 17  -  
    BR     32       # 18:35 (18:0c) 89  -  
    LDX    0        # 18:36 (18:19) 28  -  
    TCY    d        # 18:37 (18:32) 4b  -  
    LDP    0        # 18:38 (18:25) 10  -  
    TPC            # 18:39 (18:0a) 0b  -  
    LDP    9        # 18:3a (18:15) 19  -  
    BR     3b       # 18:3b (18:2a) aa  -  
    LDP    4        # 18:3c (18:14) 12  -  
    CALL   3a       # 18:3d (18:28) d5  -  
    TDO             # 18:3e (18:10) 0a  -  
    RETN            # 18:3f (18:20) 0f  -  

# -----------------------------------------------------------------------------
# Page 19

    LDP    6        # 19:00 (19:00) 16  -  
    CALL   1b       # 19:01 (19:01) c2  -  
    TCY    d        # 19:02 (19:03) 4b  -  
    TBIT   0        # 19:03 (19:07) 38  -  
    BR     09       # 19:04 (19:0f) bb  -  
    CLA             # 19:05 (19:1f) 7f  -  
    TCY    f        # 19:06 (19:3f) 4f  -  
    LDP    6        # 19:07 (19:3e) 16  -  
    BR     28       # 19:08 (19:3d) ad  -  
    CLA             # 19:09 (19:3b) 7f  -  
    ACxAC  0        # 19:0a (19:37) 70  -  
    TCY    f        # 19:0b (19:2f) 4f  -  
    BR     07       # 19:0c (19:1e) be  -  
    LDP    a        # 19:0d (19:3c) 15  -  
    CALL   00       # 19:0e (19:39) c0  -  
    LDX    4        # 19:0f (19:33) 29  -  
    TAM             # 19:10 (19:27) 27  -  
    TCY    d        # 19:11 (19:0e) 4b  -  
    TBIT   0        # 19:12 (19:1d) 38  -  
    BR     18       # 19:13 (19:3a) 98  -  
    CLA             # 19:14 (19:35) 7f  -  
    TCY    f        # 19:15 (19:2b) 4f  -  
    LDP    7        # 19:16 (19:16) 1e  -  
    BR     0c       # 19:17 (19:2c) 9e  -  
    CLA             # 19:18 (19:18) 7f  -  
    ACxAC  0        # 19:19 (19:30) 70  -  
    TCY    f        # 19:1a (19:21) 4f  -  
    BR     16       # 19:1b (19:02) 96  -  
    LDX    5        # 19:1c (19:05) 2d  -  
    TCY    e        # 19:1d (19:0b) 47  -  
    TMY             # 19:1e (19:17) 22  -  
    LDX    7        # 19:1f (19:2e) 2f  -  
    RETN            # 19:20 (19:1c) 0f  -  
    TMA             # 19:21 (19:38) 21  -  
    LDX    5        # 19:22 (19:31) 2d  -  
    TCY    f        # 19:23 (19:23) 4f  -  
    TMY             # 19:24 (19:06) 22  -  
    LDX    7        # 19:25 (19:0d) 2f  -  
    XMA             # 19:26 (19:1b) 03  -  
    CALL   1c       # 19:27 (19:36) c5  -  
    TAM             # 19:28 (19:2d) 27  -  
    LDX    5        # 19:29 (19:1a) 2d  -  
    TCY    f        # 19:2a (19:34) 4f  -  
    DMAN            # 19:2b (19:29) 07  -  
    TAM             # 19:2c (19:12) 27  -  
    TCY    e        # 19:2d (19:24) 47  -  
    DMAN            # 19:2e (19:08) 07  -  
    BR     32       # 19:2f (19:11) 89  -  
    LDP    8        # 19:30 (19:22) 11  -  
    BR     38       # 19:31 (19:04) a5  -  
    TAM             # 19:32 (19:09) 27  -  
    BR     1c       # 19:33 (19:13) 85  -  
    MNEA            # 19:34 (19:26) 00  -  
    MNEA            # 19:35 (19:0c) 00  -  
    MNEA            # 19:36 (19:19) 00  -  
    MNEA            # 19:37 (19:32) 00  -  
    MNEA            # 19:38 (19:25) 00  -  
    MNEA            # 19:39 (19:0a) 00  -  
    MNEA            # 19:3a (19:15) 00  -  
    MNEA            # 19:3b (19:2a) 00  -  
    MNEA            # 19:3c (19:14) 00  -  
    MNEA            # 19:3d (19:28) 00  -  
    MNEA            # 19:3e (19:10) 00  -  
    MNEA            # 19:3f (19:20) 00  -  

# -----------------------------------------------------------------------------
# Page 1a

    LDX    1        # 1a:00 (1a:00) 2c  -  
    TCY    0        # 1a:01 (1a:01) 40  -  
    TMY             # 1a:02 (1a:03) 22  -  
    LDX    7        # 1a:03 (1a:07) 2f  -  
    TMA             # 1a:04 (1a:0f) 21  -  
    LDX    1        # 1a:05 (1a:1f) 2c  -  
    TCY    f        # 1a:06 (1a:3f) 4f  -  
    TAM             # 1a:07 (1a:3e) 27  -  
    RETN            # 1a:08 (1a:3d) 0f  -  
    TBIT   0        # 1a:09 (1a:3b) 38  -  
    BR     25       # 1a:0a (1a:37) 8d  -  
    LDP    b        # 1a:0b (1a:2f) 1d  -  
    BR     07       # 1a:0c (1a:1e) be  -  
    TCY    f        # 1a:0d (1a:3c) 4f  -  
    TBIT   1        # 1a:0e (1a:39) 3a  -  
    BR     1f       # 1a:0f (1a:33) ae  -  
    RBIT   0        # 1a:10 (1a:27) 34  -  
    TBIT   2        # 1a:11 (1a:0e) 39  -  
    BR     21       # 1a:12 (1a:1d) b8  -  
    RBIT   1        # 1a:13 (1a:3a) 36  -  
    TBIT   3        # 1a:14 (1a:35) 3b  -  
    BR     23       # 1a:15 (1a:2b) a3  -  
    RBIT   2        # 1a:16 (1a:16) 35  -  
    RBIT   3        # 1a:17 (1a:2c) 37  -  
    TMA             # 1a:18 (1a:18) 21  -  
    TCY    0        # 1a:19 (1a:30) 40  -  
    TMY             # 1a:1a (1a:21) 22  -  
    LDX    7        # 1a:1b (1a:02) 2f  -  
    TAM             # 1a:1c (1a:05) 27  -  
    LDP    b        # 1a:1d (1a:0b) 1d  -  
    BR     12       # 1a:1e (1a:17) 9d  -  
    SBIT   0        # 1a:1f (1a:2e) 30  -  
    BR     11       # 1a:20 (1a:1c) 8e  -  
    SBIT   1        # 1a:21 (1a:38) 32  -  
    BR     14       # 1a:22 (1a:31) b5  -  
    SBIT   2        # 1a:23 (1a:23) 31  -  
    BR     17       # 1a:24 (1a:06) ac  -  
    LDP    b        # 1a:25 (1a:0d) 1d  -  
    BR     00       # 1a:26 (1a:1b) 80  -  
    LDP    b        # 1a:27 (1a:36) 1d  -  
    BR     10       # 1a:28 (1a:2d) a7  -  
    CALL   00       # 1a:29 (1a:1a) c0  -  
    TBIT   3        # 1a:2a (1a:34) 3b  -  
    BR     27       # 1a:2b (1a:29) b6  -  
    LDP    b        # 1a:2c (1a:12) 1d  -  
    BR     0d       # 1a:2d (1a:24) bc  -  
    TCY    f        # 1a:2e (1a:08) 4f  -  
    TBIT   2        # 1a:2f (1a:11) 39  -  
    BR     3a       # 1a:30 (1a:22) 95  -  
    RBIT   3        # 1a:31 (1a:04) 37  -  
    TBIT   1        # 1a:32 (1a:09) 3a  -  
    BR     3c       # 1a:33 (1a:13) 94  -  
    RBIT   2        # 1a:34 (1a:26) 35  -  
    TBIT   0        # 1a:35 (1a:0c) 38  -  
    BR     3e       # 1a:36 (1a:19) 90  -  
    RBIT   1        # 1a:37 (1a:32) 36  -  
    RBIT   0        # 1a:38 (1a:25) 34  -  
    BR     18       # 1a:39 (1a:0a) 98  -  
    SBIT   3        # 1a:3a (1a:15) 33  -  
    BR     32       # 1a:3b (1a:2a) 89  -  
    SBIT   2        # 1a:3c (1a:14) 31  -  
    BR     35       # 1a:3d (1a:28) 8c  -  
    SBIT   1        # 1a:3e (1a:10) 32  -  
    BR     38       # 1a:3f (1a:20) a5  -  

# -----------------------------------------------------------------------------
# Page 1b

    LDX    4        # 1b:00 (1b:00) 29  -  
    TCY    d        # 1b:01 (1b:01) 4b  -  
    SBIT   0        # 1b:02 (1b:03) 30  -  
    LDX    1        # 1b:03 (1b:07) 2c  -  
    RETN            # 1b:04 (1b:0f) 0f  -  
    LDP    a        # 1b:05 (1b:1f) 15  -  
    BR     0d       # 1b:06 (1b:3f) bc  -  
    LDX    4        # 1b:07 (1b:3e) 29  -  
    TCY    d        # 1b:08 (1b:3d) 4b  -  
    RBIT   0        # 1b:09 (1b:3b) 34  -  
    LDX    1        # 1b:0a (1b:37) 2c  -  
    RETN            # 1b:0b (1b:2f) 0f  -  
    BR     05       # 1b:0c (1b:1e) 9f  -  
    CALL   07       # 1b:0d (1b:3c) fe  -  
    LDP    a        # 1b:0e (1b:39) 15  -  
    BR     2e       # 1b:0f (1b:33) 88  -  
    CALL   00       # 1b:10 (1b:27) c0  -  
    BR     0e       # 1b:11 (1b:0e) b9  -  
    LDX    1        # 1b:12 (1b:1d) 2c  -  
    TCY    f        # 1b:13 (1b:3a) 4f  -  
    MNEZ            # 1b:14 (1b:35) 3f  -  
    BR     1b       # 1b:15 (1b:2b) 82  -  
    LDX    4        # 1b:16 (1b:16) 29  -  
    TCY    d        # 1b:17 (1b:2c) 4b  -  
    SBIT   1        # 1b:18 (1b:18) 32  -  
    LDP    e        # 1b:19 (1b:30) 17  -  
    BR     32       # 1b:1a (1b:21) 89  -  
    LDX    4        # 1b:1b (1b:02) 29  -  
    TCY    d        # 1b:1c (1b:05) 4b  -  
    RBIT   1        # 1b:1d (1b:0b) 36  -  
    BR     19       # 1b:1e (1b:17) b0  -  
    LDX    4        # 1b:1f (1b:2e) 29  -  
    TCY    d        # 1b:20 (1b:1c) 4b  -  
    RBIT   0        # 1b:21 (1b:38) 34  -  
    LDP    a        # 1b:22 (1b:31) 15  -  
    CALL   00       # 1b:23 (1b:23) c0  -  
    LDP    0        # 1b:24 (1b:06) 10  -  
    TPC            # 1b:25 (1b:0d) 0b  -  
    LDP    9        # 1b:26 (1b:1b) 19  -  
    CALL   23       # 1b:27 (1b:36) e3  -  
    LDX    1        # 1b:28 (1b:2d) 2c  -  
    TCY    f        # 1b:29 (1b:1a) 4f  -  
    TAM             # 1b:2a (1b:34) 27  -  
    LDP    a        # 1b:2b (1b:29) 15  -  
    BR     18       # 1b:2c (1b:12) 98  -  
    LDX    0        # 1b:2d (1b:24) 28  -  
    TCY    8        # 1b:2e (1b:08) 41  -  
    TBIT   3        # 1b:2f (1b:11) 3b  -  
    BR     35       # 1b:30 (1b:22) 8c  -  
    LDP    0        # 1b:31 (1b:04) 10  -  
    TPC            # 1b:32 (1b:09) 0b  -  
    LDP    1        # 1b:33 (1b:13) 18  -  
    BR     02       # 1b:34 (1b:26) 83  -  
    RBIT   3        # 1b:35 (1b:0c) 37  -  
    LDP    0        # 1b:36 (1b:19) 10  -  
    TPC            # 1b:37 (1b:32) 0b  -  
    LDP    8        # 1b:38 (1b:25) 11  -  
    BR     02       # 1b:39 (1b:0a) 83  -  
    LDP    1        # 1b:3a (1b:15) 18  -  
    TPC            # 1b:3b (1b:2a) 0b  -  
    TKA             # 1b:3c (1b:14) 08  -  
    TDO             # 1b:3d (1b:28) 0a  -  
    BR     3c       # 1b:3e (1b:10) 94  -  
    MNEA            # 1b:3f (1b:20) 00  -  

# -----------------------------------------------------------------------------
# Page 1c

    LDP    6        # 1c:00 (1c:00) 16  -  
    CALL   1b       # 1c:01 (1c:01) c2  -  
    LDP    6        # 1c:02 (1c:03) 16  -  
    CALL   20       # 1c:03 (1c:07) dc  -  
    TCY    e        # 1c:04 (1c:0f) 47  -  
    TAM             # 1c:05 (1c:1f) 27  -  
    TCY    f        # 1c:06 (1c:3f) 4f  -  
    TBIT   0        # 1c:07 (1c:3e) 38  -  
    BR     10       # 1c:08 (1c:3d) a7  -  
    TBIT   1        # 1c:09 (1c:3b) 3a  -  
    BR     14       # 1c:0a (1c:37) b5  -  
    TBIT   2        # 1c:0b (1c:2f) 39  -  
    BR     18       # 1c:0c (1c:1e) 98  -  
    TBIT   3        # 1c:0d (1c:3c) 3b  -  
    BR     1c       # 1c:0e (1c:39) 85  -  
    BR     1f       # 1c:0f (1c:33) ae  -  
    TCY    e        # 1c:10 (1c:27) 47  -  
    SBIT   0        # 1c:11 (1c:0e) 30  -  
    TCY    f        # 1c:12 (1c:1d) 4f  -  
    BR     09       # 1c:13 (1c:3a) bb  -  
    TCY    e        # 1c:14 (1c:35) 47  -  
    SBIT   1        # 1c:15 (1c:2b) 32  -  
    TCY    f        # 1c:16 (1c:16) 4f  -  
    BR     0b       # 1c:17 (1c:2c) af  -  
    TCY    e        # 1c:18 (1c:18) 47  -  
    SBIT   2        # 1c:19 (1c:30) 31  -  
    TCY    f        # 1c:1a (1c:21) 4f  -  
    BR     0d       # 1c:1b (1c:02) bc  -  
    TCY    e        # 1c:1c (1c:05) 47  -  
    SBIT   3        # 1c:1d (1c:0b) 33  -  
    TCY    f        # 1c:1e (1c:17) 4f  -  
    LDP    5        # 1c:1f (1c:2e) 1a  -  
    BR     2f       # 1c:20 (1c:1c) 91  -  
    LDX    0        # 1c:21 (1c:38) 28  -  
    TCY    8        # 1c:22 (1c:31) 41  -  
    TBIT   3        # 1c:23 (1c:23) 3b  -  
    BR     27       # 1c:24 (1c:06) b6  -  
    LDP    e        # 1c:25 (1c:0d) 17  -  
    BR     1a       # 1c:26 (1c:1b) a1  -  
    RBIT   3        # 1c:27 (1c:36) 37  -  
    LDP    0        # 1c:28 (1c:2d) 10  -  
    TPC            # 1c:29 (1c:1a) 0b  -  
    LDP    8        # 1c:2a (1c:34) 11  -  
    BR     02       # 1c:2b (1c:29) 83  -  
    MNEA            # 1c:2c (1c:12) 00  -  
    MNEA            # 1c:2d (1c:24) 00  -  
    MNEA            # 1c:2e (1c:08) 00  -  
    MNEA            # 1c:2f (1c:11) 00  -  
    MNEA            # 1c:30 (1c:22) 00  -  
    MNEA            # 1c:31 (1c:04) 00  -  
    MNEA            # 1c:32 (1c:09) 00  -  
    MNEA            # 1c:33 (1c:13) 00  -  
    MNEA            # 1c:34 (1c:26) 00  -  
    MNEA            # 1c:35 (1c:0c) 00  -  
    MNEA            # 1c:36 (1c:19) 00  -  
    MNEA            # 1c:37 (1c:32) 00  -  
    MNEA            # 1c:38 (1c:25) 00  -  
    MNEA            # 1c:39 (1c:0a) 00  -  
    MNEA            # 1c:3a (1c:15) 00  -  
    MNEA            # 1c:3b (1c:2a) 00  -  
    MNEA            # 1c:3c (1c:14) 00  -  
    MNEA            # 1c:3d (1c:28) 00  -  
    MNEA            # 1c:3e (1c:10) 00  -  
    MNEA            # 1c:3f (1c:20) 00  -  

# -----------------------------------------------------------------------------
# Page 1d

    LDP    f        # 1d:00 (1d:00) 1f  -  
    CALL   00       # 1d:01 (1d:01) c0  -  
    TCY    d        # 1d:02 (1d:03) 4b  -  
    MNEZ            # 1d:03 (1d:07) 3f  -  
    BR     08       # 1d:04 (1d:0f) bd  -  
    IYC             # 1d:05 (1d:1f) 05  -  
    BR     1a       # 1d:06 (1d:3f) a1  -  
    BR     03       # 1d:07 (1d:3e) 87  -  
    TCY    d        # 1d:08 (1d:3d) 4b  -  
    DMAN            # 1d:09 (1d:3b) 07  -  
    BR     0e       # 1d:0a (1d:37) b9  -  
    TAMIYC          # 1d:0b (1d:2f) 25  -  
    BR     1a       # 1d:0c (1d:1e) a1  -  
    BR     09       # 1d:0d (1d:3c) bb  -  
    TAM             # 1d:0e (1d:39) 27  -  
    TCY    0        # 1d:0f (1d:33) 40  -  
    IMAC            # 1d:10 (1d:27) 3e  -  
    TAM             # 1d:11 (1d:0e) 27  -  
    ACxAC  5        # 1d:12 (1d:1d) 7a  -  
    BR     15       # 1d:13 (1d:3a) ab  -  
    BR     08       # 1d:14 (1d:35) bd  -  
    CLA             # 1d:15 (1d:2b) 7f  -  
    TAMIYC          # 1d:16 (1d:16) 25  -  
    YNEC   3        # 1d:17 (1d:2c) 5c  -  
    BR     10       # 1d:18 (1d:18) a7  -  
    BR     1c       # 1d:19 (1d:30) 85  -  
    LDP    f        # 1d:1a (1d:21) 1f  -  
    BR     24       # 1d:1b (1d:02) 86  -  
    LDX    4        # 1d:1c (1d:05) 29  -  
    TCY    d        # 1d:1d (1d:0b) 4b  -  
    TCMIY  2        # 1d:1e (1d:17) 64  -  
    CLA             # 1d:1f (1d:2e) 7f  -  
    LDX    7        # 1d:20 (1d:1c) 2f  -  
    TCY    d        # 1d:21 (1d:38) 4b  -  
    TAMIYC          # 1d:22 (1d:31) 25  -  
    BR     25       # 1d:23 (1d:23) 8d  -  
    BR     22       # 1d:24 (1d:06) b1  -  
    LDP    e        # 1d:25 (1d:0d) 17  -  
    BR     32       # 1d:26 (1d:1b) 89  -  
    TCY    0        # 1d:27 (1d:36) 40  -  
    TMA             # 1d:28 (1d:2d) 21  -  
    ACxAC  0        # 1d:29 (1d:1a) 70  -  
    BR     2f       # 1d:2a (1d:34) 91  -  
    LDP    2        # 1d:2b (1d:29) 14  -  
    TPC            # 1d:2c (1d:12) 0b  -  
    LDP    9        # 1d:2d (1d:24) 19  -  
    BR     04       # 1d:2e (1d:08) 8f  -  
    LDX    5        # 1d:2f (1d:11) 2d  -  
    TCY    e        # 1d:30 (1d:22) 47  -  
    TCMIY  7        # 1d:31 (1d:04) 6e  -  
    TCMIY  f        # 1d:32 (1d:09) 6f  -  
    LDP    9        # 1d:33 (1d:13) 19  -  
    BR     1c       # 1d:34 (1d:26) 85  -  
    MNEA            # 1d:35 (1d:0c) 00  -  
    MNEA            # 1d:36 (1d:19) 00  -  
    MNEA            # 1d:37 (1d:32) 00  -  
    MNEA            # 1d:38 (1d:25) 00  -  
    MNEA            # 1d:39 (1d:0a) 00  -  
    MNEA            # 1d:3a (1d:15) 00  -  
    MNEA            # 1d:3b (1d:2a) 00  -  
    MNEA            # 1d:3c (1d:14) 00  -  
    MNEA            # 1d:3d (1d:28) 00  -  
    MNEA            # 1d:3e (1d:10) 00  -  
    MNEA            # 1d:3f (1d:20) 00  -  

# -----------------------------------------------------------------------------
# Page 1e

    TMA             # 1e:00 (1e:00) 21  -  
    ACxAC  a        # 1e:01 (1e:01) 75  -  
    BR     12       # 1e:02 (1e:03) 9d  -  
    TMA             # 1e:03 (1e:07) 21  -  
    ACxAC  b        # 1e:04 (1e:0f) 7d  -  
    BR     3a       # 1e:05 (1e:1f) 95  -  
    TMA             # 1e:06 (1e:3f) 21  -  
    ACxAC  c        # 1e:07 (1e:3e) 73  -  
    BR     3c       # 1e:08 (1e:3d) 94  -  
    TMA             # 1e:09 (1e:3b) 21  -  
    ACxAC  d        # 1e:0a (1e:37) 7b  -  
    BR     34       # 1e:0b (1e:2f) a6  -  
    TMA             # 1e:0c (1e:1e) 21  -  
    ACxAC  0        # 1e:0d (1e:3c) 70  -  
    ACxAC  d        # 1e:0e (1e:39) 7b  -  
    BR     32       # 1e:0f (1e:33) 89  -  
    LDP    c        # 1e:10 (1e:27) 13  -  
    BR     21       # 1e:11 (1e:0e) b8  -  
    TCY    d        # 1e:12 (1e:1d) 4b  -  
    LDX    5        # 1e:13 (1e:3a) 2d  -  
    TMA             # 1e:14 (1e:35) 21  -  
    LDX    7        # 1e:15 (1e:2b) 2f  -  
    TAM             # 1e:16 (1e:16) 27  -  
    IYC             # 1e:17 (1e:2c) 05  -  
    BR     32       # 1e:18 (1e:18) 89  -  
    BR     13       # 1e:19 (1e:30) ba  -  
    LDX    0        # 1e:1a (1e:21) 28  -  
    TCY    8        # 1e:1b (1e:02) 41  -  
    TCMIY  2        # 1e:1c (1e:05) 64  -  
    TCMIY  0        # 1e:1d (1e:0b) 60  -  
    TCMIY  0        # 1e:1e (1e:17) 60  -  
    TCY    d        # 1e:1f (1e:2e) 4b  -  
    TCMIY  0        # 1e:20 (1e:1c) 60  -  
    TCY    6        # 1e:21 (1e:38) 46  -  
    TCMIY  0        # 1e:22 (1e:31) 60  -  
    LDX    2        # 1e:23 (1e:23) 2a  -  
    TCY    3        # 1e:24 (1e:06) 4c  -  
    TCMIY  0        # 1e:25 (1e:0d) 60  -  
    LDX    4        # 1e:26 (1e:1b) 29  -  
    TCY    6        # 1e:27 (1e:36) 46  -  
    TCMIY  0        # 1e:28 (1e:2d) 60  -  
    LDX    3        # 1e:29 (1e:1a) 2e  -  
    TCY    6        # 1e:2a (1e:34) 46  -  
    TCMIY  1        # 1e:2b (1e:29) 68  -  
    TCMIY  1        # 1e:2c (1e:12) 68  -  
    TCY    e        # 1e:2d (1e:24) 47  -  
    TCMIY  5        # 1e:2e (1e:08) 6a  -  
    RETN            # 1e:2f (1e:11) 0f  -  
    LDP    2        # 1e:30 (1e:22) 14  -  
    CALL   35       # 1e:31 (1e:04) cc  -  
    LDP    8        # 1e:32 (1e:09) 11  -  
    BR     36       # 1e:33 (1e:13) 99  -  
    LDX    3        # 1e:34 (1e:26) 2e  -  
    TCY    6        # 1e:35 (1e:0c) 46  -  
    TCMIY  0        # 1e:36 (1e:19) 60  -  
    TCMIY  0        # 1e:37 (1e:32) 60  -  
    TCMIY  0        # 1e:38 (1e:25) 60  -  
    BR     32       # 1e:39 (1e:0a) 89  -  
    LDP    f        # 1e:3a (1e:15) 1f  -  
    BR     00       # 1e:3b (1e:2a) 80  -  
    LDP    d        # 1e:3c (1e:14) 1b  -  
    BR     00       # 1e:3d (1e:28) 80  -  
    MNEA            # 1e:3e (1e:10) 00  -  
    MNEA            # 1e:3f (1e:20) 00  -  

# -----------------------------------------------------------------------------
# Page 1f

    TCY    d        # 1f:00 (1f:00) 4b  -  
    LDX    7        # 1f:01 (1f:01) 2f  -  
    TMA             # 1f:02 (1f:03) 21  -  
    LDX    5        # 1f:03 (1f:07) 2d  -  
    TAM             # 1f:04 (1f:0f) 27  -  
    IYC             # 1f:05 (1f:1f) 05  -  
    BR     08       # 1f:06 (1f:3f) bd  -  
    BR     01       # 1f:07 (1f:3e) 81  -  
    TCY    c        # 1f:08 (1f:3d) 43  -  
    LDP    0        # 1f:09 (1f:3b) 10  -  
    TPC            # 1f:0a (1f:37) 0b  -  
    LDP    0        # 1f:0b (1f:2f) 10  -  
    CALL   07       # 1f:0c (1f:1e) fe  -  
    RETN            # 1f:0d (1f:3c) 0f  -  
    TCY    d        # 1f:0e (1f:39) 4b  -  
    MNEZ            # 1f:0f (1f:33) 3f  -  
    BR     14       # 1f:10 (1f:27) b5  -  
    IYC             # 1f:11 (1f:0e) 05  -  
    BR     24       # 1f:12 (1f:1d) 86  -  
    BR     0f       # 1f:13 (1f:3a) b3  -  
    TCY    d        # 1f:14 (1f:35) 4b  -  
    DMAN            # 1f:15 (1f:2b) 07  -  
    BR     1b       # 1f:16 (1f:16) 82  -  
    TCMIY  9        # 1f:17 (1f:2c) 69  -  
    YNEC   0        # 1f:18 (1f:18) 50  -  
    BR     15       # 1f:19 (1f:30) ab  -  
    BR     24       # 1f:1a (1f:21) 86  -  
    TAM             # 1f:1b (1f:02) 27  -  
    TCY    0        # 1f:1c (1f:05) 40  -  
    IMAC            # 1f:1d (1f:0b) 3e  -  
    BR     21       # 1f:1e (1f:17) b8  -  
    TAM             # 1f:1f (1f:2e) 27  -  
    BR     14       # 1f:20 (1f:1c) b5  -  
    TAMIYC          # 1f:21 (1f:38) 25  -  
    CLA             # 1f:22 (1f:31) 7f  -  
    BR     1d       # 1f:23 (1f:23) 8b  -  
    LDX    4        # 1f:24 (1f:06) 29  -  
    TCY    d        # 1f:25 (1f:0d) 4b  -  
    TCMIY  0        # 1f:26 (1f:1b) 60  -  
    TCY    0        # 1f:27 (1f:36) 40  -  
    LDX    5        # 1f:28 (1f:2d) 2d  -  
    TMA             # 1f:29 (1f:1a) 21  -  
    LDX    7        # 1f:2a (1f:34) 2f  -  
    RETN            # 1f:2b (1f:29) 0f  -  
    TCY    d        # 1f:2c (1f:12) 4b  -  
    TAM             # 1f:2d (1f:24) 27  -  
    TCY    1        # 1f:2e (1f:08) 48  -  
    CALL   28       # 1f:2f (1f:11) ed  -  
    TCY    e        # 1f:30 (1f:22) 47  -  
    TAM             # 1f:31 (1f:04) 27  -  
    TCY    2        # 1f:32 (1f:09) 44  -  
    CALL   28       # 1f:33 (1f:13) ed  -  
    TCY    f        # 1f:34 (1f:26) 4f  -  
    TAM             # 1f:35 (1f:0c) 27  -  
    RETN            # 1f:36 (1f:19) 0f  -  
    LDP    e        # 1f:37 (1f:32) 17  -  
    BR     32       # 1f:38 (1f:25) 89  -  
    MNEA            # 1f:39 (1f:0a) 00  -  
    MNEA            # 1f:3a (1f:15) 00  -  
    MNEA            # 1f:3b (1f:2a) 00  -  
    MNEA            # 1f:3c (1f:14) 00  -  
    MNEA            # 1f:3d (1f:28) 00  -  
    MNEA            # 1f:3e (1f:10) 00  -  
    MNEA            # 1f:3f (1f:20) 00  -  

# -----------------------------------------------------------------------------
# Page 20

    LDX    3        # 20:00 (20:00) 2e  -  
    TCY    6        # 20:01 (20:01) 46  -  
    SBIT   1        # 20:02 (20:03) 32  -  
    LDX    2        # 20:03 (20:07) 2a  -  
    TCY    3        # 20:04 (20:0f) 4c  -  
    TCMIY  0        # 20:05 (20:1f) 60  -  
    LDX    0        # 20:06 (20:3f) 28  -  
    TCY    d        # 20:07 (20:3e) 4b  -  
    TCMIY  5        # 20:08 (20:3d) 6a  -  
    TCY    0        # 20:09 (20:3b) 40  -  
    TMY             # 20:0a (20:37) 22  -  
    LDX    7        # 20:0b (20:2f) 2f  -  
    TMA             # 20:0c (20:1e) 21  -  
    LDX    3        # 20:0d (20:3c) 2e  -  
    TCY    0        # 20:0e (20:39) 40  -  
    TAM             # 20:0f (20:33) 27  -  
    LDX    0        # 20:10 (20:27) 28  -  
    TCY    0        # 20:11 (20:0e) 40  -  
    TMA             # 20:12 (20:1d) 21  -  
    LDX    3        # 20:13 (20:3a) 2e  -  
    TCY    3        # 20:14 (20:35) 4c  -  
    TAM             # 20:15 (20:2b) 27  -  
    CALL   1b       # 20:16 (20:16) c2  -  
    LDP    0        # 20:17 (20:2c) 10  -  
    TPC            # 20:18 (20:18) 0b  -  
    LDP    9        # 20:19 (20:30) 19  -  
    BR     3b       # 20:1a (20:21) aa  -  
    TCY    5        # 20:1b (20:02) 4a  -  
    RSTR            # 20:1c (20:05) 0c  -  
    DYN             # 20:1d (20:0b) 04  -  
    BR     1c       # 20:1e (20:17) 85  -  
    CLA             # 20:1f (20:2e) 7f  -  
    YNEA            # 20:20 (20:1c) 02  -  
    TCY    c        # 20:21 (20:38) 43  -  
    SETR            # 20:22 (20:31) 0d  -  
    TCY    3        # 20:23 (20:23) 4c  -  
    TMA             # 20:24 (20:06) 21  -  
    TDO             # 20:25 (20:0d) 0a  -  
    SETR            # 20:26 (20:1b) 0d  -  
    CLA             # 20:27 (20:36) 7f  -  
    ACxAC  5        # 20:28 (20:2d) 7a  -  
    ACxAC  0        # 20:29 (20:1a) 70  -  
    BR     2c       # 20:2a (20:34) 92  -  
    BR     29       # 20:2b (20:29) 9a  -  
    RSTR            # 20:2c (20:12) 0c  -  
    YNEC   0        # 20:2d (20:24) 50  -  
    BR     30       # 20:2e (20:08) a2  -  
    BR     32       # 20:2f (20:11) 89  -  
    TCY    0        # 20:30 (20:22) 40  -  
    BR     24       # 20:31 (20:04) 86  -  
    LDP    0        # 20:32 (20:09) 10  -  
    TPC            # 20:33 (20:13) 0b  -  
    LDP    d        # 20:34 (20:26) 1b  -  
    BR     1f       # 20:35 (20:0c) ae  -  
    TCY    f        # 20:36 (20:19) 4f  -  
    TMA             # 20:37 (20:32) 21  -  
    LDX    3        # 20:38 (20:25) 2e  -  
    TCY    0        # 20:39 (20:0a) 40  -  
    TAM             # 20:3a (20:15) 27  -  
    TCY    3        # 20:3b (20:2a) 4c  -  
    TMY             # 20:3c (20:14) 22  -  
    LDX    7        # 20:3d (20:28) 2f  -  
    TAM             # 20:3e (20:10) 27  -  
    BR     16       # 20:3f (20:20) 96  -  

# -----------------------------------------------------------------------------
# Page 21

    LDX    0        # 21:00 (21:00) 28  -  
    TCY    8        # 21:01 (21:01) 41  -  
    TBIT   1        # 21:02 (21:03) 3a  -  
    BR     09       # 21:03 (21:07) bb  -  
    RBIT   3        # 21:04 (21:0f) 37  -  
    LDP    0        # 21:05 (21:1f) 10  -  
    TPC            # 21:06 (21:3f) 0b  -  
    LDP    5        # 21:07 (21:3e) 1a  -  
    BR     02       # 21:08 (21:3d) 83  -  
    LDP    1        # 21:09 (21:3b) 18  -  
    TPC            # 21:0a (21:37) 0b  -  
    LDP    e        # 21:0b (21:2f) 17  -  
    CALL   29       # 21:0c (21:1e) da  -  
    LDP    1        # 21:0d (21:3c) 18  -  
    TPC            # 21:0e (21:39) 0b  -  
    LDP    7        # 21:0f (21:33) 1e  -  
    BR     29       # 21:10 (21:27) 9a  -  
    LDP    2        # 21:11 (21:0e) 14  -  
    BR     08       # 21:12 (21:1d) bd  -  
    LDP    3        # 21:13 (21:3a) 1c  -  
    TPC            # 21:14 (21:35) 0b  -  
    LDP    6        # 21:15 (21:2b) 16  -  
    BR     37       # 21:16 (21:16) b2  -  
    LDX    1        # 21:17 (21:2c) 2c  -  
    TCY    4        # 21:18 (21:18) 42  -  
    TCMIY  0        # 21:19 (21:30) 60  -  
    TCMIY  0        # 21:1a (21:21) 60  -  
    RETN            # 21:1b (21:02) 0f  -  
    LDP    0        # 21:1c (21:05) 10  -  
    TPC            # 21:1d (21:0b) 0b  -  
    LDP    9        # 21:1e (21:17) 19  -  
    CALL   02       # 21:1f (21:2e) c3  -  
    LDP    0        # 21:20 (21:1c) 10  -  
    TPC            # 21:21 (21:38) 0b  -  
    LDP    1        # 21:22 (21:31) 18  -  
    CALL   05       # 21:23 (21:23) df  -  
    LDX    7        # 21:24 (21:06) 2f  -  
    LDP    0        # 21:25 (21:0d) 10  -  
    TPC            # 21:26 (21:1b) 0b  -  
    LDP    0        # 21:27 (21:36) 10  -  
    CALL   06       # 21:28 (21:2d) ff  -  
    LDP    5        # 21:29 (21:1a) 1a  -  
    BR     00       # 21:2a (21:34) 80  -  
    LDX    6        # 21:2b (21:29) 2b  -  
    TCY    6        # 21:2c (21:12) 46  -  
    SETR            # 21:2d (21:24) 0d  -  
    TKA             # 21:2e (21:08) 08  -  
    RSTR            # 21:2f (21:11) 0c  -  
    TCY    f        # 21:30 (21:22) 4f  -  
    TAM             # 21:31 (21:04) 27  -  
    TBIT   1        # 21:32 (21:09) 3a  -  
    BR     3d       # 21:33 (21:13) a8  -  
    TCY    e        # 21:34 (21:26) 47  -  
    TBIT   0        # 21:35 (21:0c) 38  -  
    BR     2b       # 21:36 (21:19) a9  -  
    TCY    e        # 21:37 (21:32) 47  -  
    TCMIY  1        # 21:38 (21:25) 68  -  
    LDP    3        # 21:39 (21:0a) 1c  -  
    CALL   3b       # 21:3a (21:15) ea  -  
    LDP    6        # 21:3b (21:2a) 16  -  
    BR     1c       # 21:3c (21:14) 85  -  
    TCY    e        # 21:3d (21:28) 47  -  
    TCMIY  0        # 21:3e (21:10) 60  -  
    BR     2b       # 21:3f (21:20) a9  -  

# -----------------------------------------------------------------------------
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

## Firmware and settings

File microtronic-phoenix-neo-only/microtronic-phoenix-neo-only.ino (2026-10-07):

/*

  Microtronic Phoenix (NEO ONLY)

  Version 1.0 (c) Jason T. Jacques, Decle, Michael A. Wessel 
  04-12-2025 

  <jtjacques@gmail.com>
  <dweeb@decle.org.uk> 
  <miacwess@gmail.com>
 
  The Busch Microtronic 2090 is (C) Busch GmbH 
  https://www.busch-modell.de/information/Microtronic-Computer.aspx 

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
*/

#define VERSION "1.0" 
#define DATE "04-12-2025"  

#include <avr/pgmspace.h>

#include <Wire.h>
#include <NewTone.h>
#include "TM16XXFonts.h"

//
// Hardware Config (HAL) 
// 

#define CARRY PIN_PC1
#define ZERO  PIN_PC2

#define SDA PIN_PC1
#define SCL PIN_PC0

#define DIN_PIN_1 PIN_PC4
#define DIN_PIN_2 PIN_PC5
#define DIN_PIN_3 PIN_PC6
#define DIN_PIN_4 PIN_PC7 

#define DOT_PIN_1 PIN_PD2
#define DOT_PIN_2 PIN_PD3
#define DOT_PIN_3 PIN_PD4
#define DOT_PIN_4 PIN_PD5 

#define CLOCK_1HZ PIN_PD6

#define SPEAKER_PIN PIN_PD7

#define DISPLAY_A PIN_PA0
#define DISPLAY_B PIN_PA1
#define DISPLAY_C PIN_PA2
#define DISPLAY_D PIN_PA3
#define DISPLAY_E PIN_PA4
#define DISPLAY_F PIN_PA5
#define DISPLAY_G PIN_PA6
#define DISPLAY_DOT PIN_PA7

#define DISPLAY_CAT_R0 PIN_PB4
#define DISPLAY_CAT_R1 PIN_PB5
#define DISPLAY_CAT_R2 PIN_PB6
#define DISPLAY_CAT_R3 PIN_PB7
#define DISPLAY_CAT_R4 PIN_PD0
#define DISPLAY_CAT_R5 PIN_PD1

// 
// Keypad Matrix 7 x 4  
//

#define ROWS 4
#define COLS 7

#define NO_KEY 0xFF

byte key = NO_KEY;
byte key0 = NO_KEY;

volatile boolean start_scanning = false; 
volatile boolean scanning = false; 
volatile boolean scanned = false; 

#define HALT  0x10
#define NEXT  0x11
#define RUN   0x12
#define CCE   0x13
#define REG   0x14
#define STEP  0x15
#define BKP   0x16
#define PGM   0x17 
#define RESET 0x18
#define CPUP  0x19
#define CPUM  0x1A
#define KEYBT 0x1B

char keys[ROWS][COLS] = { 
  { 0x0, 0x1, 0x2, 0x3,  CCE, PGM,  RESET }, 
  { 0x4, 0x5, 0x6, 0x7,  RUN,  HALT, KEYBT },
  { 0x8, 0x9, 0xA, 0xB,  BKP,  STEP, CPUP },
  { 0xC, 0xD, 0xE, 0xF,  NEXT, REG, CPUM } 
}; 

// R0 ,  R1,  R2 , R3,  R4,  R5, R12, OUTPUTS 
// PB4, PB5, PB6, PB7, PD0, PD1, PC3

byte colPins[COLS] = {PIN_PB4, PIN_PB5, PIN_PB6, PIN_PB7, PIN_PD0, PIN_PD1, PIN_PC3 }; // 7 columns

// K1, K2, K4, K8 INPUTS
// PB0 PB1 PB2 PB3 
byte rowPins[ROWS] = {PIN_PB0, PIN_PB1, PIN_PB2, PIN_PB3}; // 4 rows

//
// Keypad Tones
// 

#define HEXKEYTONE 440 
#define KEYTONELENGTH 50
#define FUNKEYTONE 880
#define FUNTONELENGTH 50 

//
//                    0  1  2  3   4   5   6   7   8   9  10  11   12   13   14  15
//

int cpu_delays[16] = {0, 3, 6, 9, 12, 15, 18, 21, 30, 40, 50, 80, 120, 150, 200, 500 }; 

int cpu_speed = 15 - 6;  
int cpu_delay = 0; 

//
//
//

boolean keybeep = true;

// Tone sound;

//
// MOV: 15 Notes (0 = Tone Off!) 
// C2, C#2, D2, D#2, E2, F2, F#2, G2, G#2, A2, B#2, B2, C3, C#3, D3
//  1   2    3   4    5   6   7    8   9    A   B    C   D   E    F 
//

int note_frequencies_mov[ ] = { 65, 69, 73, 78, 82, 87, 93, 98, 104, 110, 117, 123, 131, 139, 147 };

// ADDI: 16 Notes 
// D#3, E3, F3, F#3, G3, G#3, A3, B#3, B3, C4, C#4, D4, D#4, E4, F4, F#4
//  0    1   2   3    4   5    6   7    8   9   A    B   C    D   E   F
//

int note_frequencies_addi[] = { 156, 165, 175, 185, 196, 208, 220, 233, 247, 262, 277, 294, 311, 330, 349, 370 }; 

// SUBI: 16 Notes 
// G4, G#4, A4, B#4, B4, C5, C#5, D5, D#5, E5, F5, F#5, G5,  G#5, A5,  B#5
//  0   1    2   3    4   5   6    7   8    9   A   B    C    D    E    F 
// 
 
int note_frequencies_subi[] = { 392, 415, 440, 466, 494, 523, 554, 587, 622, 659, 698, 740, 784, 831, 880, 932 }; 

//
//
//

#define EXT_EEPROM 0x50    //Address of 24LC256 eeprom chip

//
// PGM ROM Programs - Adjust as you like!
//

// PGM 7 - NIM GAME
const char PGM7[] PROGMEM = "F08 FE0 F41 FF2 FF1 FF4 045 046 516 FF4 854 D19 904 E19 B3F F03 0D1 0E2 911 E15 C1A 902 D1A 1F0 FE0 F00 F02 064 10C 714 B3F 11A 10B C24 46A FBB 8AD E27 C29 8BE E2F 51C E2C C22 914 E2F C1C F03 0D1 0E2 F41 902 D09 911 E38 C09 1E2 1E3 1F5 FE5 105 FE5 C3A 01D 02E F04 64D FCE F07 ";

// PGM 8 - towers of hanoi 
const char PGM8[] PROGMEM = "F08 F0E F1F FFF F02 1AE 1CD 1BC F0E 11F C0D F60 F00 F0E 91F D15 F3D FF0 F02 F0E CB0 F0E B70 B70 B70 B70 F0E 0BF 71F 0AE 09C 08D F0E B50 12F C0D B60 B90 B90 B90 B90 F0E F3D FF0 F02 F0E B70 B70 B70 B70 F0E 0BF 71F 08E 09D 0AC F0E B50 13F C0D B60 B90 B90 B90 B90 CB0 000 000 000 000 000 000 000 000 000 000 000 000 000 000 098 0A9 0BA 0CB 0DC 0ED 0FE F07 000 000 000 000 000 000 000 000 0EF 0DE 0CD 0BC 0AB 09A 089 F07 000 000 000 000 000 000 000 000 F0D F0E 010 021 032 043 054 065 076 087 098 0A9 0BA 0CB 0DC 0ED 0FE F0E F0D F07 000 000 000 000 000 000 000 000 000 000 000 000 F0D F0E 0EF 0DE 0CD 0BC 0AB 09A 089 078 067 056 045 034 023 012 001 F0E F0D F07 000 000 000 000 000 000 000 000 000 000 000 000 91F E0B 92F E24 93F E3C F00 ";

// PGM 9 - electronic die
const char PGM9[] PROGMEM = "F05 90D E00 96D D00 F1D FF0 C00 ";

// PGM A - three digit counter with carry
const char PGMA[] PROGMEM = "F30 510 FB1 FB2 FE1 FE1 C00 ";

// PGM B - scrolling LED light
const char PGMB[] PROGMEM = "110 F10 FE0 FA0 FB0 C02 ";

// PGM C - DIN digital input test
const char PGMC[] PROGMEM = "F10 FD0 FE0 C00 ";

// PGM D - Lunar Lander
const char PGMD[] PROGMEM = "F02 F08 FE0 142 1F3 114 125 136 187 178 1A1 02D 03E 04F F03 F5D FFB F02 1B1 10F 05D 06E F03 F5D FFB F02 1C1 07D 08E F03 F5D FFB 10D 10E F2D FFB 99B D29 0DE 0BD C22 F02 10F F04 6D7 FC8 D69 6E8 D69 75D FCE D5A 4D2 FB3 FB4 4E3 FB4 652 FC3 FC4 D7B 663 FC4 D7B 6D5 FC6 D80 6E6 D80 904 D0A 903 D0A 952 D0A 906 D0A 955 D0A 1E0 1E1 1E2 1E3 1E4 1E5 1F6 FE6 F60 FF0 C00 6DF 6F2 FC3 FC4 D7B 652 FC3 FC4 D7B 663 FC4 D7B 4F5 FB6 C45 1E0 1A1 1E2 1A3 1FF 1FE FEF 71E D73 C70 F40 FEF 10D FED 71E D58 F02 C73 1A0 1A1 1A2 1A3 C6D 1F0 1A1 1F2 1A3 C6D ";

// PGM E - Primes
const char PGME[] PROGMEM = "F08 FEF F50 FFE FE5 9BE D09 E0C C00 9CE D02 C16 FFF 9AF EDA D18 034 023 012 001 0F0 C0C F02 B77 F02 B90 F0D F08 168 F0D F0F B77 F0F 904 D2A 903 D33 902 D36 901 D3C C3F 92A D2D C41 909 D30 C41 958 D3F C41 90A D3F C41 929 D39 C41 918 D3F C41 909 D3F C41 1FF C01 F70 F71 F72 F73 F74 680 D49 C4C 760 711 D4F 691 D50 C53 691 761 712 D56 6A2 D57 C5D 6A2 762 713 D5B C5D 763 714 900 D65 010 021 032 043 104 C5D 904 D46 903 D46 82A D1D E6D C46 819 D1D E71 C46 808 D1D E75 C46 F0D C17 510 990 D7B C90 560 511 991 D80 C90 561 512 992 D85 C90 562 513 993 D8A C90 563 514 994 D8F C90 564 910 EA9 920 E9D 930 E9D 970 EA9 990 EA9 950 E9D C77 904 DA6 903 DA6 902 DA6 901 DA6 CCF 930 EA9 C77 F70 F71 F72 F73 F74 410 101 10F DD2 990 DD2 420 102 11F DD2 990 DD2 430 103 12F DD2 990 DD2 440 104 13F DD2 990 DD2 901 DAE 930 ED0 960 ED0 990 ED0 F0D F07 F0D C77 560 511 92F DC4 EBE 90F DB8 CB2 F08 C0C ";

// PGM F - 17+4 Black Jack
const char PGMF[] PROGMEM = "F08 FE0 14A 1DB 1DC 1AD 17E 11F F6A FFF F02 B6C C12 F40 B6C FFF F02 E2C 80D E15 C1E 9A0 E18 C1E 902 E1B C1E 1A2 1A3 C5A 0D0 402 D24 992 D24 C26 513 562 923 E29 C2C 912 E5A D60 917 D33 E30 C36 966 D33 C36 90F E53 C0D 84E E39 C42 9A4 E3C C42 903 E3F C42 1A6 1A7 C60 0E4 446 D48 996 D48 C4A 566 517 927 E4F 90F E53 C0D 916 E60 D5A C4C 837 E57 D60 C5A 826 E60 D60 1DC 10D 10E 16F F4C C64 1DD 1AE 1BF F3D 1FB FEB FFB 104 FE4 F62 FF0 C00 F05 4FE 9AD D71 C73 57D C6E 9AE D76 F07 57E C73 ";

//
//
//

#define PROGRAMS 9

const char *const PGMROM[PROGRAMS] PROGMEM = {
  PGM7, PGM8, PGM9, PGMA, PGMB, PGMC, PGMD, PGME, PGMF};

byte programs = PROGRAMS;

byte program = 0;

//
//
//

unsigned long lastDispTime = 0;
unsigned long lastDispTime2 = 0;

#define CURSOR_OFF 8
byte cursor = CURSOR_OFF;
boolean blink = true;

byte showingDisplayFromReg = 0;
byte showingDisplayDigits = 0;

byte currentReg = 0;
byte currentInputRegister = 0;

unsigned long lasttime = 0; 

boolean neo_clock = false;
boolean carry = false;
boolean zero = false;
boolean error = false;
boolean initialized = false; 
boolean statusdots = true; 

volatile byte outputs = 0;

//
// internal clock
//

byte timeSeconds1 = 0;
byte timeSeconds10 = 0;
byte timeMinutes1 = 0;
byte timeMinutes10 = 0;
byte timeHours1 = 0;
byte timeHours10 = 0;

//
// auxilary helper variables
//

unsigned long num = 0;
unsigned long num2 = 0;
unsigned long num3 = 0;

//
// RAM program memory
//

byte op[256];
byte arg1[256];
byte arg2[256];

boolean jump = false;
byte neo_pc = 0;
byte breakAt = 0; // != 0 -> breakpoint set

boolean singleStep = false;
boolean ignoreBreakpointOnce = false;
boolean isDISP = false;

//
// Stack
//

#define STACK_DEPTH 5

byte stack[STACK_DEPTH];
byte sp = 0;

//
// Registers
//

byte reg[16];
byte regEx[16];

//
// keypad key and function key input
//

byte last_key = NO_KEY;

boolean keypadPressed = false;

byte input = 0;
byte keypadKey = NO_KEY;
byte functionKey = NO_KEY;

 
//
// current mode / status of emulator
//

enum mode
  {
    STOPPED,
    RESETTING,

    ENTERING_ADDRESS_HIGH,
    ENTERING_ADDRESS_LOW,

    ENTERING_BREAKPOINT_HIGH,
    ENTERING_BREAKPOINT_LOW,

    ENTERING_OP,
    ENTERING_ARG1,
    ENTERING_ARG2,

    RUNNING,
    STEPING,

    ENTERING_REG,
    INSPECTING,

    ENTERING_VALUE,
    ENTERING_PROGRAM,

    ENTERING_TIME,
    SHOWING_TIME

  };

mode currentMode = STOPPED;

//
// OP codes
//

#define OP_MOV 0x0
#define OP_MOVI 0x1
#define OP_AND 0x2
#define OP_ANDI 0x3
#define OP_ADD 0x4
#define OP_ADDI 0x5
#define OP_SUB 0x6
#define OP_SUBI 0x7
#define OP_CMP 0x8
#define OP_CMPI 0x9
#define OP_OR 0xA

#define OP_CALL 0xB
#define OP_GOTO 0xC
#define OP_BRC 0xD
#define OP_BRZ 0xE

#define OP_MAS 0xF7
#define OP_INV 0xF8
#define OP_SHR 0xF9
#define OP_SHL 0xFA
#define OP_ADC 0xFB
#define OP_SUBC 0xFC

#define OP_DIN 0xFD
#define OP_DOT 0xFE
#define OP_KIN 0xFF

#define OP_HALT 0xF00
#define OP_NOP 0xF01
#define OP_DISOUT 0xF02
#define OP_HXDZ 0xF03
#define OP_DZHX 0xF04
#define OP_RND 0xF05
#define OP_TIME 0xF06
#define OP_RET 0xF07
#define OP_CLEAR 0xF08
#define OP_STC 0xF09
#define OP_RSC 0xF0A
#define OP_MULT 0xF0B
#define OP_DIV 0xF0C
#define OP_EXRL 0xF0D
#define OP_EXRM 0xF0E
#define OP_EXRA 0xF0F

#define OP_DISP 0xF

//
// External 24LC512 EEPROM 
//

void init_EEPROM(void)
{
  Wire.begin();
  Wire.setClock(400000); 
}

void end_EEPROM(void)
{
  Wire.end();

}
  
void writeEEPROM(unsigned int eeaddress, byte data ) 
{
  Wire.beginTransmission(EXT_EEPROM);
  Wire.write((int)(eeaddress >> 8));   // MSB
  Wire.write((int)(eeaddress & 0xFF)); // LSB
  Wire.write(data);
  Wire.endTransmission();
 
  delay(5);
}
 
byte readEEPROM(unsigned int eeaddress ) 
{
  byte rdata = 0xFF;
 
  Wire.beginTransmission(EXT_EEPROM);
  Wire.write((int)(eeaddress >> 8));   // MSB
  Wire.write((int)(eeaddress & 0xFF)); // LSB
  Wire.endTransmission();
 
  Wire.requestFrom(EXT_EEPROM,1);
 
  if (Wire.available()) rdata = Wire.read();
 
  return rdata;
}

//
// Display 
//

volatile byte disp_data[8]; 

volatile byte status_led;

#define sendChar(pos, data, dot) pos ? disp_data[pos-2] = data : status_led = data  

void initializeTimer()
{
  TCCR2A = 0;
  TCCR2B = (1 << CS22) | (1 << CS21) | (0 << CS20) ;  // /256 pre-scaler 
    
  // Enable Timer0 overflow interrupt
  TIMSK2 |= (1 << TOIE2);
    
  // Set initial timer value
  TCNT2 = 0; 
    
  // Enable global interrupts
  sei();
}

void disableTimer()
{
  TCCR2B = 0; 
  pinMode(DISPLAY_CAT_R0, INPUT); // Display Digit Cathodes, 4
  pinMode(DISPLAY_CAT_R1, INPUT); 
  pinMode(DISPLAY_CAT_R2, INPUT); 
  pinMode(DISPLAY_CAT_R3, INPUT); 
  pinMode(DISPLAY_CAT_R4, INPUT); 
  pinMode(DISPLAY_CAT_R5, INPUT); // Display Digit Cathodes, 9 
  pinMode(PIN_PC3, INPUT); // NOW SCAN THE KEYBOARD; R12 = PC3 is LOW 
}

void advance_clock() {

  neo_clock = !neo_clock;

  digitalWrite(CLOCK_1HZ, neo_clock); 
  

  if (neo_clock) {

    timeSeconds1++;

    if (timeSeconds1 > 9)
      {
	timeSeconds10++;
	timeSeconds1 = 0;

	if (timeSeconds10 > 5)
	  {
	    timeMinutes1++;
	    timeSeconds10 = 0;

	    if (timeMinutes1 > 9)
	      {
		timeMinutes10++;
		timeMinutes1 = 0;

		if (timeMinutes10 > 5)
		  {
		    timeHours1++;
		    timeMinutes10 = 0;

		    if (timeHours10 < 2)
		      {
			if (timeHours1 > 9)
			  {
			    timeHours1 = 0;
			    timeHours10++;
			  }
		      }
		    else if (timeHours10 == 2)
		      {
			if (timeHours1 > 3)
			  {
			    timeHours1 = 0;
			    timeHours10 = 0;
			  }
		      }
		  }
	      }
	  }
      }
  }
  
}

void initializeClock() {}; 

/*

// we'll need Timer1 for NewTone sound!
// so do the 1 Hz clock in software again...

void initializeClock()
{

// Timer1 interrupt at 1Hz

cli();

TCCR1A = 0;
TCCR1B = 0;
TCNT1 = 624;

// OCR1A =0xF9;
// OCR1A = 15624 / 2;
// OCR1A = 50;
OCR1A =  20000 / 2; 

// turn on CTC mode
TCCR1B |= (1 << WGM12);
// Set CS12 and CS10 bits for 1024 prescaler
TCCR1B |= (1 << CS12) | (1 << CS10);
// enable timer compare interrupt
TIMSK1 |= (1 << OCIE1A);

sei();
}

ISR(TIMER1_COMPA_vect)
{

advance_clock();

}

*/


byte scan_current_key(void) {
  if (scanned) {
    key0 = key;
    scanned = false; 
    return key;
  } if (scanning) {
    return key0;
  } else {
    start_scanning = true;
    return key0; 
  } 
}

byte get_current_key(void) {
  while ( scanning ) { __asm__("nop\n\t"); };
  start_scanning = true;
  while ( ! scanned) { __asm__("nop\n\t"); };
  return key;    
}

byte get_current_key1(void) {
  byte ikey0 = NO_KEY; 
  do {
    byte ikey = get_current_key();
    if (ikey == NO_KEY && ikey0 != NO_KEY) 
      return ikey0;
    ikey0 = ikey;
  } while (true); 
}


volatile uint8_t seg = 0; 

void show_digit() {

  // PD1, PD0, PB7, PB6, PB5, PB4 CATHODES OF LED DISPLAY 
  // R5, R4, R3, R2, R1, R0

  if (start_scanning && ! scanning && seg == 0 ) {
    scanned = false;
    start_scanning = false;
    scanning = true;
    key = NO_KEY; 
  }

  uint8_t row = 0;
  
  if (! digitalRead(PB0)) 
    row = 1;
  else if (! digitalRead(PB1))
    row = 2;
  else if (! digitalRead(PB2))
    row = 3;
  else if (! digitalRead(PB3))
    row = 4;

  if (scanning) {
    if (row) 
      key = keys[row-1][seg == 6 ? 6 : 5-seg ];
  }

  if (scanning && seg == 6) {
    scanned = true;
    scanning = false; 
  }

  if (seg == 6) 
    pinMode(PIN_PC3, INPUT);     
  else 
    pinMode(9-seg, INPUT);
    
  seg = (seg+1) % 7;

  if (initialized && statusdots) {
    switch (seg) {

    case 0 :
      if (currentMode == RUNNING)  
	disp_data[0] |= 0b10000000;
      else
	disp_data[0] &= 0b01111111;
      break;
    
    case 1 :
      if (currentMode == ENTERING_VALUE) 
	disp_data[1] |= 0b10000000;
      else
	disp_data[1] &= 0b01111111;
      break;
    
    case 2 : 
      if (breakAt)	
	disp_data[2] |= 0b10000000;
      else
	disp_data[2] &= 0b01111111;
      break;
    
    case 3 : 
      if (carry) 
	disp_data[3] |= 0b10000000;
      else
	disp_data[3] &= 0b01111111;
      break;
    
    case 4 : 
      if (zero) 
	disp_data[4] |= 0b10000000;
      else
	disp_data[4] &= 0b01111111;
      break;
    
    case 5 : 
      if (neo_clock) 
	disp_data[5] |= 0b10000000;
      else
	disp_data[5] &= 0b01111111;
      break;
    
    default :
      break;
    
    }  
  }
  
  if (seg == 6) {
    pinMode(PIN_PC3, OUTPUT); // NOW SCAN THE KEYBOARD; R12 = PC3 is LOW 
    digitalWrite(PIN_PC3, LOW);
  } else {
    uint8_t i = 9 - seg;
    portWrite(0, disp_data[seg]);

    pinMode(i, OUTPUT); // NOW SCAN THE KEYBOARD; K1, K2, K4, K8 are INPUTS = PB0 PB1 PB2 PB3
    digitalWrite(i, LOW);

  } 
  
}

ISR(TIMER2_OVF_vect) {
  show_digit(); 
}
  
#define DISP_DELAY 100

void sendString(String string)
{

  for (int i = 0; i < 6; i++)
    {
      sendChar(i+2, FONT_DEFAULT[string[i] - 32], false);
    }

  delay(DISP_DELAY);
}

void scrollString(String string)
{
  int n = string.length(); 
  for (int i = 0; i < n + 6; i++) { 
    for (int j = 0; j < 6; j++) {
      int index = i - (5 - j); 
      char c = index < 0 || index >= n ? ' ' : string[index]; 
      sendChar(j+2, FONT_DEFAULT[c - 32], false);
    }
    delay(80);
  }
}

void show_num(uint32_t n) {
  uint32_t y = 100000;
  uint8_t pos = 6; 
  do {
    uint8_t digit = n / y; 
    n %= y; 
    y /= 10; 
    sendChar(pos-1, NUMBER_FONT[digit], false);
    pos--; 
  } while ( pos ); 

}

//
// Setup Arduino
//

void neo_setup() {

  initialized = false; 

  randomSeed(analogRead(0));

  // Keyboard COLUMN OUTPUTS: 

  // R0 , R1, R2, R3, R4, R5, R12  OUTPUTS 
  // PB4, PB5, PB6, PB7, PD0, PD1, PC3

  // don't initialize, see Display initialization below 
  
  // pinMode(rowPins[0], OUTPUT); 
  // pinMode(rowPins[1], OUTPUT); 
  // pinMode(rowPins[2], OUTPUT); 
  // pinMode(rowPins[3], OUTPUT); 
  // pinMode(rowPins[4], OUTPUT); 
  // pinMode(rowPins[5], OUTPUT); 

  // R12 
  pinMode(colPins[6], OUTPUT);

  // Keyboard ROW INPUTS:

  // K1, K2, K4, K8 INPUTS
  // PB0 PB1 PB2 PB3 

  pinMode(rowPins[0], INPUT_PULLUP); // K1 
  pinMode(rowPins[1], INPUT_PULLUP); // K2 
  pinMode(rowPins[2], INPUT_PULLUP); // K3 
  pinMode(rowPins[3], INPUT_PULLUP); // K4 
  
  //
  // Display
  //


  pinMode(DISPLAY_CAT_R0, INPUT); // Display Digit Cathodes, 4
  pinMode(DISPLAY_CAT_R1, INPUT); 
  pinMode(DISPLAY_CAT_R2, INPUT); 
  pinMode(DISPLAY_CAT_R3, INPUT); 
  pinMode(DISPLAY_CAT_R4, INPUT); 
  pinMode(DISPLAY_CAT_R5, INPUT); // Display Digit Cathodes, 9 

  /*
    --- A ---
    |       |
    F       B
    --- G ---
    E       C
    |       |
    --- D --- .7 <- DOT not used 
  */ 

  pinMode(DISPLAY_A, OUTPUT); // Display Anode Segment A
  pinMode(DISPLAY_B, OUTPUT); // Display Anode Segment B
  pinMode(DISPLAY_C, OUTPUT); // Display Anode Segment C
  pinMode(DISPLAY_D, OUTPUT); // Display Anode Segment D
  pinMode(DISPLAY_E, OUTPUT); // Display Anode Segment E
  pinMode(DISPLAY_F, OUTPUT); // Display Anode Segment F
  pinMode(DISPLAY_G, OUTPUT); // Display Anode Segment G
  pinMode(DISPLAY_DOT, OUTPUT); // Display Anode Segment . 

  //
  //
  //
    
  pinMode(SDA  , OUTPUT); // R13 = SCL 
  pinMode(CARRY, OUTPUT); // R14 = SDA = CARRY 
  pinMode(ZERO , OUTPUT); // R15 = ZERO 

  // DIN 
  
  pinMode(DIN_PIN_1, INPUT);
  pinMode(DIN_PIN_2, INPUT);
  pinMode(DIN_PIN_3, INPUT);
  pinMode(DIN_PIN_4, INPUT);

  // DOT 
  
  pinMode(DOT_PIN_1, OUTPUT); 
  pinMode(DOT_PIN_2, OUTPUT);
  pinMode(DOT_PIN_3, OUTPUT);
  pinMode(DOT_PIN_4, OUTPUT);

  //
  
  pinMode(CLOCK_1HZ, OUTPUT); // CLOCK 1 HZ

  // SOUND
  
  pinMode(SPEAKER_PIN, OUTPUT);

  //
  // Timers 
  //

  initializeClock(); 
  initializeTimer();

  //
  // Sound - PD7 
  //
  
  NewTone(SPEAKER_PIN, 400, 100); 

  //
  //	
  //

  dot_output(0); 

  lasttime = millis();
  cpu_delay = cpu_delays[15-cpu_speed]; 

} 

//
//
//

void showMem()
{

  int adr = neo_pc;

  if (currentMode == ENTERING_BREAKPOINT_HIGH || currentMode == ENTERING_BREAKPOINT_LOW)
    adr = breakAt;

  sendChar(1, 0, false);

  if (cursor == 0)
    sendChar(2, blink ? NUMBER_FONT[adr / 16] : 0, false);
  else
    sendChar(2, NUMBER_FONT[adr / 16], false);

  if (cursor == 1)
    sendChar(3, blink ? NUMBER_FONT[adr % 16] : 0, false);
  else
    sendChar(3, NUMBER_FONT[adr % 16], false);

  sendChar(4, 0, false);

  if (cursor == 2)
    sendChar(5, blink ? NUMBER_FONT[op[adr]] : 0, false);
  else
    sendChar(5, NUMBER_FONT[op[adr]], false);

  if (cursor == 3)
    sendChar(6, blink ? NUMBER_FONT[arg1[adr]] : 0, false);
  else
    sendChar(6, NUMBER_FONT[arg1[adr]], false);

  if (cursor == 4)
    sendChar(7, blink ? NUMBER_FONT[arg2[adr]] : 0, false);
  else
    sendChar(7, NUMBER_FONT[arg2[adr]], false);
}

//
//
//

void showTime()
{

  sendChar(1, 0, false);

  if (cursor == 0)
    sendChar(2, blink ? NUMBER_FONT[timeHours10] : 0, false);
  else
    sendChar(2, NUMBER_FONT[timeHours10], false);

  if (cursor == 1)
    sendChar(3, blink ? NUMBER_FONT[timeHours1] : 0, false);
  else
    sendChar(3, NUMBER_FONT[timeHours1], false);

  if (cursor == 2)
    sendChar(4, blink ? NUMBER_FONT[timeMinutes10] : 0, false);
  else
    sendChar(4, NUMBER_FONT[timeMinutes10], false);

  if (cursor == 3)
    sendChar(5, blink ? NUMBER_FONT[timeMinutes1] : 0, false);
  else
    sendChar(5, NUMBER_FONT[timeMinutes1], false);

  if (cursor == 4)
    sendChar(6, blink ? NUMBER_FONT[timeSeconds10] : 0, false);
  else
    sendChar(6, NUMBER_FONT[timeSeconds10], false);

  if (cursor == 5)
    sendChar(7, blink ? NUMBER_FONT[timeSeconds1] : 0, false);
  else
    sendChar(7, NUMBER_FONT[timeSeconds1], false);
}

void showReg()
{

  sendChar(1, 0, false);
  sendChar(2, 0, false);

  if (cursor == 0)
    sendChar(3, blink ? NUMBER_FONT[currentReg] : 0, false);
  else
    sendChar(3, NUMBER_FONT[currentReg], false);

  sendChar(4, 0, false);
  sendChar(5, 0, false);
  sendChar(6, 0, false);

  if (cursor == 1)
    sendChar(7, blink ? NUMBER_FONT[reg[currentReg]] : 0, false);
  else
    sendChar(7, NUMBER_FONT[reg[currentReg]], false);
}

void showProgram()
{

  displayOff();
  sendChar(7, blink ? NUMBER_FONT[program] : 0, false);
}

void showError()
{

  displayOff();
  if (blink)
    sendString("error ");
}

void showReset()
{

  initialized = false; 
  noNewTone(SPEAKER_PIN);// Turn off the tone.
  displayOff();
  sendString("reset ");

}

void displayOff()
{

  showingDisplayFromReg = 0;
  showingDisplayDigits = 0;

  for (int i = 0; i < 6; i++)
    sendChar(i+2, 0, false);
}

void showDisplay()
{

  for (int i = 0; i < showingDisplayDigits; i++)
    sendChar(7 - i, NUMBER_FONT[reg[(i + showingDisplayFromReg) % 16]], false);
}
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
void loop() {
  neo_loop();
}

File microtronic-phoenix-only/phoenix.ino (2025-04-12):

/*
 * TMS1000 Family Emulator for AVR
 * Copyright (C) 2024-2025 Jason T. Jacques
 * <jtjacques@gmail.com>
 */

#include <avr/io.h>
#include <avr/pgmspace.h>


// custom config first
/*
 * TMS1000 Family Emulator for ATMega
 * Copyright (C) 2024-2025 Jason T. Jacques
 * <jtjacques@gmail.com>
 *
 * tms1600 config
 *
 *                    ____  ____
 *             K1  1 |*   \/    | 40 O0
 *             K2  2 |          | 39 O1
 *             K4  3 |          | 38 O2
 *             K8  4 |          | 37 O3
 *             R0  5 |          | 36 O4
 *             R1  6 |          | 35 O5
 *             R2  7 |          | 34 O6
 *             R3  8 |          | 33 O7
 *   [/RESET]  --  9 |          | 32 --  [AREF]
 *            VCC 10 |  ATMEGA  | 31 GND
 *            GND 11 |  644/32  | 30 VCC
 *          XTAL2 12 |          | 29 IN4
 *          XTAL1 13 |          | 28 IN3
 *             R4 14 |          | 27 IN2
 *             R5 15 |          | 26 IN1
 *             R7 16 |          | 25 R12 [XBTN]
 *             R8 17 |          | 24 R15
 *             R9 18 |          | 23 R14 [SDA]
 *            R10 19 |          | 22 R13 [SCL]
 *      [1HZ]  R6 20 |__________| 21 R11 [SPK]
 */


#define TARGET TMS1600

#define SOFT_RESET

#include <avr/cpufunc.h>

#define TMS1000 1000
#define TMS1100 1100
#define TMS1600 1600

#define SINGLE 0
#define SHFT_O 1
#define SHFT_OR 3

// default config
#ifndef TARGET
#define TARGET TMS1100
#endif

volatile uint8_t cycl = 0;
volatile uint8_t rset = 0;
#define reset() (rset = 1)

uint8_t pc, sr, pa, pb, cl, x, y, s, sl, a, ca, cb, cs;

#if TARGET == TMS1600
uint8_t sr1, sr2, sr3, psr1, psr2, psr3, cl1, cl2, cl3, csr1, csr2, csr3;
#endif

// n.b. also used in reset
static void reg_init() {
  pc = 0, sr = 0, pa = 0xf, pb = 0xf, cl = 0, x = 0, y = 0, s = 0, sl = 0,
  a = 0, ca = 0, cb = 0, cs = 0;

#if TARGET == TMS1600
  sr1 = 0, sr2 = 0, sr3 = 0, psr1 = 0, psr2 = 0, psr3 = 0, cl1 = 0, cl2 = 0,
  cl3 = 0, csr1 = 0, csr2 = 0, csr3 = 0;
#endif
}

#if TARGET == TMS1100 || TARGET == TMS1600
#define RAM_SIZE 128
#elif TARGET == TMS1000
#define RAM_SIZE 64
#endif
uint8_t RAM[RAM_SIZE];

#include <avr/interrupt.h>
#include <avr/io.h>
#include <avr/pgmspace.h>

// configuration handlers
// n.b. dummy params to diff direct pins/funcs and indirect
#define COMMA ,
#define PIN(P, N) X COMMA Y COMMA Z COMMA P COMMA N
#define FUNC(P) X COMMA Y COMMA P
#define DIR(X, Y, Z, P, N, D) set_exp(DDR##P, DD##P##N, D)
#define OUT(X) DIR(X, 1)
#define IN(X) DIR(X, 0)

// io utilities
#define on(n, b) ((n) | (1 << (b)))
#define off(n, b) ((n) & ~(1 << (b)))
#define bit(n, b, v) ((v) ? on(n, b) : off(n, b))
#define set_bit(n, b, v) set_exp(n, b, v)
#define get_bit(n, b) (!!(n & 1 << b))
#define set_exp(port, bit, value) \
  (port = (value) ? on(port, bit) : off(port, bit))
#define set_ee(X, Y, Z, P, N, V) (set_exp(PORT##P, PIN##P##N, V))
#define set_ef(X, Y, F, V) (set_##F(V))
#define set_efs(X, Y, F, D, V) (set_##F(D, V))
#define set_x(_1, _2, _3, _4, _5, _6, NAME, ...) NAME
#define set(...) \
  set_x(__VA_ARGS__, set_ee, set_efs, set_ef, set_exp, NULL)(__VA_ARGS__)
#define get_exp(port, bit) ((port & (1 << bit)) > 0)
#define get_ee(X, Y, Z, P, N) (get_exp(PIN##P, PIN##P##N))
#define get_ef(X, Y, F) (get_##F())
#define get_ex(_1, _2, _3, _4, _5, NAME, ...) NAME
#define get(...) \
  get_ex(__VA_ARGS__, get_ee, NULL, get_ef, get_exp, NULL)(__VA_ARGS__)
#define pulse(P) (set(P, 1), set(P, 0))
#define oo(n) (o(0x10 | (n & 0xf)))
#define ro(n) (r(n & 0xf0))
#define out(n) (oo(n), ro(n))

// misc utility
#define mirror(n)                                        \
  (((n & 1 << 7) >> 7 << 0) | ((n & 1 << 6) >> 6 << 1) | \
   ((n & 1 << 5) >> 5 << 2) | ((n & 1 << 4) >> 4 << 3) | \
   ((n & 1 << 3) >> 3 << 4) | ((n & 1 << 2) >> 2 << 5) | \
   ((n & 1 << 1) >> 1 << 6) | ((n & 1 << 0) >> 0 << 7))
#define swap(x, y) ((x ^= y), (y ^= x), (x ^= y))
#define toggle(number, bit) (number ^= (1 << bit))

// program counter
#define ps 6
#define pm ((1 << ps) - 1)
#define next(pc)                                                  \
  (((pc << 1)                /* left shift; or feedback */        \
    | (pc == (pm >> 1) ? 1 : /* if msb 0, others high: 1 */       \
           pc == pm ? 0      /* else if all high: 0 */            \
                    :        /* else xor msb and msb-1 */         \
           !(pc & (1 << (ps - 1))) == !(pc & (1 << (ps - 2))))) & \
   pm) /* mask overflow */

// use pc lookup table
#ifndef DYNAMIC
const uint8_t nextpc[] = {
    next(0x00), next(0x01), next(0x02), next(0x03), next(0x04), next(0x05),
    next(0x06), next(0x07), next(0x08), next(0x09), next(0x0a), next(0x0b),
    next(0x0c), next(0x0d), next(0x0e), next(0x0f), next(0x10), next(0x11),
    next(0x12), next(0x13), next(0x14), next(0x15), next(0x16), next(0x17),
    next(0x18), next(0x19), next(0x1a), next(0x1b), next(0x1c), next(0x1d),
    next(0x1e), next(0x1f), next(0x20), next(0x21), next(0x22), next(0x23),
    next(0x24), next(0x25), next(0x26), next(0x27), next(0x28), next(0x29),
    next(0x2a), next(0x2b), next(0x2c), next(0x2d), next(0x2e), next(0x2f),
    next(0x30), next(0x31), next(0x32), next(0x33), next(0x34), next(0x35),
    next(0x36), next(0x37), next(0x38), next(0x39), next(0x3a), next(0x3b),
    next(0x3c), next(0x3d), next(0x3e), next(0x3f)};
#undef next
#define next(pc) (nextpc[pc])
#endif

// instruction decoding
#define addr(ca, pa, pc) ((ca << (ps + 4)) | (pa << ps) | pc)
#define fetch(ca, pa, pc) (pgm_read_byte(&ROM[addr(ca, pa, pc)]))
#define i(inst) (inst & 0b11000000)
#define w(inst) (inst & 0b00111111)
#define ii(inst) (inst & 0b11110000)
#define c(inst)                                                               \
  (((inst & 0b0001) << 3) | ((inst & 0b0010) << 1) | ((inst & 0b0100) >> 1) | \
   ((inst & 0b1000) >> 3))
#define iii(inst) (inst & 0b11111100)
#define b(inst) (((inst & 0b01) << 1) | ((inst & 0b10) >> 1))
#define iv(inst) (inst) /* (inst & 0b11111111) */
#define v(inst) (inst & 0b11111000)
#define f(inst) \
  (((inst & 0b001) << 2) | ((inst & 0b010)) | ((inst & 0b100) >> 2))

// use operand lookup tables
#ifndef DYNAMIC
const uint8_t ct[] = {c(0x0), c(0x1), c(0x2), c(0x3), c(0x4), c(0x5),
                      c(0x6), c(0x7), c(0x8), c(0x9), c(0xa), c(0xb),
                      c(0xc), c(0xd), c(0xe), c(0xf)};
const uint8_t bt[] = {b(0x0), b(0x1), b(0x2), b(0x3)};
const uint8_t ft[] = {f(0x0), f(0x1), f(0x2), f(0x3),
                      f(0x4), f(0x5), f(0x6), f(0x7)};
#undef c
#define c(inst) (ct[inst & 0b1111])
#undef b
#define b(inst) (bt[inst & 0b11])
#undef f
#define f(inst) (ft[inst & 0b111])
#endif
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

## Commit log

2025-02-18 Prototype teaser pic.
2025-02-23 Gerbers and NEO ONLY firmware for now.
    [professordisplay-B_Cu.gbr, professordisplay-B_Mask.gbr, professordisplay-B_Paste.gbr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]
2025-02-23 NEO ONLY firmware for now. Gerbers.
    [professordisplay-B_Cu.gbr, professordisplay-B_Mask.gbr, professordisplay-B_Paste.gbr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]
2025-02-23 README update - including links / references to required Arduino libraries.
2025-02-24 Adding BOM to README.
2025-02-24 BOM update (1N4001).
2025-02-24 README BOM update.
2025-02-24 README BOM fix.
2025-02-28 README update, and swapping in "Towers of Hanoi" for demoe program PGM 8.
    [microtronic-phoenix-neo-only.ino]
2025-02-28 New Phoenix picture with red lens filter.
2025-02-28 Gerbers - silkscreen bugfix, and adding the thermal cooling zone for the 7805 which accidentially got deleted in the last PCB revision.
2025-03-01 Adding Heatsinks to the BOM.
2025-03-14 Adding display adapter gerbers for SH3661Ax displays.
2025-08-24 Filter advice from venice1200.
2025-08-24 Filter advice from venice1200
2026-10-07 Built-in Primes program: fix address 59 (D58 -> D5B), as verified against the printed listing
    Source only; flashed firmware is unchanged until rebuilt.
    Claude-Session: https://claude.ai/code/session_01RRZMkeXQShygyYhWuUdVNF
    [Microtronic-Phoenix.ino, microtronic-phoenix-neo-only.ino, microtronic-phoenix.ino]
2026-11-04 Latest News: three honorable mentions, including the VZ-200 Lazarus board
    Claude-Session: https://claude.ai/code/session_01Dmr5bx55ABiFD19Bm9dsjF

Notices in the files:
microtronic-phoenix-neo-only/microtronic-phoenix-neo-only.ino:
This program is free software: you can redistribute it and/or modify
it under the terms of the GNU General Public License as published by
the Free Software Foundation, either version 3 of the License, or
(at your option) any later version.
